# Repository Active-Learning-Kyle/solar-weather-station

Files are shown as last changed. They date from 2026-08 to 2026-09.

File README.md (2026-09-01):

# Solar Weather Station

<p align="center">
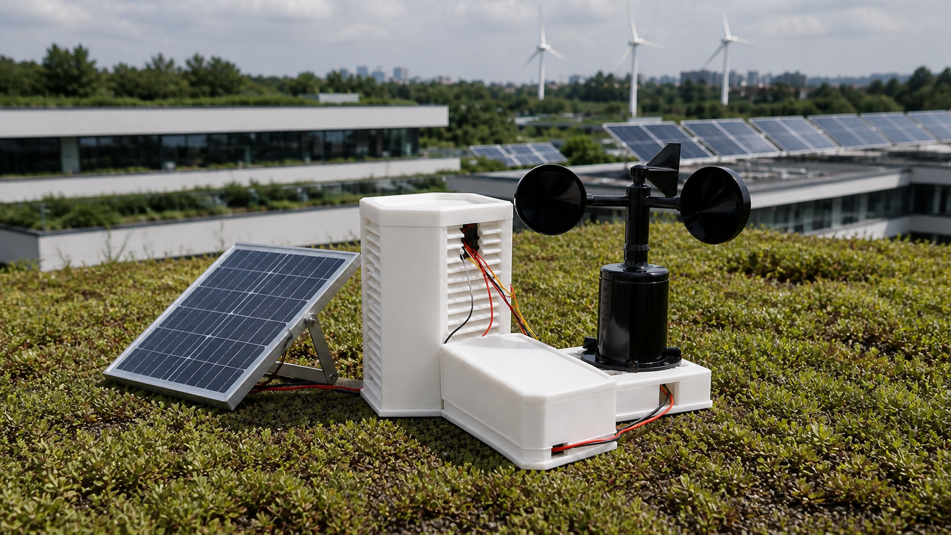
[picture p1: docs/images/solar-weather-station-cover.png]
Solar Weather Station prototype with its solar panel, cup anemometer and wind vane on a green rooftop
  
</p>

<p align="center">
  <strong>Make invisible microclimates visible—so greener campus decisions can be based on local evidence.</strong>
</p>

<p align="center">
  A solar-powered station for investigating how heat, light, particles and wind vary across the places where people study, work and grow plants.
</p>

<p align="center">
  
  
  
  
  
</p>

<p align="center"><sub>Application visualisation based on the completed prototype. Field performance still requires the tests described in this repository.</sub></p>

## The problem: one forecast cannot describe every place

A city-wide forecast can tell us the general weather, but it cannot describe every rooftop garden, shaded courtyard, workshop entrance or sun-heated wall. Two places only a short walk apart may experience different temperature, light, particles and wind. Without local evidence, decisions about shade, planting, ventilation, outdoor activities and equipment placement can easily be based on assumption.

That creates a more interesting engineering question than simply displaying sensor values:

> **Can a repairable, solar-powered station produce trustworthy local evidence for deciding where and when a campus space needs environmental improvement?**

The Solar Weather Station grew from that question. It is designed to compare conditions between small campus locations and over time, while keeping sensor failures and uncertainty visible. A useful outcome is not simply a dashboard: it is evidence that can support a specific decision, such as whether a rooftop growing area needs shade, whether a courtyard needs further heat investigation, or whether a proposed monitoring location is representative.

The aim is not to imitate a certified meteorological station or claim that one prototype solves urban climate change. The aim is to create an honest local evidence tool—one verified subsystem and one decision at a time.

## Green Technology and the SDGs

<table>
  <tr>
    <td align="center" width="33%">
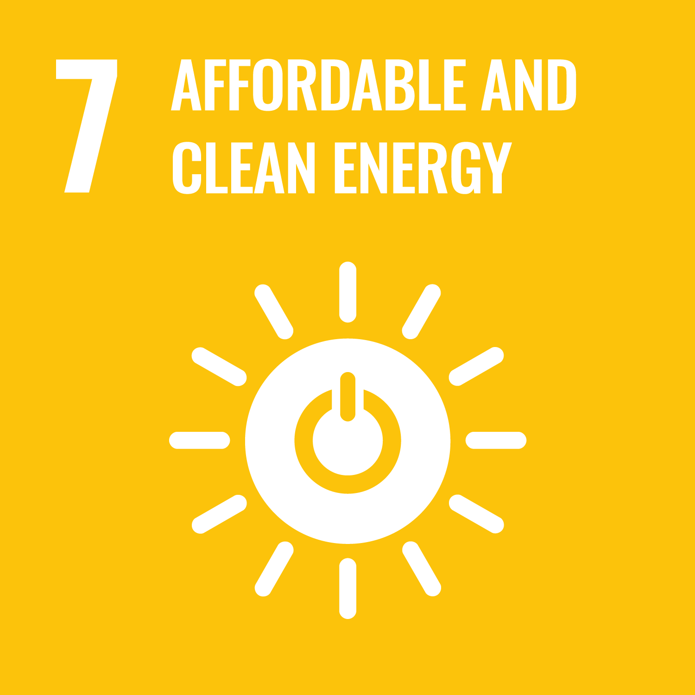
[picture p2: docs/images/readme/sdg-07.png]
SDG 7 Affordable and Clean Energy
      <br>
      <strong>SDG 7 · Affordable and Clean Energy</strong><br>
      <sub>The station tests whether local monitoring can run from a measured solar-energy budget. Power demand, charging loss and endurance are recorded before autonomy is claimed.</sub>
    </td>
    <td align="center" width="33%">
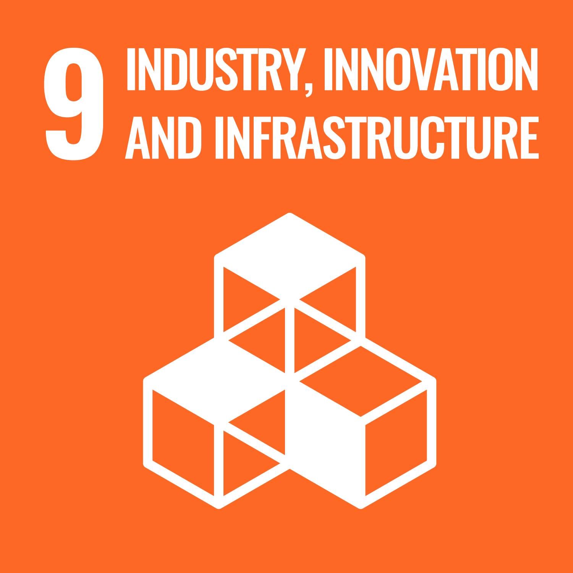
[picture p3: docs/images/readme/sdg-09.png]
SDG 9 Industry Innovation and Infrastructure
      <br>
      <strong>SDG 9 · Industry, Innovation and Infrastructure</strong><br>
      <sub>Editable CAD, modular firmware and an open data path make the monitoring infrastructure repairable, reproducible and adaptable to another site.</sub>
    </td>
    <td align="center" width="33%">
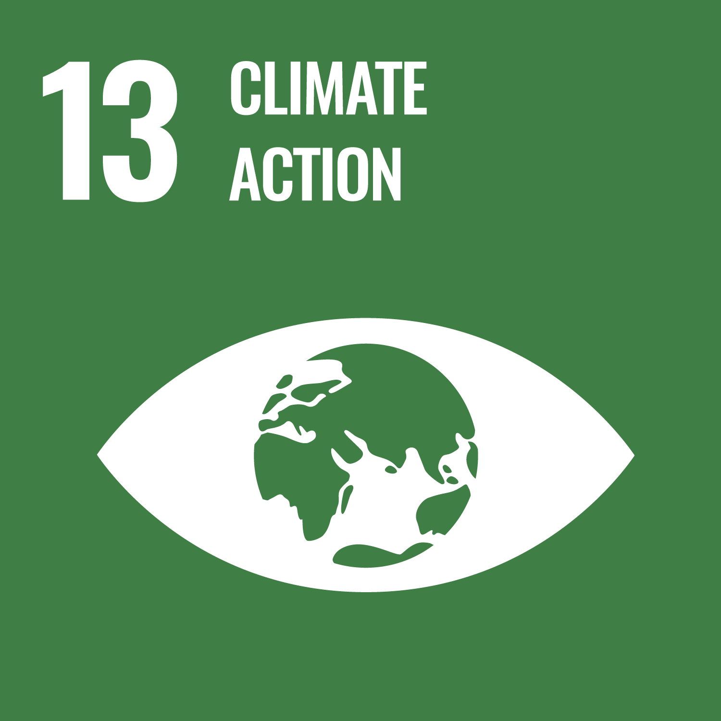
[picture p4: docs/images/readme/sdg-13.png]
SDG 13 Climate Action
      <br>
      <strong>SDG 13 · Climate Action</strong><br>
      <sub>Hyperlocal observations can reveal heat, exposure and weather patterns that inform a campus adaptation decision. Impact begins only when the evidence changes an action.</sub>
    </td>
  </tr>
</table>

Together, the three goals form one testable chain: **power the sensing responsibly (SDG 7), leave behind reusable monitoring infrastructure (SDG 9), and use its evidence to inform local climate adaptation (SDG 13).** Sustainability still depends on measured power, materials, repairability, useful lifetime, placement and a documented decision enabled by the data.

## From a physical prototype to usable evidence

<table>
  <tr>
    <td width="42%" valign="top">
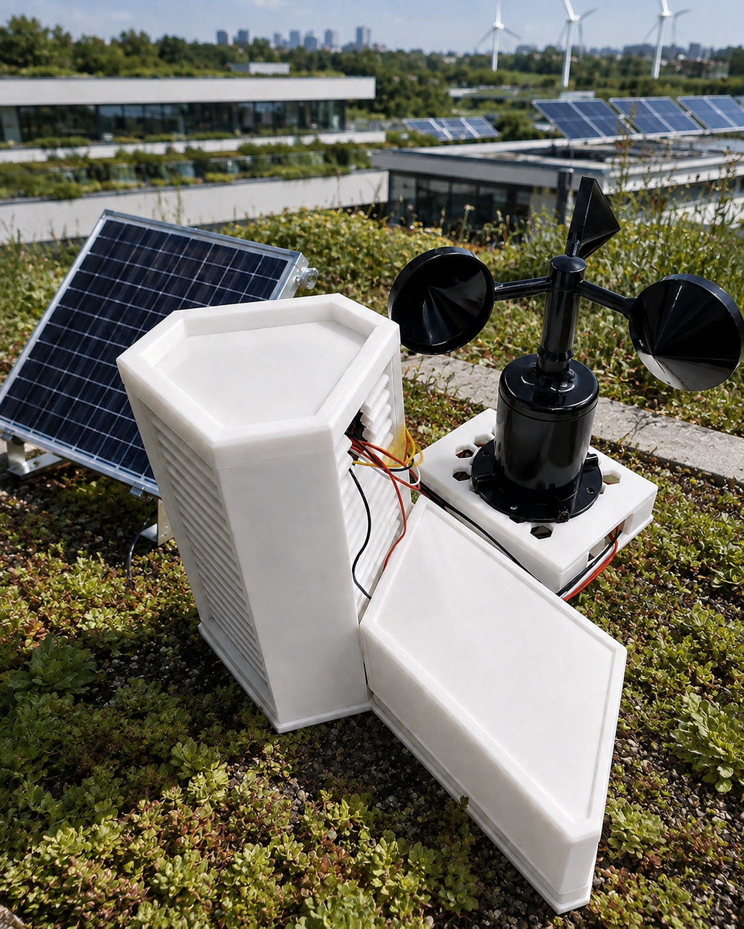
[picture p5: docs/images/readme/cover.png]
Completed white 3D-printed Solar Weather Station with RS485 wind sensor
      <br>
      <sub><strong>The physical system.</strong> A modular 3D-printed sensor body and power enclosure with an ESP32-S3, environmental sensors, GNSS and RS485 wind speed.</sub>
    </td>
    <td width="58%" valign="top">
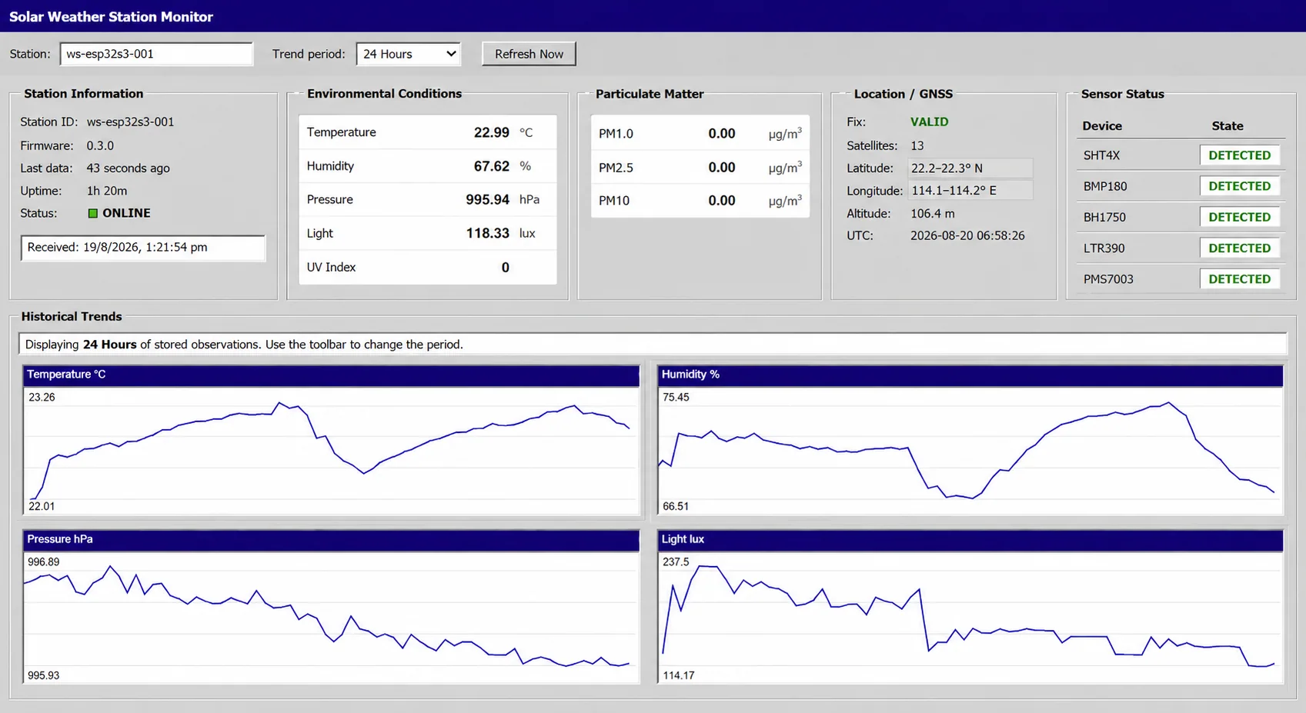
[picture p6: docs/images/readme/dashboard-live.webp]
Live Solar Weather Station dashboard with current readings, sensor status, GNSS and historical trends
      <br>
      <sub><strong>The data system.</strong> Current conditions, sensor health, GNSS state and historical trends served by FastAPI and SQLite.</sub>
    </td>
  </tr>
</table>

The station currently measures:

- temperature and relative humidity;
- barometric pressure;
- ambient light and an estimated UV index;
- PM1.0, PM2.5 and PM10 particulate concentration;
- GNSS communication, fix state, time, position, altitude, satellites and motion; and
- RS485 wind speed.

A valid calm wind reading of `0.0 m/s` remains different from a timeout. A missing GNSS fix remains different from a disconnected receiver. Each active sensor keeps its own initialized, valid, stale and failure state, so one failed device does not stop the rest of the station.

## How the complete system works

```mermaid
flowchart LR
    subgraph Station[ESP32-S3 station]
      I2C[SHT4x · BMP180<br/>BH1750 · LTR390]
      PMS[PMS7003]
      GPS[TEL0157 / L76K GNSS]
      WIND[RS485 wind speed]
      HEALTH[WeatherData<br/>validity + health]
      I2C --> HEALTH
      PMS --> HEALTH
      GPS --> HEALTH
      WIND --> HEALTH
    end

    HEALTH -->|USB Serial| OBSERVE[Bench diagnosis]
    HEALTH -->|Wi-Fi · JSON · HTTP| API[FastAPI validation]
    API --> DB[(SQLite history)]
    DB --> UI[Live dashboard<br/>and trends]
```

Sensor acquisition is scheduled independently of networking. Wi-Fi reconnects and uploads use bounded timing, so a missing backend does not stop local sensing. HTTP keeps the development path small and inspectable; it is not a claim of secure public-cloud deployment.

## Look inside, not only at the finished enclosure

<table>
  <tr>
    <td width="50%" valign="top">
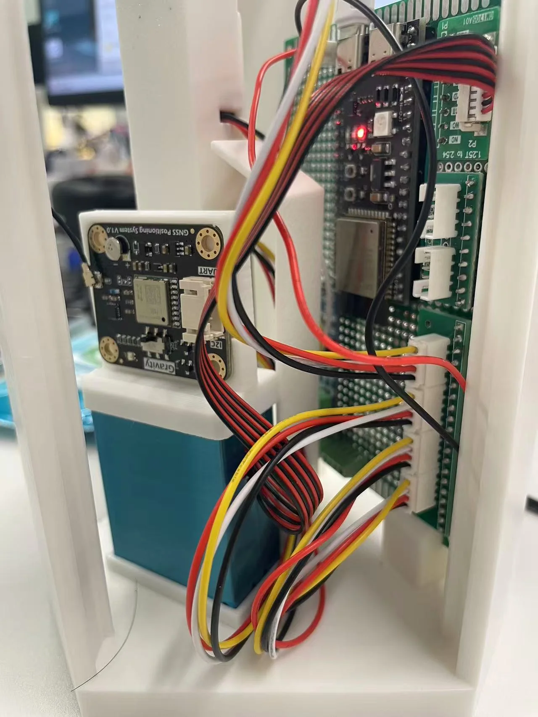
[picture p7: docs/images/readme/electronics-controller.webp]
ESP32-S3 controller, interface board and internal weather station wiring
      <br>
      <sub>ESP32-S3, interface board, connectors and routed sensor wiring inside the printed body.</sub>
    </td>
    <td width="50%" valign="top">
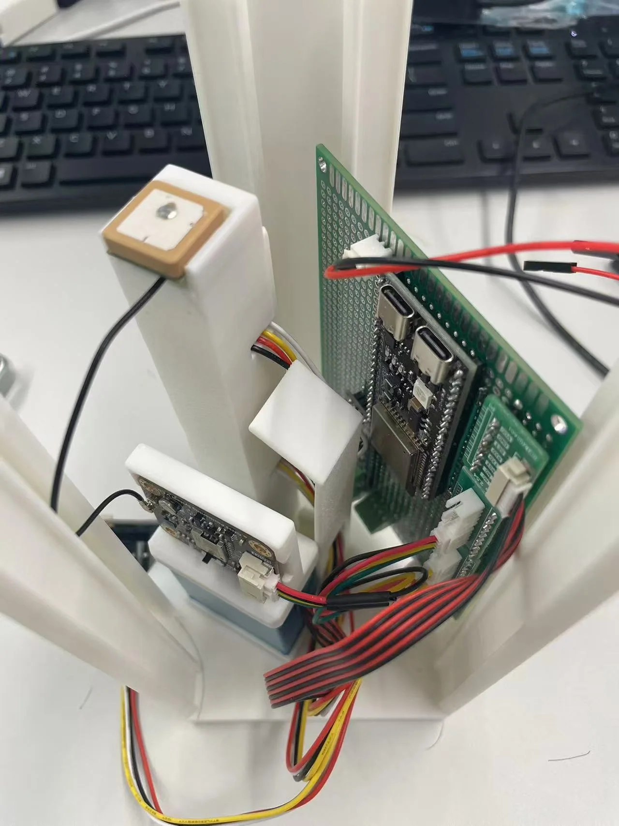
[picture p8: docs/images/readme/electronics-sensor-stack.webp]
Weather station internal GNSS and environmental sensor modules
      <br>
      <sub>GNSS and environmental sensing modules on printed mounts designed for inspection and replacement.</sub>
    </td>
  </tr>
</table>

The enclosure is organised as two connected modules:

1. the **Weather Station Body**, which holds sensing and control electronics; and
2. the **Power Module**, separated so that energy storage and charging can be revised without rebuilding the entire sensor body.

Exact breakout boards, voltage requirements, connector families and outdoor protection still need to be checked before reproducing the hardware. Start with the [bill of materials](hardware/bom.md), [wiring guide](hardware/wiring.md), [pin allocation](docs/pin-allocation.md) and [power notes](hardware/power-system.md).

## Designed to be changed

<p align="center">
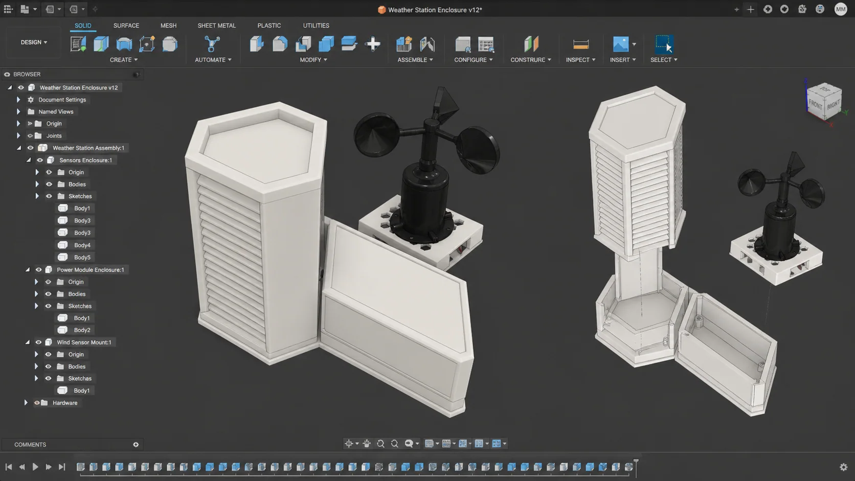
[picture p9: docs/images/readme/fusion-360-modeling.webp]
Fusion 360 design workspace showing the weather station enclosure, wind sensor mount and modular assembly
  
</p>

<p align="center"><sub>Design-process visualisation based on the included editable Fusion 360 models and the printed enclosure.</sub></p>

The repository includes editable `.f3d` source for the sensor body, vents, sensor rod, GNSS mount, power enclosure and connecting base. That matters because a reusable project should allow another team to change a mount, airflow path or cable route—not only print an uneditable final mesh.

<table>
  <tr>
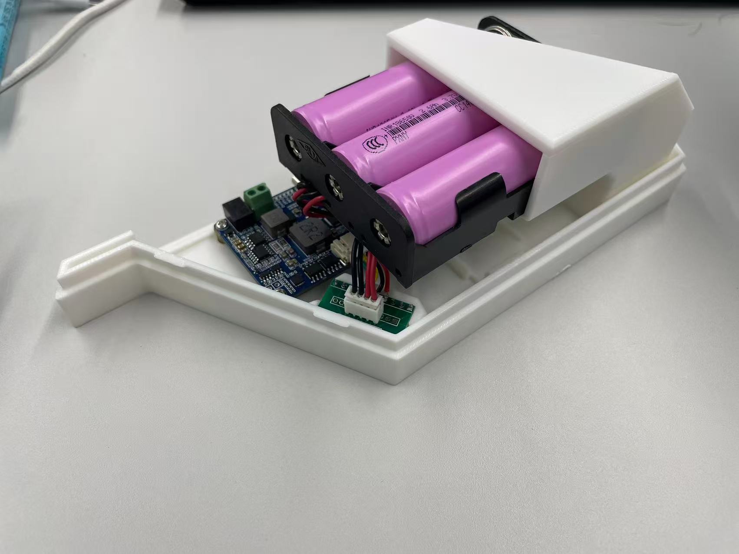
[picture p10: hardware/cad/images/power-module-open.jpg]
Open power module with battery and electronics
    <td width="50%"></td>
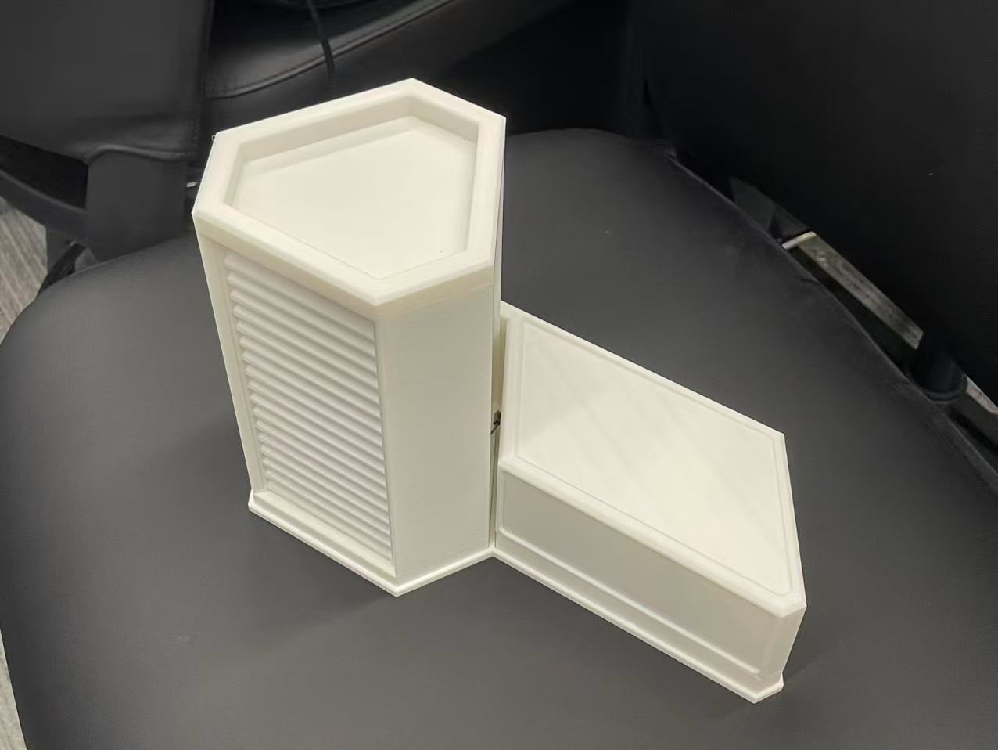
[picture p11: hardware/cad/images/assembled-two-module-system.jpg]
Printed weather station and power modules joined by the connecting base
    <td width="50%"></td>
  </tr>
  <tr>
    <td><sub>Power module opened for inspection.</sub></td>
    <td><sub>Printed modules assembled on the connecting base.</sub></td>
  </tr>
</table>

- Browse the [mechanical CAD catalogue](hardware/cad/README.md).
- Prepare the files with the [3D-printing guide](hardware/printing/README.md).
- Assemble the modules with the [mechanical assembly guide](hardware/printing/assembly-guide.md).

## Current release

**Core v0.4 integrates wind speed through the complete software path.** The standalone wind-speed diagnostic has been verified on hardware. The combined station still requires the documented full-system hardware test before v0.4 can be called field verified.

| Area | Current status | Evidence |
| --- | --- | --- |
| SHT4x, BMP180, BH1750, LTR390 and PMS7003 | **Hardware verified** | [Core v0.1 milestone](docs/milestones/v0.1-core-sensors.md) |
| Wi-Fi, HTTP, FastAPI, SQLite and dashboard | **Complete for Core v0.2** | [Core v0.2 milestone](docs/milestones/v0.2-connected-iot.md) |
| TEL0157/L76K GNSS | **Hardware verified and integrated** | [Core v0.3 milestone](docs/milestones/v0.3-gnss-integration.md) |
| RS485 wind speed | **Software integrated; combined hardware test pending** | [Core v0.4 milestone](docs/milestones/v0.4-wind-speed-integration.md) |
| RS485 wind direction | **Standalone diagnostic only** | [Firmware environments](#firmware-environments) |
| Mechanical enclosure and connecting base | **Printed and fit checked** | [Mechanical CAD](hardware/cad/README.md) |
| Rain, battery and solar telemetry | **Planned** | [Roadmap](#where-the-project-can-go-next) |
| Weatherproofing and long-duration outdoor operation | **Not yet verified** | [Field readiness](tests/field-readiness-checklist.md) |

The terms used throughout the repository have fixed meanings:

- **Planned:** no implementation is claimed.
- **Software implemented:** code exists and its software checks are stated.
- **Diagnostic available:** an isolated test exists; main-system integration is not implied.
- **Hardware verified:** the named behaviour was observed on the stated hardware using a recorded procedure.
- **Complete:** the acceptance result for the named milestone was observed.

## Build the software path

### 1. Clone the repository

```powershell
git clone https://github.com/Active-Learning-Kyle/solar-weather-station.git
cd solar-weather-station
```

### 2. Configure and build the ESP32-S3 firmware

Install [Visual Studio Code](https://code.visualstudio.com/) and [PlatformIO](https://platformio.org/), then create the ignored local secrets file:

```powershell
Copy-Item firmware/include/secrets.example.h firmware/include/secrets.h
```

Set the local Wi-Fi credentials and backend URL in `firmware/include/secrets.h`, then build:

```powershell
cd firmware
pio run -e weather_station
```

Upload and monitor when the hardware is connected:

```powershell
pio run -e weather_station -t upload
pio device monitor -b 115200
```

### 3. Start the local backend and dashboard

Open a second terminal from the repository root:

```powershell
cd backend
py -3.11 -m venv .venv
.\.venv\Scripts\python.exe -m pip install -r requirements.txt
.\.venv\Scripts\python.exe -m uvicorn app.main:app --host 0.0.0.0 --port 8000
```

Open [http://localhost:8000](http://localhost:8000). Interactive API documentation is available at [http://localhost:8000/docs](http://localhost:8000/docs).

### 4. Run the automated tests

```powershell
cd backend
.\.venv\Scripts\python.exe -m pytest -q
```

Continuous integration builds every PlatformIO environment and runs the backend test suite. A successful build proves that the software compiles; it does not replace hardware verification.

## Firmware environments

Run an isolated diagnostic before integrating a new or failing subsystem.

| Environment | Purpose |
| --- | --- |
| `weather_station` | Core v0.4 integrated firmware |
| `diag_i2c` | Detect the shared I²C sensors and addresses |
| `diag_pms` | Inspect PMS7003 frames, checksums and values |
| `diag_gnss` | Inspect GNSS communication, NMEA data and fix state |
| `diag_wind_speed` | Test the verified RS485 wind-speed protocol |
| `diag_wind_direction` | Preserve and investigate the wind-direction protocol |

For GNSS diagnostics:

```powershell
cd firmware
pio run -e diag_gnss -t upload
pio device monitor -b 115200
```

## Backend API

| Method | Endpoint | Purpose |
| --- | --- | --- |
| `POST` | `/api/v1/measurements` | Validate and store one station snapshot |
| `GET` | `/api/v1/measurements/latest?station=...` | Return the latest snapshot |
| `GET` | `/api/v1/measurements?station=...&start=...&end=...&limit=...` | Return filtered history, newest first |

The backend receive time controls storage order and dashboard freshness. Device time remains nullable until NTP succeeds. GNSS time is stored independently after a valid fix. Precise GNSS data must not be exposed through an untrusted network or published without review.

## Follow the engineering journey

The project records six connected decisions. Evidence may send the work back to an earlier Gate.

| Gate | Decision | Main record |
| ---: | --- | --- |
| 01 **Focus** | Which Green Technology challenge is worth pursuing? | [Challenge focus](docs/project-journey/01-focus.md) |
| 02 **Define** | What problem, user and evidence boundary define the work? | [Problem definition](docs/project-journey/02-define.md) |
| 03 **Plan** | Which architecture and validation route should be used? | [Proposal and plan](docs/project-journey/03-plan.md) |
| 04 **Learn** | What can be rebuilt and understood from existing open projects? | [Open references and working versions](docs/project-journey/04-learn.md) |
| 05 **Improve** | What should be adapted or improved for this problem, based on evidence? | [Testing and iteration](docs/project-journey/05-improve.md) |
| 06 **Contribute** | What can another person safely understand, reproduce and extend? | [Responsible release](docs/project-journey/06-contribute.md) |

The [project-journey index](docs/project-journey/README.md) connects these decisions to milestone records, code, CAD, tests and release checks.

### Learn from open work before designing from zero

This station was not developed in isolation. Three public projects were studied as working precedents:

- [SeBassTian23/ESP32-WeatherStation](https://github.com/SeBassTian23/ESP32-WeatherStation) showed how particulate matter, UV-related sensing, solar power and local logging can coexist in an ESP32 station.
- [cerevisis/ESP32-Weather-Station](https://github.com/cerevisis/ESP32-Weather-Station) demonstrated a device-hosted dashboard, historical records, sensor diagnostics and extensible weather interfaces.
- [maxmacstn/HA-SolarWeatherStation](https://github.com/maxmacstn/HA-SolarWeatherStation) provided a useful precedent for solar operation, deep sleep, battery-aware behaviour and separating sensing from the protected electronics enclosure.

The purpose of studying them was not to combine every feature. It was to rebuild enough of the established pattern to understand its trade-offs, then make a problem-specific improvement: explicit per-sensor health, a local inspectable data path, editable modular hardware and evidence boundaries that distinguish a real zero reading from missing or unverified data. Their code and hardware remain under their respective licences; this repository records the ideas studied and the new work developed here.

## Start with the part you want to change

| If you want to… | Start here |
| --- | --- |
| reproduce the current system | [Wiring](hardware/wiring.md) → [firmware setup](#build-the-software-path) → [backend](#3-start-the-local-backend-and-dashboard) |
| diagnose a missing sensor | [Firmware environments](#firmware-environments) → [troubleshooting](docs/troubleshooting.md) |
| understand a version | [Milestone records](docs/milestones/) → matching `core-v0.*.md` implementation notes |
| modify the enclosure | [CAD catalogue](hardware/cad/README.md) → [printing](hardware/printing/README.md) → [assembly](hardware/printing/assembly-guide.md) |
| design a field test | [Test matrix](tests/test-matrix.csv) → [field-readiness checklist](tests/field-readiness-checklist.md) |
| contribute a change | [Contributing guide](CONTRIBUTING.md) → open an Issue → submit a focused Pull Request |

## Evidence and claim boundaries

This repository distinguishes code, bench evidence and field evidence.

- Photographs show the named assembly or bench setup. They do not prove calibration, weatherproofing or long-term reliability.
- Automated tests validate API, storage, migration and dashboard behaviour. They do not prove sensor accuracy.
- A standalone diagnostic verifies one interface. It does not prove that the complete station works outdoors.
- The LTR390 value is an estimate from the current driver path, not a calibrated meteorological UV measurement.
- GNSS screenshots are redacted or reduced in precision before publication.
- Sustainability value must be supported by measured power, lifetime, repair and field evidence. The presence of a solar panel or SDG label is not proof of impact.

Use the [test matrix](tests/test-matrix.csv) to see which claims are supported, pending or explicitly outside the current release.

## Safety and privacy

Outdoor electrical systems, rechargeable cells, 12 V instruments, fabrication tools and elevated mounting introduce hazards. Use an approved site, named supervision, appropriate protection, strain relief, fusing, stop conditions and a safe retrieval plan. Do not energise an enclosure during a water-ingress test.

The backend is not hardened for the public internet. Keep it on a trusted network. Remove credentials, private endpoints and precise location data before sharing logs or screenshots. See [SECURITY.md](SECURITY.md) and the [field-readiness checklist](tests/field-readiness-checklist.md).

## Where the project can go next

The current system leaves several useful directions open:

- complete the Core v0.4 combined hardware verification;
- decide whether wind direction should enter the production data model;
- add rain, battery and solar telemetry after isolated tests pass;
- measure the complete power profile and solar energy balance;
- validate enclosure ingress, thermal behaviour and radiation shielding;
- compare selected measurements with a documented reference instrument;
- design a lower-power duty cycle for autonomous operation; or
- adapt the modular platform to a different local environmental question.

The most valuable next feature is not necessarily the most impressive one. It is the one supported by a clear need, a testable decision and evidence that changes what the team does next.

## Contributing

Contributions are welcome. Open an Issue for a bug, proposed subsystem or design decision, then use a focused branch and Pull Request. State what was compiled, simulated, bench tested or field tested. Do not describe planned work as verified.

Read [CONTRIBUTING.md](CONTRIBUTING.md), [AI_USE.md](AI_USE.md) and [THIRD_PARTY.md](THIRD_PARTY.md) before submitting a change.

## License

This project is released under the [MIT License](LICENSE). Third-party libraries remain under their own licences and are not relicensed by this repository. The editable source, evidence and known limitations are published so that another team can understand the work, reproduce what has been verified and improve it responsibly.

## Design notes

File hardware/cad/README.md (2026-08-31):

# Mechanical CAD index

The enclosure is a two-assembly prototype: the vertical **Weather Station Body** contains the ESP32-S3, sensor interfaces, PMS7003, GNSS hardware, and the sensor rod; the horizontal **Power Module** contains the 18650 battery pack, Waveshare Solar Power Manager (D), and XL6009 DC-DC module. The two assemblies are joined by a **Connecting Base**.

Printed weather-station body and power module joined as one prototype

The ten editable source models are Autodesk Fusion 360 archives (`.f3d`). Fusion 360 is the released editable format so builders can inspect and modify the design. No STL, 3MF, or STEP exports were supplied. Open a model in Fusion 360, confirm its document units, and export a mesh for your slicer without changing scale.

## Directory layout

```text
hardware/cad/
├── station-body/       # seven editable station-body parts
├── power-module/       # mount and cover
├── assembly/           # editable connecting base and part documentation
└── images/             # CAD previews and physical-build evidence
```

## Part catalog

“Photo assembled” means the part is visible or its installed function is evidenced in the supplied prototype photographs. It is not a dimensional inspection or a field-weatherproofing claim.

| Assembly | Part | Qty. | Editable CAD | Preview | Function | Evidence status |
| --- | --- | ---: | --- | --- | --- | --- |
| Weather Station Body | Main body shell | 1 | [`station-body/main-body-shell.f3d`](station-body/main-body-shell.f3d) | [`main-body-shell-cad.png`](images/main-body-shell-cad.png) | Primary vertical enclosure and internal mounting structure | Photo assembled |
| Weather Station Body | Lid | 1 | [`station-body/lid.f3d`](station-body/lid.f3d) | [`lid-cad.png`](images/lid-cad.png) | Closes the top of the main shell | Photo assembled |
| Weather Station Body | Vent | 3 | [`station-body/vent.f3d`](station-body/vent.f3d) | [`vent-cad.png`](images/vent-cad.png) | Inserts into the three open sides of the shell | Photo assembled; weatherproofing not validated |
| Weather Station Body | Sensor rod | 1 | [`station-body/sensor-rod.f3d`](station-body/sensor-rod.f3d) | [`sensor-rod-cad.png`](images/sensor-rod-cad.png) | Holds the smaller environmental sensors; GNSS antenna sits at the top | Photo assembled |
| Weather Station Body | Sensor-rod lid | 1 | [`station-body/sensor-rod-lid.f3d`](station-body/sensor-rod-lid.f3d) | [`sensor-rod-lid-cad.png`](images/sensor-rod-lid-cad.png) | Fits into the sensor rod to stabilize installed sensors | Included in source; not independently visible in the photos |
| Weather Station Body | Cable slot | 1 | [`station-body/cable-slot.f3d`](station-body/cable-slot.f3d) | [`cable-slot-cad.png`](images/cable-slot-cad.png) | Organizes sensor wiring | Included in source; not independently identifiable in the photos |
| Weather Station Body | GNSS mount | 1 | [`station-body/gnss-mount.f3d`](station-body/gnss-mount.f3d) | [`gnss-mount-cad.png`](images/gnss-mount-cad.png) | Supports the GNSS board above the PMS7003 | Photo assembled |
| Power Module | Power-module mount | 1 | [`power-module/power-module-mount.f3d`](power-module/power-module-mount.f3d) | [`power-module-mount-cad.png`](images/power-module-mount-cad.png) | Holds the battery pack and power boards | Photo assembled |
| Power Module | Power-module cover | 1 | [`power-module/power-module-cover.f3d`](power-module/power-module-cover.f3d) | [`power-module-cover-cad.png`](images/power-module-cover-cad.png) | Closes the power-module mount | Photo assembled |
| Combined assembly | Connecting base | 1 | [`assembly/connecting-base.f3d`](assembly/connecting-base.f3d) | [`connecting-base-cad.png`](images/connecting-base-cad.png) | Joins the station body to the power module | Designed, printed, fit verified, and integrated |

## Printing rule

Every released part in the catalog is printed in PLA using the normal/default PLA profile with supports enabled. The Power Module Mount is the sole documented material exception: its model remains PLA, while its support system uses the dedicated `Support for PLA` material. No support-interface configuration or numeric slicer settings are specified because none were supplied.

## Source-name normalization

The supplied files were copied into the repository with descriptive, lowercase, hyphenated names. The source folder remains unchanged.

| Supplied name | Repository name |
| --- | --- |
| `mainbodyshell.f3d` | `station-body/main-body-shell.f3d` |
| `Lid.f3d` | `station-body/lid.f3d` |
| `vent.f3d` | `station-body/vent.f3d` |
| `sensorrod.f3d` | `station-body/sensor-rod.f3d` |
| `rodlid.f3d` | `station-body/sensor-rod-lid.f3d` |
| `cableslot.f3d` | `station-body/cable-slot.f3d` |
| `gpsmount.f3d` | `station-body/gnss-mount.f3d` |
| `powermodulemount.f3d` | `power-module/power-module-mount.f3d` |
| `powermodulecover.f3d` | `power-module/power-module-cover.f3d` |
| `connectbase.f3d` | `assembly/connecting-base.f3d` |

## Visual evidence

- [`station-body-assembled-front.jpg`](images/station-body-assembled-front.jpg) — completed station-body exterior.
- [`station-body-internal-sensors.jpg`](images/station-body-internal-sensors.jpg) — sensor rod and PMS7003/GNSS area.
- [`station-body-internal-electronics.jpg`](images/station-body-internal-electronics.jpg) — installed ESP32-S3, interface board, and wiring.
- [`power-module-open.jpg`](images/power-module-open.jpg) — battery pack and power electronics on the open mount.
- [`power-module-closed.jpg`](images/power-module-closed.jpg) — installed cover.
- [`assembled-two-module-system.jpg`](images/assembled-two-module-system.jpg) — both assemblies joined by the printed connecting base.

The physical photographs and connecting-base render were extracted from the supplied 14-page Word reference. The individual CAD previews came from the matching source-folder screenshots.

## Known gaps

- Record Fusion document units and export tested STL or 3MF files before calling the print package turnkey-reproducible.
- Record dimensions, tolerances, fastening/adhesive method, print orientation, and slicer settings after a controlled reprint.
- Validate enclosure drainage, sealing, UV/heat resistance, and long-duration outdoor fit. The reference calls the vents waterproof, but no test evidence supports that claim.
- Confirm whether future manufacturing exports need a dedicated open-hardware licence in addition to the repository-wide MIT License. Until that decision is recorded, describe the editable CAD as source material rather than a certified, turnkey open-hardware package.

See the [printing guide](../printing/README.md), [assembly guide](../printing/assembly-guide.md), and milestone records for [v0.1](../../docs/milestones/v0.1-core-sensors.md), [v0.2](../../docs/milestones/v0.2-connected-iot.md), and [v0.3](../../docs/milestones/v0.3-gnss-integration.md).

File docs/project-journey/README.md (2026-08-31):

# Project Journey

The Solar Weather Station develops through six connected engineering decisions. The Gates are not a one-way checklist. New evidence can change an earlier problem statement, architecture choice, test or release decision.

| Gate | Decision | Current outcome |
| ---: | --- | --- |
| [01 Focus](01-focus.md) | Which Green Technology challenge should the project pursue? | Build an inspectable local microclimate platform while keeping sustainability claims evidence based |
| [02 Define](02-define.md) | What problem, user and boundary define useful work? | Support supervised, site-specific observation and engineering validation; do not claim meteorological-grade accuracy |
| [03 Plan](03-plan.md) | Which system architecture and validation route are responsible? | Modular ESP32-S3 sensing, isolated diagnostics, local backend and staged integration |
| [04 Learn](04-learn.md) | What did each working version teach? | Four milestones moved from core sensors to connected data, GNSS and wind speed |
| [05 Improve](05-improve.md) | What does the evidence justify changing next? | Finish combined v0.4 verification before adding new field features |
| [06 Contribute](06-contribute.md) | What is safe, clear and useful to release? | Publish source, editable CAD, tests, evidence, limits and contribution rules under an open licence |

## Evidence path

```mermaid
flowchart LR
    F[Focus] --> D[Define]
    D --> P[Plan]
    P --> L[Learn]
    L --> I[Improve]
    I --> C[Contribute]
    I -. new evidence .-> D
    C -. reproduction feedback .-> P
```

The detailed implementation record remains chronological under [`docs/milestones/`](../milestones/). The Gate documents explain the decisions across those versions; the milestone documents show what was built and observed at each stage.

## How to read the evidence

- **Source code** shows an implementation, not physical performance.
- **Automated tests** show that software behavior meets the checked conditions.
- **Diagnostic logs and bench photographs** support the named subsystem test.
- **Integrated hardware evidence** supports only the configuration and procedure recorded in that milestone.
- **Field claims** require an approved site, versioned configuration, raw observations, reference information and a recorded decision.

The [system test matrix](../../tests/test-matrix.csv) is the index of supported and pending claims.

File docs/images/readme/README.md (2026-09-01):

# README Visual Assets

This folder separates project evidence from explanatory visualisations.

## Project photographs and interface capture

- `cover.png` — completed physical prototype supplied by the project owner.
- `dashboard-live.webp` — live project dashboard capture supplied by the project owner.
- `electronics-controller.webp` — internal controller, interface board and wiring photograph supplied by the project owner.
- `electronics-sensor-stack.webp` — internal GNSS and sensor-mount photograph supplied by the project owner.

These images document the visible configuration only. They do not by themselves prove calibration, weatherproofing, field reliability or solar autonomy.

## Explanatory visualisations

- `application-rooftop.webp` — AI-generated application visualisation derived from the completed-prototype photograph. It illustrates an intended supervised rooftop use case and is not field-test evidence.
- `fusion-360-modeling.webp` — AI-generated design-process visualisation derived from the printed enclosure and assembled prototype. The repository's `.f3d` files, not the visualisation, are the editable CAD source.

Both visualisations were reviewed against the supplied prototype references before publication. No generated visual is used as evidence in the test matrix.

## SDG communication assets

- `sdg-07.png`, `sdg-09.png` and `sdg-13.png` come from the United Nations Sustainable Development communications materials.
- Source: <https://www.un.org/sustainabledevelopment/news/communications-material/>
- Use must follow the UN SDG logo, colour wheel and icon guidelines linked on that page.
- Inclusion does not imply United Nations endorsement or prove project impact.

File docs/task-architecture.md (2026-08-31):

# FreeRTOS Task Architecture (Early Proposal)

> **Status:** Historical/planned design, not the v0.3 runtime architecture. The current implementation uses the `main.cpp` scheduler plus dedicated HTTP-upload and GNSS workers. See the [README architecture](../README.md#architecture) and [v0.3 milestone](milestones/v0.3-gnss-integration.md).

## Data Flow

```text
Sensor drivers
    ↓
SensorManagerTask / WindPollTask / RainTask
    ↓
WeatherData queue + latest reading mutex
    ↓
StatisticsTask ──→ hourly/daily aggregates
    ↓
DataLoggerTask ──→ CSV/JSON storage
    ↓
CommunicationTask ──→ MQTT + REST sync
    ↓
Dashboard API ──→ browser UI
```

## Shared Data Objects

```cpp
struct WeatherData
{
    float temperature;
    float humidity;
    float pressure;
    float lightLux;
    float uvIndex;
    float pm1_0;
    float pm2_5;
    float pm10;
    float windSpeed;
    float windDirection;
    float rainfall;
    double latitude;
    double longitude;
    uint64_t timestamp;
};
```

Recommended synchronization:

| Shared Resource | Protection |
| --- | --- |
| Latest `WeatherData` | Mutex |
| Log queue | FreeRTOS queue |
| MQTT publish queue | FreeRTOS queue |
| Rain pulse counter | ISR-safe atomic or critical section |
| Sensor diagnostics | Mutex or immutable snapshot queue |
| Configuration | Preferences with mutex |

## Task Details

| Task | Trigger | Output |
| --- | --- | --- |
| SensorManagerTask | 30 s periodic timer | Latest weather snapshot, publish/log queue entries |
| WindPollTask | 10 s periodic timer | Wind speed/direction fields |
| RainTask | 10 s periodic timer plus ISR count | Rain rate, daily/monthly accumulation |
| StatisticsTask | 60 s periodic timer | Hourly and daily rollups |
| DataLoggerTask | Queue-driven | CSV/JSON files |
| CommunicationTask | Queue-driven plus reconnect timer | MQTT publishes and NTP updates |
| WebServerTask | HTTP events | Dashboard/API responses |
| OtaTask | HTTP/OTA events | Firmware update |
| SystemHealthTask | 30 s periodic timer | Diagnostics and status payload |

## Timing Rules

- Use `vTaskDelayUntil()` for periodic tasks.
- Avoid blocking delays in sensor drivers.
- PMS7003 may need wake and stabilization timing; model this with a small state machine.
- RS485 polling should include timeouts and retries without blocking the full sensor manager.
- Network reconnects should use exponential backoff.

## Failure Handling

| Failure | Behavior |
| --- | --- |
| Sensor read timeout | Keep previous valid value, flag diagnostic warning |
| Sensor repeated failure | Mark sensor error, continue system operation |
| WiFi disconnected | Buffer readings locally, reconnect with backoff |
| MQTT unavailable | Continue REST/dashboard, queue or drop by policy |
| Storage full | Rotate logs or delete oldest day |
| Invalid NTP time | Use monotonic timestamp and mark time unsynced |

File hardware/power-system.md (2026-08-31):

# Power System Notes

> **Status:** preliminary design direction. The battery configuration, charger, panel and 12 V conversion path have not completed a measured complete-system power or endurance test.

## Battery

Three 18650 cells in 1S3P:

```text
Nominal voltage: 3.7V
Capacity: about 10200mAh
```

## Solar Charging

Waveshare Solar Power Manager (D):

- USB-C input
- Solar input
- 5V system output
- Power path management
- Simultaneous charge and discharge

## Solar Panel

Planning starting point:

```text
6V 5W
```

## Power Budget Items To Measure

| Load | Voltage | Notes |
| --- | ---: | --- |
| ESP32-S3 active WiFi | 5V input | Major peak current source |
| I2C sensors | 3.3V | Low current |
| PMS7003 | 5V | Use sleep mode |
| GPS | 3.3V/5V | Module-dependent |
| RS485 wind sensors | 12V | Needs boost conversion |
| RS485 transceiver | 3.3V | Low current |

## Evidence required before autonomous operation

1. Record active, idle and peak current for the complete integrated station.
2. Measure each controllable subsystem state rather than relying on datasheet typical values.
3. Include regulator, boost-converter and charging losses.
4. Run a protected battery-only endurance test with recovery and stop conditions.
5. Measure solar input under the intended placement and operating schedule.
6. Compare daily usable energy with the measured load and an explicit reserve margin.
7. Record battery protection, fusing, temperature limits and enclosure ventilation.

Until these checks are complete, the station is a bench-powered prototype and the presence of a solar panel is not evidence of autonomous or sustainable operation.

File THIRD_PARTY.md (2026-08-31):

# Third-Party Dependencies

The repository contains original project source and documentation under the MIT License. Package managers download the dependencies below from their upstream projects. Those dependencies keep their own copyright and licence terms; the project MIT License does not replace them.

## Firmware libraries

| Dependency | Purpose | Upstream |
| --- | --- | --- |
| Adafruit SHT4x Library | Temperature and humidity | <https://github.com/adafruit/Adafruit_SHT4X> |
| Adafruit BMP085 Library | BMP180 pressure interface | <https://github.com/adafruit/Adafruit-BMP085-Library> |
| BH1750 | Ambient-light sensing | <https://github.com/claws/BH1750> |
| Adafruit LTR390 Library | UV and ambient-light sensing | <https://github.com/adafruit/Adafruit_LTR390> |
| TinyGPSPlus | NMEA parsing | <https://github.com/mikalhart/TinyGPSPlus> |
| DFRobot_GNSS | TEL0157/L76K interface | <https://github.com/DFRobot/DFRobot_GNSS> |
| ArduinoJson | JSON serialization | <https://github.com/bblanchon/ArduinoJson> |
| ModbusMaster | Modbus RTU communication | <https://github.com/4-20ma/ModbusMaster> |
| Espressif Arduino core and PlatformIO platform | ESP32-S3 framework and build tooling | <https://github.com/espressif/arduino-esp32> |

Exact resolved versions are recorded by PlatformIO under the local build environment. Before a tagged release, record or lock versions needed for reproducibility and review each upstream licence.

## Backend dependencies

| Dependency | Purpose | Upstream |
| --- | --- | --- |
| FastAPI | API and static application | <https://github.com/fastapi/fastapi> |
| Uvicorn | ASGI development server | <https://github.com/encode/uvicorn> |
| Pydantic | Measurement validation | <https://github.com/pydantic/pydantic> |
| HTTPX | API test client | <https://github.com/encode/httpx> |
| pytest | Automated tests | <https://github.com/pytest-dev/pytest> |

## Communication assets

The README uses the official SDG 7, 9 and 13 web icons from the [United Nations Sustainable Development communications materials](https://www.un.org/sustainabledevelopment/news/communications-material/). The icons retain their own terms and must be used in accordance with the UN SDG logo, colour wheel and icon guidelines. Their inclusion does not imply United Nations endorsement.

Project photographs and generated explanatory visuals are documented separately in [`docs/images/readme/README.md`](docs/images/readme/README.md).

## Contribution rule

Do not paste external code, CAD, media or datasets into the repository without recording the source, exact version, licence and required attribution. A public URL alone is not permission to reuse the material.

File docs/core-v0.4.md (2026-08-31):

# Core v0.4 — Wind Speed Integration

**Status:** Production integration implemented and compile/test verified. The standalone `diag_wind_speed` configuration is hardware verified; complete-station hardware verification remains to be performed.

Core v0.4 integrates wind speed only and preserves wind direction as deferred diagnostic work.

## Architecture and UART allocation

```text
Wind-speed sensor -> RS485 transceiver -> RS485Manager -> WeatherData
                  -> JSON -> HTTP -> FastAPI -> SQLite -> dashboard/trends
```

| Function | Production interface |
| --- | --- |
| Debug console | Native USB CDC `Serial`, 115200 baud |
| PMS7003 | UART2, GPIO16 RX / GPIO17 TX, 9600 8N1 |
| TEL0157/L76K GNSS | UART1, GPIO15 RX / GPIO14 TX, 9600 baud |
| RS485 wind speed | UART0, GPIO6 RX / GPIO7 TX, GPIO5 DE/RE, 4800 8N1 |

`weather_station` enables native USB CDC so UART0 can serve RS485 without corrupting Serial Monitor output. `diag_wind_speed` remains on its verified UART1 allocation because GNSS is not initialized in that isolated environment.

## Fixed Modbus configuration

- slave ID `1`;
- function `0x03` (Read Holding Registers);
- register `0x0000`;
- register count `1`;
- scale `raw / 10.0`;
- authoritative unit `m/s`;
- two-second production polling interval in a dedicated `rs485-wind` worker task.

Before transmission, `RS485Manager` drives DE/RE HIGH. Its post-transmission callback flushes the UART, then returns DE/RE LOW so the transceiver normally remains in receive mode.

## Data, health, and failures

`WeatherData` carries `windSpeed`, `windSpeedLastModbusResult`, and `windSpeedHealth`. Health records initialized state, current validity, stale state, total and consecutive failures, and last successful read uptime. The last successful numeric reading is retained internally, but it is serialized only while the current reading is valid and fresh.

This distinction is intentional:

```text
successful raw 0 -> 0.0 m/s (valid)
Modbus timeout   -> null / unavailable (invalid)
```

A failed read changes only wind validity and counters. Blocking Modbus work stays in the dedicated RS485 worker; `main.cpp` copies a short locked snapshot. A timeout therefore does not reboot the ESP32 or hold up I²C, PMS, GNSS coordination, networking, upload scheduling, storage, or dashboard operation. The next scheduled transaction automatically attempts recovery.

## JSON, backend, and storage

The additive `weather.measurement.v1` payload extension is:

```json
{
  "wind": {
    "speed_mps": 3.6,
    "status": "OK",
    "last_modbus_result": 0
  },
  "health": {
    "wind_speed": {
      "initialized": true,
      "valid": true,
      "stale": false,
      "consecutive_failures": 0,
      "total_failures": 0
    }
  }
}
```

Unavailable speed is `null`; status can be `OK`, `CHECK`, `TIMEOUT`, `STALE`, or `NOT CONNECTED`. FastAPI defaults a missing wind object and missing wind health to an unavailable state, retaining compatibility with v0.1–v0.3 payloads.

SQLite startup adds only missing nullable `wind_speed_mps`, `wind_status`, `wind_last_modbus_result`, and `wind_speed_valid` columns with `ALTER TABLE`. It never deletes or recreates `weather.db`; old records return `NULL` speed and `NOT CONNECTED` status.

## Display

The Serial snapshot includes a Wind group plus wind health/Modbus state. The Windows-98-style dashboard adds a compact Wind fieldset, a Wind Speed entry in Sensor Status, and a `Wind Speed (m/s)` line chart using the existing 1-hour, 24-hour, and 7-day trend path.

Wind direction is not serialized, stored, displayed, or plotted. No placeholder `0°` value or compass is present.

## Hardware verification procedure

1. Connect all existing station hardware.
2. Power the 12 V wind-speed sensor correctly.
3. Flash `weather_station`.
4. Confirm environmental, PMS7003, and GNSS functions remain active.
5. Confirm wind speed reads approximately zero/low while stationary.
6. Spin the anemometer or apply airflow.
7. Confirm the Serial wind-speed value increases.
8. Confirm the dashboard updates after the next upload.
9. Confirm SQLite and the latest API contain the wind value.
10. Stop the sensor and confirm it returns toward zero.
11. Briefly disconnect RS485 A/B.
12. Confirm wind becomes unavailable/TIMEOUT without affecting other sensors.
13. Reconnect A/B.
14. Confirm wind communication recovers automatically without rebooting.

## Deferred work

- wind direction (standalone diagnostic preserved);
- rain;
- battery telemetry;
- solar telemetry;
- final power optimization and long-duration field reliability.

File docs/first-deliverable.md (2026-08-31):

# First Deliverable: Architecture Review Pack (Historical)

> **Historical design record:** This document contains early proposed structure and capabilities, not the current implementation. For verified status use the [README](../README.md) and [milestone records](milestones/). MQTT, forecasting, rain, power telemetry, GNSS, wind, SD logging, OTA, and several proposed folders below are not implemented in the v0.2 production prototype.

## 1. Complete Project Folder Structure

```text
Weather Station Project/
├── README.md
├── backend/
│   ├── app/
│   │   ├── api/
│   │   ├── db/
│   │   ├── ingest/
│   │   ├── ml/
│   │   └── services/
│   ├── tests/
│   └── requirements.txt
├── data/
│   ├── exports/
│   ├── samples/
│   └── weather.sqlite
├── docs/
│   ├── first-deliverable.md
│   ├── mqtt-and-json.md
│   ├── pin-allocation.md
│   └── task-architecture.md
├── firmware/
│   ├── include/
│   │   ├── app_config.h
│   │   ├── weather_data.h
│   │   ├── sensor_status.h
│   │   └── pins.h
│   ├── lib/
│   │   ├── sensors/
│   │   ├── communication/
│   │   ├── logging/
│   │   ├── statistics/
│   │   └── web/
│   ├── src/
│   │   ├── main.cpp
│   │   └── tasks/
│   ├── test/
│   └── platformio.ini
├── frontend/
│   ├── static/
│   │   ├── css/
│   │   └── js/
│   └── templates/
└── hardware/
    ├── bom.md
    ├── wiring.md
    └── power-system.md
```

Implementation note: the physical workspace currently contains the major folders and documentation scaffold. Nested module files should be added after architecture review.

## 2. ESP32-S3 Pin Allocation

Primary pin table is in [pin-allocation.md](pin-allocation.md).

Design assumptions:

- One shared I2C bus for SHT40, BMP180, BH1750, and LTR390.
- Separate UARTs for PMS7003, NEO-M8N GPS, and RS485 Modbus when available.
- RS485 wind speed and direction sensors share one Modbus RTU bus with distinct slave IDs.
- Rain gauge uses an interrupt-capable GPIO with internal or external pull-up.
- 12V wind sensors require a separate boost converter or 12V rail controlled from the ESP32 through a MOSFET/load switch.

## 3. FreeRTOS Task Architecture

The proposed task model is in [task-architecture.md](task-architecture.md).

High-level tasks:

| Task | Period | Priority | Core | Responsibilities |
| --- | ---: | ---: | ---: | --- |
| SensorManagerTask | 30 s base loop | 3 | 1 | Read environmental sensors, coordinate PMS/GPS/wind polling, validate readings |
| WindPollTask | 10 s | 4 | 1 | Poll RS485 wind speed and direction sensors |
| RainGauge ISR + RainTask | Event + 10 s | ISR/3 | 1 | Count pulses, debounce, calculate rainfall rate and accumulation |
| StatisticsTask | 60 s | 2 | 1 | Hourly/daily averages, min/max, rainfall totals |
| CommunicationTask | 10 s / event | 3 | 0 | WiFi, MQTT, REST, NTP sync, reconnect logic |
| DataLoggerTask | 60 s | 2 | 1 | Store CSV/JSON to SD or LittleFS |
| WebServerTask | Event-driven | 2 | 0 | Serve dashboard and API endpoints |
| OtaTask | Event-driven | 2 | 0 | Handle OTA update flow |
| SystemHealthTask | 30 s | 1 | 0 | Heap, uptime, WiFi RSSI, sensor diagnostics |

## 4. Sensor Driver Abstraction Layer

Use a common interface so tasks do not depend directly on individual sensor libraries.

```cpp
enum class SensorState
{
    NotInitialized,
    Ready,
    Warning,
    Error,
    Sleeping
};

struct SensorDiagnostic
{
    const char* name;
    SensorState state;
    uint32_t lastReadMs;
    uint32_t errorCount;
    const char* lastError;
};

class ISensor
{
public:
    virtual ~ISensor() = default;
    virtual bool begin() = 0;
    virtual bool read(WeatherData& data) = 0;
    virtual SensorDiagnostic diagnostic() const = 0;
};
```

Recommended concrete classes:

| Class | Source File | Interface | Notes |
| --- | --- | --- | --- |
| Sht40Sensor | `src/sensors/Sht40Sensor.*` | I2C | Temperature and humidity |
| Bmp180Sensor | `src/sensors/Bmp180Sensor.*` | I2C | Pressure and sensor temperature |
| Bh1750Sensor | `lib/sensors/Bh1750Sensor.*` | I2C | Lux |
| Ltr390Sensor | `lib/sensors/Ltr390Sensor.*` | I2C | UV index and raw UV |
| Pms7003Sensor | `lib/sensors/Pms7003Sensor.*` | UART | Sleep/wake support |
| GpsSensor | `lib/sensors/GpsSensor.*` | UART | Latitude, longitude, UTC, altitude |
| ModbusWindSensor | `lib/sensors/ModbusWindSensor.*` | RS485 | Wind speed and direction via slave IDs |
| RainGauge | `lib/sensors/RainGauge.*` | GPIO interrupt | Pulse counting and accumulation |

## 5. PlatformIO Configuration

Current config is in [firmware/platformio.ini](../firmware/platformio.ini).

Target environment:

- Platform: Espressif 32
- Board: ESP32-S3 DevKitC-1 class board
- Framework: Arduino
- Filesystem: LittleFS initially, SD card optional
- Monitor speed: 115200
- OTA: enabled later through `ArduinoOTA` or authenticated HTTP update endpoint

## 6. MQTT Topic Structure

The earlier MQTT/schema proposal is in [mqtt-and-json.md](mqtt-and-json.md).

Base topic:

```text
weather-station/{station_id}
```

Topics:

```text
weather-station/{station_id}/telemetry/current
weather-station/{station_id}/telemetry/air
weather-station/{station_id}/telemetry/wind
weather-station/{station_id}/telemetry/rain
weather-station/{station_id}/status
weather-station/{station_id}/diagnostics
weather-station/{station_id}/config/get
weather-station/{station_id}/config/set
weather-station/{station_id}/ota/status
```

## 7. JSON Payload Schema

Canonical current weather payload:

```json
{
  "station_id": "ws-esp32s3-001",
  "timestamp": 1717800000000,
  "temperature_c": 28.4,
  "humidity_pct": 74.2,
  "pressure_hpa": 1008.6,
  "light_lux": 12500.0,
  "uv_index": 5.2,
  "pm1_0_ugm3": 4.0,
  "pm2_5_ugm3": 8.0,
  "pm10_ugm3": 14.0,
  "wind_speed_ms": 3.1,
  "wind_direction_deg": 142.0,
  "rainfall_mm": 0.2,
  "latitude": 22.2,
  "longitude": 114.1,
  "battery_voltage_v": 3.92,
  "solar_voltage_v": 5.78,
  "rssi_dbm": -61
}
```

## 8. Web Dashboard Architecture

The ESP32 dashboard should be useful but lightweight. A richer analytics dashboard can run on the backend.

ESP32-served dashboard:

- `/` serves current-condition dashboard.
- `/api/current` returns latest `WeatherData` JSON.
- `/api/history?hours=24` returns decimated history suitable for charts.
- `/api/status` returns firmware, WiFi, heap, storage, and sensor health.
- `/update` exposes authenticated OTA update page or API.

Frontend components:

| Component | Data Source | Notes |
| --- | --- | --- |
| Live cards | `/api/current` | Temperature, humidity, pressure, UV, PM2.5, wind, rain |
| 24-hour charts | `/api/history?hours=24` | Chart.js line charts |
| Wind rose | `/api/history?hours=24&type=wind` | Direction bins |
| AQI indicator | `/api/current` | Derived from PM2.5 |
| System status | `/api/status` | Sensor diagnostics and power |

Backend dashboard:

- Flask or FastAPI ingests MQTT/HTTP data.
- SQLite stores raw readings and hourly rollups.
- scikit-learn trains simple linear regression models off-device.
- Backend exposes prediction endpoints for temperature, humidity, and pressure trend.

## Review Decisions Needed

1. Confirm the exact ESP32-S3 development board model.
2. Confirm RS485 wind sensor Modbus register maps and slave IDs.
3. Confirm rain gauge bucket size in mm per tip.
4. Confirm whether SD card hardware is included or LittleFS is the first storage target.
5. Confirm whether MQTT broker is local, cloud-hosted, or running on Raspberry Pi.
6. Confirm whether the backend should be Flask or FastAPI.

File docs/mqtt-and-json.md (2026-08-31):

# Historical MQTT Proposal (Deferred)

This file is retained as earlier design history. **Core v0.2 does not use MQTT.** The implemented prototype uses direct HTTP POST as documented in `docs/core-v0.2.md`. MQTT may be reconsidered later without changing sensor drivers or `WeatherData`.

## Topic Namespace

```text
weather-station/{station_id}
```

Example station ID:

```text
ws-esp32s3-001
```

## Publish Topics

| Topic | QoS | Retain | Purpose |
| --- | ---: | --- | --- |
| `weather-station/{station_id}/telemetry/current` | 1 | No | Full current measurement |
| `weather-station/{station_id}/telemetry/air` | 1 | No | PMS7003 particulate data |
| `weather-station/{station_id}/telemetry/wind` | 1 | No | Wind speed and direction |
| `weather-station/{station_id}/telemetry/rain` | 1 | No | Rain rate and accumulation |
| `weather-station/{station_id}/status` | 1 | Yes | Online, firmware, IP, uptime |
| `weather-station/{station_id}/diagnostics` | 1 | No | Sensor health and error counts |
| `weather-station/{station_id}/ota/status` | 1 | No | OTA state and result |

## Subscribe Topics

| Topic | Purpose |
| --- | --- |
| `weather-station/{station_id}/config/set` | Update runtime config |
| `weather-station/{station_id}/commands/restart` | Controlled reboot |
| `weather-station/{station_id}/commands/sensor/wake` | Wake power-managed sensors |
| `weather-station/{station_id}/commands/sensor/sleep` | Sleep power-managed sensors |

## Current Telemetry Payload

```json
{
  "schema": "weather.current.v1",
  "station_id": "ws-esp32s3-001",
  "timestamp": 1717800000000,
  "location": {
    "latitude": 22.2,
    "longitude": 114.1,
    "altitude_m": 35.2
  },
  "environment": {
    "temperature_c": 28.4,
    "humidity_pct": 74.2,
    "pressure_hpa": 1008.6,
    "light_lux": 12500.0,
    "uv_index": 5.2
  },
  "air_quality": {
    "pm1_0_ugm3": 4.0,
    "pm2_5_ugm3": 8.0,
    "pm10_ugm3": 14.0,
    "aqi_category": "good"
  },
  "wind": {
    "speed_ms": 3.1,
    "direction_deg": 142.0
  },
  "rain": {
    "recent_mm": 0.2,
    "daily_mm": 1.4,
    "monthly_mm": 42.8
  },
  "power": {
    "battery_voltage_v": 3.92,
    "solar_voltage_v": 5.78,
    "battery_pct_estimate": 76
  },
  "network": {
    "rssi_dbm": -61
  }
}
```

## Status Payload

```json
{
  "schema": "weather.status.v1",
  "station_id": "ws-esp32s3-001",
  "timestamp": 1717800000000,
  "firmware_version": "0.1.0",
  "uptime_s": 86400,
  "wifi_connected": true,
  "ip": "192.168.1.42",
  "mqtt_connected": true,
  "ntp_synced": true,
  "free_heap_bytes": 182000,
  "storage_free_bytes": 1048576
}
```

## Diagnostics Payload

```json
{
  "schema": "weather.diagnostics.v1",
  "station_id": "ws-esp32s3-001",
  "timestamp": 1717800000000,
  "sensors": [
    {
      "name": "SHT40",
      "state": "ready",
      "last_read_ms": 1717800000000,
      "error_count": 0,
      "last_error": ""
    }
  ]
}
```

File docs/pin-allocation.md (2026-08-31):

# ESP32-S3 Pin Allocation

This table uses conservative ESP32-S3 DevKit-style pins. Confirm against the exact board schematic before wiring.

## Main Bus Assignments

| Function | ESP32-S3 Pin | Direction | Notes |
| --- | ---: | --- | --- |
| I2C SDA | GPIO8 | Bidirectional | SHT4x, BMP180, BH1750, LTR390 |
| I2C SCL | GPIO9 | Output | 100 kHz initially, 400 kHz after validation |
| PMS7003 UART RX | GPIO16 | Input | ESP32 receives from PMS TX |
| PMS7003 UART TX | GPIO17 | Output | ESP32 transmits to PMS RX |
| PMS7003 SET/Sleep | GPIO18 | Output | Optional sleep control |
| GPS UART RX | GPIO15 | Input | ESP32 receives from GPS TX |
| GPS UART TX | GPIO14 | Output | ESP32 transmits to GPS RX |
| RS485 UART RX | GPIO6 | Input | ESP32 receives from RS485 transceiver RO |
| RS485 UART TX | GPIO7 | Output | ESP32 transmits to RS485 transceiver DI |
| RS485 DE/RE | GPIO5 | Output | Direction control, shared DE and /RE |
| Rain gauge pulse | GPIO4 | Input interrupt | Use pull-up and debounce |
| SD CS | GPIO10 | Output | Optional SPI SD card |
| SPI SCK | GPIO12 | Output | Optional SD |
| SPI MISO | GPIO13 | Input | Optional SD |
| SPI MOSI | GPIO11 | Output | Optional SD |
| Wind 12V enable | GPIO21 | Output | Drives MOSFET/load switch, not sensor directly |
| Status LED | GPIO2 | Output | Optional board LED if available |
| Battery ADC | GPIO1 | Analog input | Through resistor divider |
| Solar ADC | GPIO3 | Analog input | Through resistor divider |

## I2C Address Plan

| Device | Typical Address | Notes |
| --- | ---: | --- |
| SHT4x | `0x44` | Temperature/humidity; exact SHT40/SHT41 variant not asserted |
| BMP180 | `0x77` | Pressure and sensor temperature |
| BH1750 | `0x23` or `0x5C` | Light |
| LTR390 | `0x53` | UV and ALS |

## UART Plan

| UART | Device | Baud | Notes |
| --- | --- | ---: | --- |
| Native USB CDC (`Serial`) | USB monitor | 115200 | Core v0.4 production debug console; consumes no hardware UART |
| UART2 | PMS7003 | 9600 | The only non-console UART active in Core v0.1 |
| UART1 | TEL0157/L76K GNSS | 9600 | Active in Core v0.3; GPIO15 RX, GPIO14 TX |
| UART0 | Wind speed RS485 | 4800 8N1 | Core v0.4 production; GPIO6 RX, GPIO7 TX, GPIO5 DE/RE |
| UART2 | Wind direction RS485 | 4800 8N1 | Isolated `diag_wind_direction` environment |
| UART1 | Wind speed RS485 | 4800 8N1 | Preserved `diag_wind_speed` standalone allocation |

The diagnostic UART reuse is safe because only one PlatformIO environment runs at a time. Core v0.4 resolves simultaneous production use by routing the debug console over the ESP32-S3 native USB CDC interface and assigning UART0 to RS485. The standalone diagnostic remains UART1 and does not run alongside GNSS.

## Power Notes

| Subsystem | Voltage | Control |
| --- | ---: | --- |
| ESP32-S3 | 5V input or 3.3V regulated | From Waveshare 5V system supply |
| I2C sensors | 3.3V | Always on or switched 3.3V rail |
| PMS7003 | 5V | Sleep pin recommended |
| TEL0157/L76K GNSS | 3.3-5.5 V supported; use 3V3 in this project | UART selector position; active in Core v0.3 |
| RS485 wind sensors | 12V | Boost converter plus load switch |
| RS485 transceiver | 3.3V | Logic-level compatible transceiver required |

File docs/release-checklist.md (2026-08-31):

# Release Checklist

Complete this checklist before a tagged public release.

## Build and evidence

- [ ] Continuous integration passes on the release commit.
- [ ] Changed hardware has a named procedure and evidence record.
- [ ] The README status table matches the milestone and test matrix.
- [ ] Planned, compiled, bench-verified, integrated and field-verified claims are distinguishable.
- [ ] Known failures and deferred work remain visible.
- [ ] A clean clone can follow the documented software setup.

## Safety, security and privacy

- [ ] No credentials, private endpoints, tokens or private keys are present in tracked files or release assets.
- [ ] GNSS coordinates, site access details and personal information are removed or approved.
- [ ] The local-network security boundary is stated.
- [ ] Outdoor, battery, 12 V, fabrication and mounting limits are current.
- [ ] Images and databases have been reviewed for sensitive information.

## Reuse and attribution

- [ ] The MIT licence is present.
- [ ] New dependencies are listed in `THIRD_PARTY.md`.
- [ ] Reused code, CAD, data and media have compatible terms and attribution.
- [ ] AI-assisted work has been checked by a responsible contributor and recorded when material.
- [ ] Contribution and security contact routes are working.

## Release decision

| Item | Record |
| --- | --- |
| Release version | |
| Commit | |
| Reviewer | |
| Approved claims | |
| Required redactions | |
| Known limitations | |
| Decision and date | |

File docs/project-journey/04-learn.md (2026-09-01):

# Gate 04: Learn

Gate 04 began by studying working open-source weather stations rather than treating the project as if no one had solved similar problems before.

## Open projects studied

| Reference | What was learned | What this project does differently |
| --- | --- | --- |
| [SeBassTian23/ESP32-WeatherStation](https://github.com/SeBassTian23/ESP32-WeatherStation) | Solar-powered ESP32 sensing can include particulate matter and UV-related measurements, but power demand and calibration limits remain important. | Keep every sensor's validity visible and treat UV and air-quality outputs as bounded measurements rather than automatic environmental claims. |
| [cerevisis/ESP32-Weather-Station](https://github.com/cerevisis/ESP32-Weather-Station) | A weather station can expose live readings, history, configuration and diagnostics through a web interface. | Use a small local FastAPI and SQLite path so ingestion rules, stored history and failure states can be tested independently. |
| [maxmacstn/HA-SolarWeatherStation](https://github.com/maxmacstn/HA-SolarWeatherStation) | Deep sleep, battery-aware operation and separated enclosures are practical strategies for autonomous outdoor sensing. | Keep the sensing and power modules editable and defer any autonomy claim until the complete energy balance has been measured. |

These projects are precedents, not hidden ingredients. Their licences continue to govern their work. The implementation in this repository was developed and documented separately, with the reference ideas and resulting design decisions made explicit.

## Rebuild, understand, then adapt

Each working version was kept small enough to reproduce and understand one established capability before changing it for this project's local-evidence goal. Later milestones preserve the earlier diagnostics and failure behaviour.

## Core v0.1: integrated sensing

**Question:** Can four I²C devices and the PMS7003 operate together without one failure stopping the rest?

**Learned:** A shared snapshot and per-sensor health model are more useful than printing isolated values. Range, staleness and failure counters make unavailable data visible.

**Evidence:** [v0.1 milestone](../milestones/v0.1-core-sensors.md), diagnostic environments and bench images.

## Core v0.2: connected data path

**Question:** Can a local service receive, validate, store and display station snapshots without making sensing depend on the network?

**Learned:** Networking needs independent reconnect timing and bounded uploads. Typed API validation and nullable data make failures inspectable. Database migrations must preserve existing records.

**Evidence:** [v0.2 milestone](../milestones/v0.2-connected-iot.md), backend tests and dashboard screenshot.

## Core v0.3: GNSS integration

**Question:** Can the receiver report communication, no-fix and valid-fix states without blocking the rest of the station?

**Learned:** Communication and position validity are different states. The installed library required a documented hemisphere workaround based on checksum-valid NMEA fields. Precise coordinates need a publication rule.

**Evidence:** [v0.3 milestone](../milestones/v0.3-gnss-integration.md), GNSS diagnostics and privacy-safe images.

## Core v0.4: wind-speed integration

**Question:** Can verified RS485 wind speed enter the complete data path while timeouts remain isolated?

**Learned:** Native USB CDC frees UART0 for production RS485. A calm `0.0 m/s` reading must remain valid, while a timeout must become unavailable. The schema and database can extend additively without breaking v0.3 payloads.

**Evidence:** [v0.4 milestone](../milestones/v0.4-wind-speed-integration.md), backend compatibility tests and the preserved standalone diagnostic.

## Current working version

The repository contains a complete software path for Core v0.4. The next action is not another feature. It is the combined hardware verification procedure in [`core-v0.4.md`](../core-v0.4.md).

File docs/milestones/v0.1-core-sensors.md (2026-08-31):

# v0.1 — Core Integrated Sensor Prototype

**Milestone status:** Complete  
**Verified result:** Four I²C sensor modules and one PMS7003 particulate subsystem operated together through a shared data and health model.  
**Not part of this milestone:** networking/backend, GNSS integration, wind integration, rain, power telemetry, predictions.

## 1. Objective

Convert the project from separate sensor and communications diagnostics into the first stable integrated weather-station firmware. v0.1 needed to acquire every core bench sensor without allowing one missing or failed device to stop the station.

## 2. Starting point

Early development established pin plans and isolated tests for I²C, PMS7003 UART, GNSS UART, and RS485 wind devices. Those tests were valuable, but they did not yet prove simultaneous sensor acquisition or a stable contract for later consumers. v0.1 made the sensor path the source of truth and kept experimental subsystems outside `main.cpp`.

## 3. Hardware involved

The production v0.1 path used these definitions from `firmware/include/pins.h` and `firmware/include/app_config.h`:

| Device | Measurement | Interface | ESP32-S3 assignment | Verification status |
| --- | --- | --- | --- | --- |
| ESP32-S3 DevKitC-1 build target | Control | — | PlatformIO board target | Integrated |
| SHT4x | Temperature, humidity | I²C `0x44` | SDA GPIO8, SCL GPIO9 | Hardware verified |
| BMP180 | Pressure | I²C `0x77` | SDA GPIO8, SCL GPIO9 | Hardware verified |
| BH1750 | Light | I²C `0x23` or `0x5C` | SDA GPIO8, SCL GPIO9 | Hardware verified |
| LTR390 | Raw UV, estimated UV index | I²C `0x53` | SDA GPIO8, SCL GPIO9 | Hardware verified |
| PMS7003 | PM1.0, PM2.5, PM10 | UART2, 9600 baud | RX GPIO16, TX GPIO17, SET GPIO18 | Hardware verified |

The I²C bus runs at 100 kHz. The exact fitted SHT40/SHT41 variant has not been independently established, so the project accurately identifies it as the SHT4x family. The current production sensor is BMP180, despite an earlier BOM draft naming BMP390.

See [pin allocation](../pin-allocation.md), [wiring](../../hardware/wiring.md), and the [current BOM](../../hardware/bom.md).

## 4. Software changes and architecture

```text
SHT4x ─┐
BMP180 ┤
BH1750 ┤
LTR390 ┤
        ├──> Sensor layer ──> WeatherData ──> validation / SensorHealth ──> Serial snapshot
PMS7003┘
```

- `SensorManager` owns the four I²C drivers and updates a shared `WeatherData` instance.
- `PMS7003Sensor` updates the particulate fields and reports frame diagnostics.
- `SensorHealth` records initialization, current validity, staleness, last success, consecutive failures, and total failures.
- Each I²C driver initializes and reads independently. An uninitialized sensor is retried on a later environmental cycle.
- `main.cpp` applies range checks and prints `unavailable` rather than confusing a missing value with a real zero.
- `millis()` scheduling runs I²C reads every 5 seconds, PMS acquisition every 10 seconds with a 1.5-second bound, and Serial snapshots every 10 seconds.

The detailed model and behavior remain documented in [Core v0.1 implementation notes](../core-v0.1.md).

## 5. Diagnostics

Diagnostics are preserved as isolated PlatformIO environments. Only one entry point is compiled at a time, which keeps experimental UART assignments and blocking diagnostic behavior out of production firmware.

| Environment | Purpose | Milestone meaning |
| --- | --- | --- |
| `diag_i2c` | Scan addresses and compare them with the four expected sensors | Core v0.1 bring-up tool |
| `diag_pms` | Read PMS7003 frames and report checksum/read failures | Core v0.1 bring-up tool |
| `diag_wind_direction` | Query the preserved Modbus wind-direction registers | Diagnostic only; not integrated |
| `diag_wind_speed` | Query the preserved Modbus wind-speed register | Diagnostic only; not integrated |
| `diag_gnss` | Inspect UART bytes, NMEA checksums, and fix state | Diagnostic only; not integrated |

From `firmware/`, flash and monitor a diagnostic:

```powershell
pio run -e diag_i2c -t upload
pio device monitor -b 115200
```

Return to the production application:

```powershell
pio run -e weather_station -t upload
```

Keeping diagnostics separate makes failures reproducible: a builder can prove electrical detection or UART framing first, then return to the integrated scheduler. See [Troubleshooting](../troubleshooting.md).

## 6. Testing procedure

1. Confirm power and logic levels for every breakout.
2. Flash `diag_i2c`; verify `0x44`, `0x77`, `0x23` or `0x5C`, and `0x53` are reported.
3. Flash `diag_pms`; verify valid 32-byte Plantower frames, checksum success, and plausible particulate fields.
4. Flash `weather_station` and monitor at 115200 baud.
5. Confirm all four I²C values and all three particulate values appear in the same structured snapshot.
6. Disconnect or disturb one sensor only during a controlled bench test; confirm other sensors continue and the affected health state reports failure/staleness.

The repository records that the integrated set was verified. It does not include a formal calibration record or long-duration environmental test log.

## 7. Problems encountered and resolutions

### I²C detection before driver debugging

**Problem:** A sensor-level failure can be caused by power, wiring, soldering, connector continuity, address selection, or driver behavior. Treating every failure as a software defect wastes time.

**Diagnostic method:** `diag_i2c` performs a startup-only bus scan and compares detected addresses with SHT4x `0x44`, BMP180 `0x77`, BH1750 `0x23`/`0x5C`, and LTR390 `0x53`.

**Result:** The supplied diagnostic capture shows four devices and PASS for all expected sensor checks. The capture visibly shows devices at `0x53` and `0x77`; the other two detected-address lines are outside the crop, so their addresses should not be inferred from the picture alone.

### BH1750 connection issue

**Problem:** The BH1750 did not initially appear as a working member of the shared bus.

**Method and resolution:** Bus scanning and physical connection inspection were used before changing the driver. The integrated baseline subsequently verified the BH1750, and the driver supports either standard address (`0x23` first, then `0x5C`). The repository does not retain enough detail to claim a more specific failed joint, cable, or connector, so none is asserted here.

### LTR390 read investigation

**Problem:** Address detection alone does not prove that useful LTR390 reads and the existing UV conversion path work.

**Method and resolution:** The bus scan established presence at `0x53`; the isolated driver and then the integrated `SensorManager` path established successful raw UV reads and an estimated UV index. No calibration-grade accuracy claim is made.

### PMS7003 UART and frame validation

**Problem:** Receiving UART bytes does not guarantee a valid PMS measurement; framing errors and misalignment can look like data.

**Method and resolution:** The parser searches for headers `0x42 0x4D`, checks the expected frame length, and validates the checksum before updating `WeatherData`. `diag_pms` exposes received-frame, checksum-error, read-failure, last-valid-frame, and SET-pin information.

### Diagnostics versus production firmware

**Problem:** Experimental GNSS/RS485 code and dedicated hardware tests could conflict with the production entry point or UART allocation.

**Resolution:** `platformio.ini` selects one diagnostic source per diagnostic environment and excludes `main.cpp` plus networking components. `weather_station` excludes the entire diagnostics directory.

## 8. Verified result

v0.1 demonstrated simultaneous operation of four I²C sensor modules and the PMS7003, unified acquisition in `WeatherData`, per-sensor health/error handling, and structured Serial weather snapshots. This stable read-only snapshot became the input to v0.2 networking rather than placing network logic inside sensor drivers.

## 9. Images and evidence

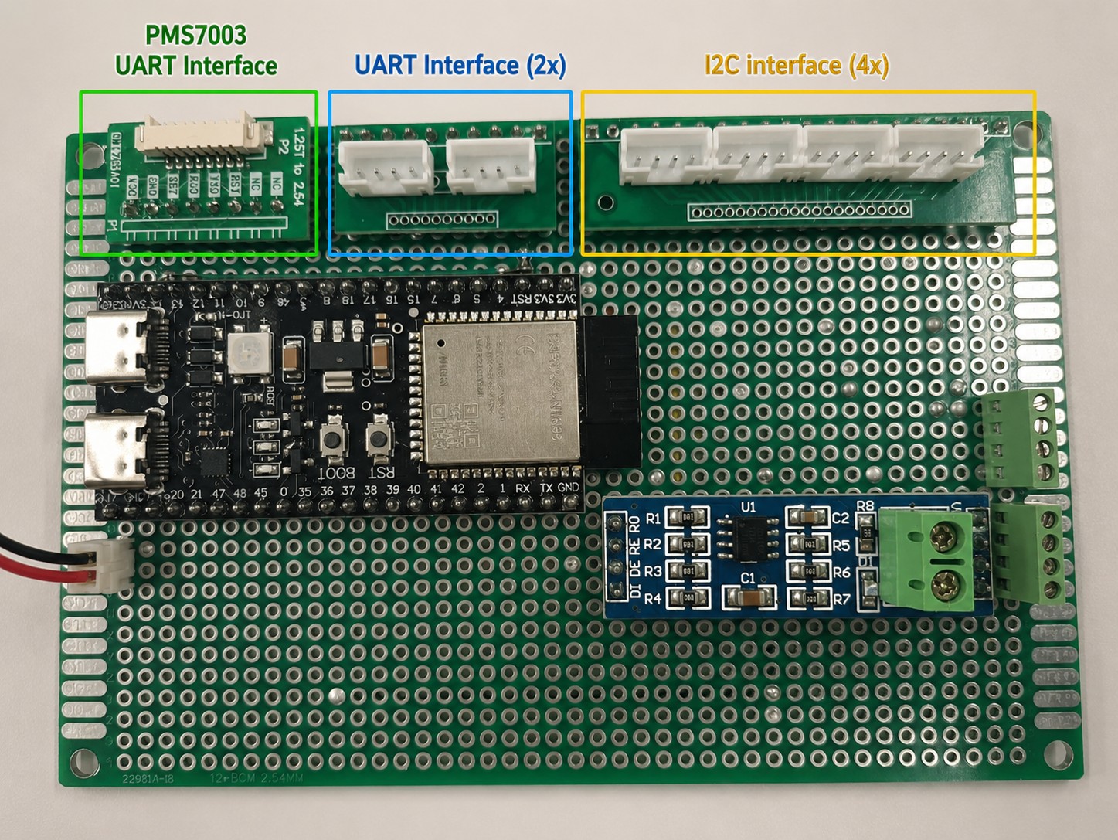
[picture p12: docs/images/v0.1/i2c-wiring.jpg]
Front of the v0.1 perfboard with labeled PMS7003, UART, and I²C connector groups


*Front-side connector layout. The yellow group exposes four shared-I²C connections; the blue and green groups preserve UART interfaces.*

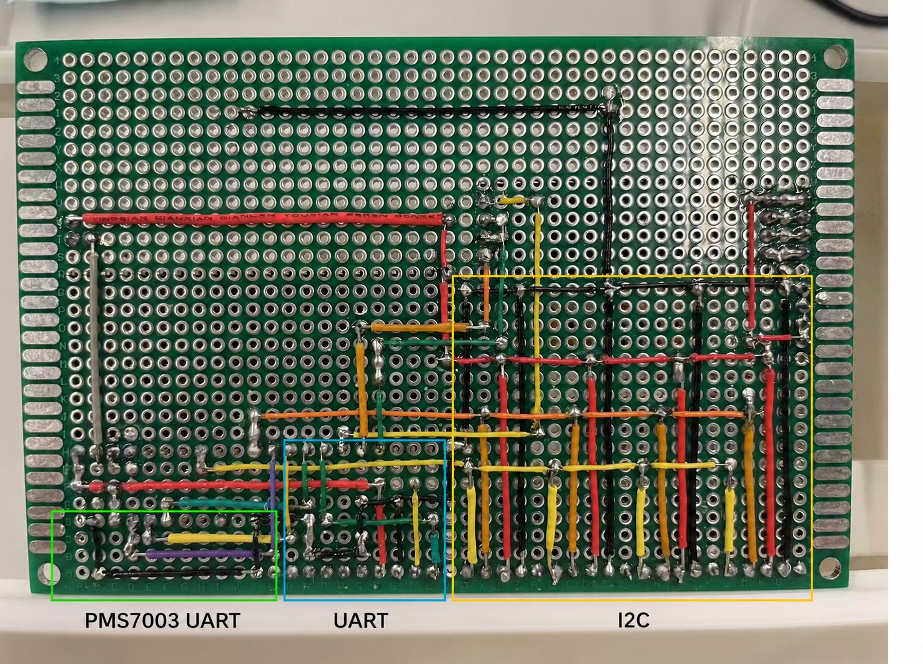
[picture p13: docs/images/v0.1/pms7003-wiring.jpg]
Back of the v0.1 perfboard with colored wiring regions


*Back-side point-to-point wiring, labeled by PMS7003 UART, other UART, and I²C regions for inspection and continuity tracing.*

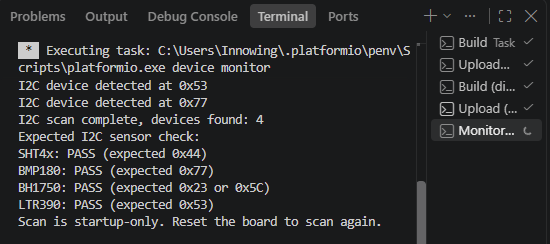
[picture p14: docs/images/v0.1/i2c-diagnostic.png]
v0.1 I²C diagnostic terminal showing four expected sensor checks passing


*Startup-only I²C diagnostic showing four devices found and PASS results for SHT4x, BMP180, BH1750, and LTR390.*

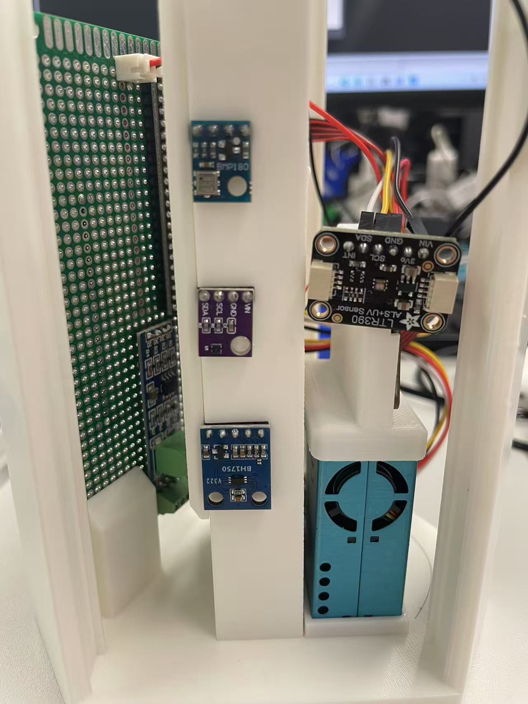
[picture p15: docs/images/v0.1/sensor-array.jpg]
Environmental and particulate sensors mounted in the v0.1 prototype frame


*Sensor-side assembly showing the environmental breakouts and PMS7003 mounted with open airflow during bench work.*

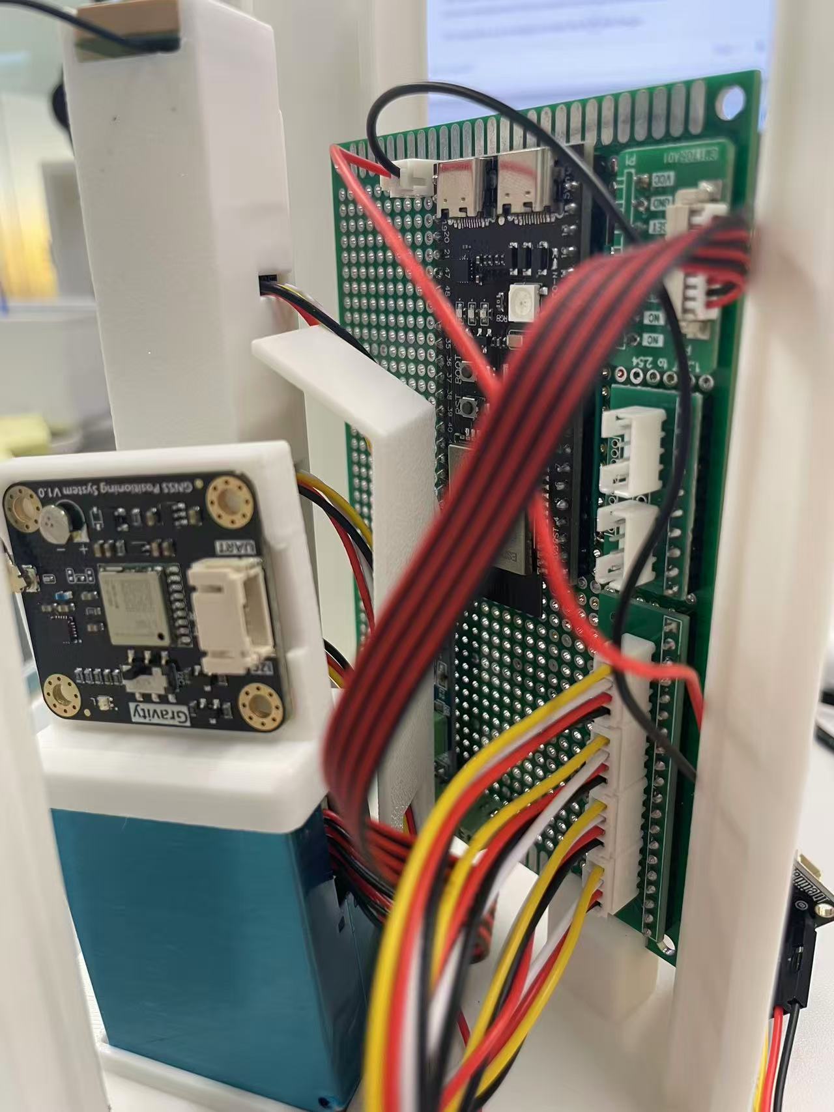
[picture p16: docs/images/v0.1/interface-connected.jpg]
Connected ESP32-S3 interface board and sensor harnesses


*Connected interface view showing the ESP32-S3, breakout connectors, harnesses, and adjacent communication module.*

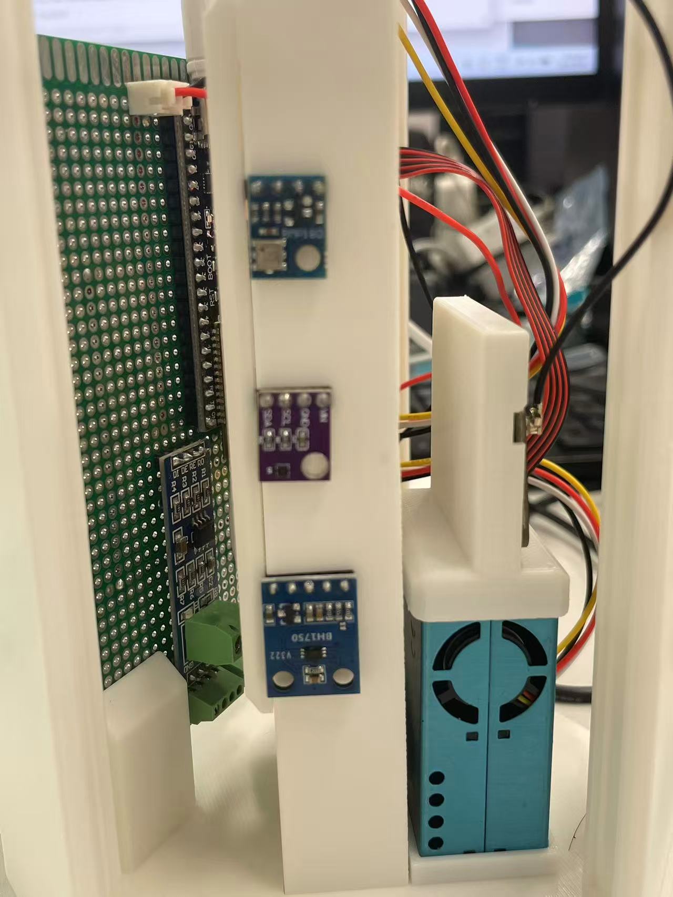
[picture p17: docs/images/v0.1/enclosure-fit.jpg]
v0.1 electronics fitted into the prototype enclosure frame


*Prototype enclosure fit used to check component placement and cable routing; it is not evidence of weatherproofing or thermal suitability.*

<!-- TODO(v0.1 evidence): Add docs/images/v0.1/integrated-serial-output.png. Capture one complete structured WEATHER SNAPSHOT with all five health entries visible; redact Wi-Fi credentials and local IP addresses. -->

**Missing evidence:** `docs/images/v0.1/integrated-serial-output.png` has not been supplied.

## 10. Known limitations

- No networking or persistent storage belonged to v0.1.
- GNSS and wind had diagnostic code only; rain and power telemetry were deferred.
- Sensor accuracy was not calibrated against traceable references.
- The enclosure fit was a mechanical prototype, not a completed radiation shield or outdoor enclosure validation.
- PMS placement, airflow, condensation control, and long-duration contamination behavior were not field tested.

## 11. What came next

v0.2 consumed the validated `WeatherData` snapshot as JSON, added failure-tolerant Wi-Fi and HTTP upload, stored it in FastAPI/SQLite, and displayed it in a local dashboard. See [v0.2 — Connected IoT Prototype](v0.2-connected-iot.md).

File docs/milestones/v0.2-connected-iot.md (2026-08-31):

# v0.2 — Connected IoT Prototype

**Milestone status:** Complete  
**Verified result:** ESP32 → Wi-Fi → HTTP → FastAPI → SQLite → desktop/mobile browser dashboard on a reachable local network.  
**Not production-ready:** no TLS, authentication, offline backlog, cloud deployment, or autonomous field validation.

## 1. Objective

Extend the verified v0.1 sensor snapshot to a small, understandable connected system without weakening sensor acquisition when the network is absent or slow.

## 2. Starting point

v0.1 already provided independent drivers, `WeatherData`, range validation, health/staleness information, and Serial snapshots. v0.2 treated that snapshot as a read-only boundary and added communications after it.

## 3. Hardware involved

The sensor hardware and pins are unchanged from v0.1. Wi-Fi uses the ESP32-S3 radio. No GNSS, wind, rain, battery, or solar measurement is enabled by the `weather_station` environment.

## 4. Software changes and architecture

```text
v0.1: Sensors ─> WeatherData ─> Serial

v0.2: Sensors ─> WeatherData ─> JSON ─> Wi-Fi ─> HTTP
                                                   ↓
                                                FastAPI
                                                   ↓
                                                SQLite
                                                   ↓
                                               Dashboard
```

### Firmware

- `NetworkManager` implements `DISABLED`, `CONNECTING`, `CONNECTED`, `DISCONNECTED`, and `RETRY_WAIT` states. It starts Wi-Fi asynchronously, bounds an attempt to 15 seconds, and waits 30 seconds between attempts.
- Optional NTP is requested after connection and polled without a blocking synchronization loop. Until it succeeds, `device_timestamp` is `null`.
- `WeatherDataSerializer` produces the `weather.measurement.v1` JSON document. Invalid or stale readings become JSON `null`; a real numeric zero remains distinct.
- `HttpDataUploader` accepts the latest snapshot through a one-element overwrite queue and posts from a separate FreeRTOS worker. Connect/read timeouts are 3/5 seconds.
- Uploads are scheduled every 60 seconds. There is no immediate retry storm and no offline replay; the next current snapshot replaces an unsent queued snapshot.

### Backend and dashboard

- FastAPI validates the nested measurement and health schema.
- SQLite stores server/device timestamps, firmware and uptime, eight measurement fields, five validity flags, and the complete health JSON.
- `POST /api/v1/measurements` stores a snapshot.
- `GET /api/v1/measurements/latest` returns the newest observation, optionally for a station.
- `GET /api/v1/measurements` filters history by station/time and returns newest first.
- The static dashboard displays current conditions, station freshness, sensor health, and canvas-based trend charts for 1 hour, 24 hours, or 7 days.
- Responsive CSS supports narrow screens; operation has been verified from desktop and mobile browsers on a reachable local network.

HTTP was selected because direct request/response behavior is easy to inspect with the FastAPI docs, a browser, or command-line tools and is sufficient for one local prototype. MQTT, broker operations, device identity, secure transport, and cloud services would add complexity before their requirements are established. The earlier MQTT document is retained as [design history](../mqtt-and-json.md), not as implemented behavior.

Full payload and failure cases are in [Core v0.2 implementation notes](../core-v0.2.md).

## 5. Testing procedure

1. Create `firmware/include/secrets.h` from `secrets.example.h` and use placeholder/local credentials only.
2. Set `BACKEND_HOST` to the backend computer's reachable LAN IP.
3. Create a Python 3.11 virtual environment, install `backend/requirements.txt`, and start Uvicorn on `0.0.0.0:8000`.
4. Run `python -m pytest -q` in the backend environment.
5. Flash `weather_station` and observe Wi-Fi state plus `HTTP upload: OK (code=201)` over Serial.
6. Query the latest endpoint and confirm `backend/weather.db` receives a row.
7. Open the dashboard on the backend computer and, where the LAN permits it, another desktop/mobile device.
8. Stop the backend or disconnect Wi-Fi briefly; confirm sensing and Serial snapshots continue, then confirm later snapshots resume after recovery.

## 6. Problems encountered and solutions

### Network work must not block sensors

The solution separates `NetworkManager::tick()` from acquisition and runs HTTP in a worker with bounded timeouts. Sensor drivers do not know about Wi-Fi or HTTP.

### Time may be unavailable

The device sends uptime in every payload and a nullable UTC device timestamp. SQLite always records the backend's UTC receive time, which is authoritative for v0.2 display/history.

### Backend outages can outlast device memory

v0.2 intentionally keeps only the latest queued conditions. This avoids an unbounded in-memory queue but loses outage-period readings. Durable offline backlog/replay is planned work and must include ordering and duplicate-handling rules.

### Local-network reachability varies

The backend binds to `0.0.0.0`; the firmware uses the computer's LAN address. Host firewall rules or Wi-Fi client isolation can still block ESP32-to-computer traffic. See [Troubleshooting](../troubleshooting.md).

## 7. Verified result

The completed v0.2 baseline sends real sensor snapshots end to end from the ESP32 to FastAPI/SQLite and presents them through the local dashboard. Backend API tests cover successful storage/retrieval, malformed input rejection, null unavailable fields, missing-station behavior, and dashboard serving.

## 8. Images and evidence

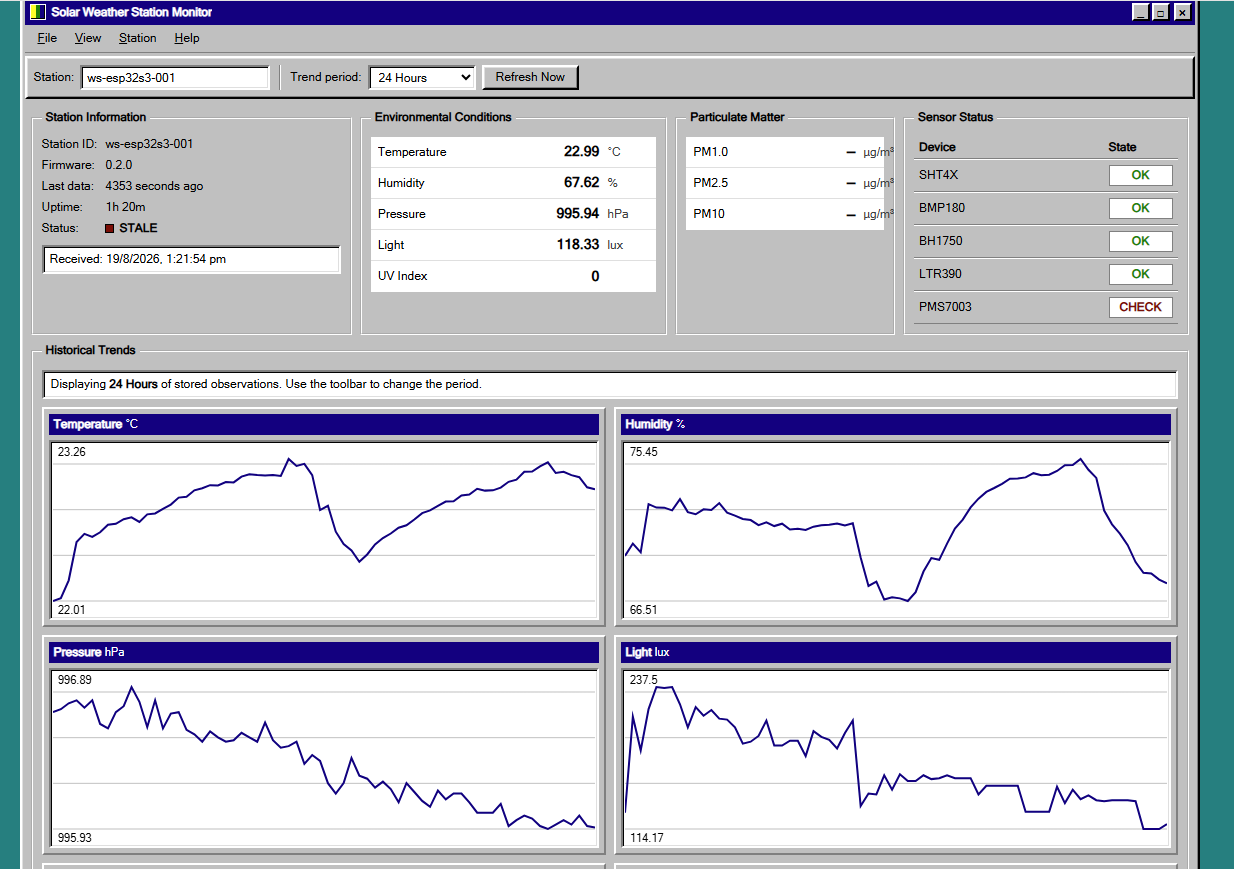
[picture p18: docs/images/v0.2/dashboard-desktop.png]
Windows 98-inspired v0.2 dashboard with current values, sensor status, and trend charts


*Desktop dashboard displaying a station snapshot and 24-hour stored trends. The shown PMS state is CHECK because particulate values were unavailable in that particular captured snapshot; it does not override the separately verified v0.1 PMS baseline.*

<!-- TODO(v0.2 evidence): Add docs/images/v0.2/dashboard-mobile.png. Capture the responsive dashboard on a phone connected to the same reachable development network; avoid exposing a private IP in the image. -->
<!-- TODO(v0.2 evidence): Add docs/images/v0.2/system-architecture.png only if a maintained diagram adds value beyond the text architecture above. Do not create a decorative or inaccurate diagram. -->
<!-- TODO(v0.2 evidence): Add docs/images/v0.2/trend-example.png as a focused historical-chart capture from stored observations. The desktop image already contains charts, so avoid reusing the same screenshot. -->

**Missing evidence:** `dashboard-mobile.png`, `system-architecture.png`, and `trend-example.png` have not been supplied.

## 9. Known limitations

- Trusted LAN only: plain HTTP, no authentication or authorization.
- No durable device-side backlog, delivery acknowledgement store, or replay.
- No production deployment, database migration system, retention policy, or multi-user operations.
- SQLite is appropriate for this prototype, not a claim of high-volume scalability.
- Dashboard charts are simple local views, not calibrated analysis or forecasting.
- GNSS, wind, rain, battery, solar, and predictions remain outside the production data model.
- Desktop/mobile reachability depends on local router/firewall policy.

## 10. What comes next

v0.3 was subsequently completed after its standalone diagnostic proved power, UART communication, NMEA/checksum monitoring, UTC/date, position interpretation, hemispheres, satellites, altitude, and a valid fix. It then added nullable GNSS fields, additive database migration, and remote display without redefining the v0.2 milestone. See [v0.3 — GNSS Integration](v0.3-gnss-integration.md).

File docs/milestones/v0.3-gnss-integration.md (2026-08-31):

# v0.3 — GNSS Integration

**Milestone status:** Complete / hardware verified

**Verified result:** The GNSS receiver was first verified independently, then integrated with the existing environmental sensors, PMS7003, Wi-Fi/HTTP transport, FastAPI validation, SQLite storage, and remote dashboard.

**Not part of this milestone:** wind integration, rain, battery/solar telemetry, prediction, maps/tracking, or autonomous field validation.

## 1. Overview and objective

v0.3 integrates the GNSS subsystem into the already working v0.2 weather-station pipeline while first verifying the receiver independently through the dedicated `diag_gnss` environment. It is an incremental extension: the v0.1 sensor baseline and v0.2 connected pipeline remain in service.

```text
Physical GNSS installation
        ↓
Standalone GNSS diagnostic
        ↓
UART → NMEA → UTC/date → position → hemisphere/sign → fix verification
        ↓
Main firmware and WeatherData integration
        ↓
JSON → HTTP → FastAPI → SQLite → remote dashboard
        ↓
Existing sensors and PMS7003 verified alongside GNSS
        ↓
v0.3 complete
```

## 2. Starting point and historical boundary

v0.2 already provided four shared-I²C sensors, PMS7003 UART acquisition, `WeatherData`, health/staleness handling, non-blocking Wi-Fi, optional NTP, HTTP upload, FastAPI, SQLite, and current/history display. GNSS existed only as an isolated diagnostic and was explicitly disabled in production.

v0.3 does not rewrite that history. It promotes the verified GNSS path into production while preserving the earlier data path:

```text
SHT4x ─┐
BMP180 ┤
BH1750 ┤
LTR390 ┤
PMS7003┼──> WeatherData + validity ──> Serial / JSON ──> HTTP
GNSS ──┘                                                    ↓
                                                          FastAPI
                                                            ↓
                                                          SQLite
                                                            ↓
                                                    live + historical UI
```

## 3. Hardware added

| Item | Implemented configuration | Status |
| --- | --- | --- |
| GNSS module | DFRobot Gravity TEL0157 with Quectel L76K | Hardware verified |
| Constellation mode | GPS + BeiDou + GLONASS | Configured by production firmware |
| Interface | UART selector position, 9600 baud | Verified |
| Supply | Module supports 3.3–5.5 V; this project uses 3V3 | Verified configuration |
| Antenna | Active antenna connected to the module's IPEX1 socket | Installed and used for fix testing |
| Library | `DFRobot_GNSS` from the Git dependency in `platformio.ini` | Production and diagnostic |
| Firmware class | `GPSManager` plus `GnssNmeaHemisphere` | Production |
| Diagnostic | PlatformIO environment `diag_gnss` | Hardware verified |

Actual pin assignments from `firmware/include/pins.h`:

| Signal | ESP32-S3 assignment | Direction |
| --- | --- | --- |
| TEL0157 TX (`D/T`) | GPIO15 / UART1 RX | GNSS → ESP32 |
| TEL0157 RX (`C/R`) | GPIO14 / UART1 TX | ESP32 → GNSS |
| VCC | 3V3 | Power |
| GND | GND | Common reference |

PMS7003 remains on UART2 GPIO16/17 with SET on GPIO18. Wind diagnostic UART assignments are unchanged and remain isolated builds.

## 4. Physical installation

The module and antenna were fitted into the developing electronics assembly before final integrated verification. This image demonstrates installation and cable routing, not weatherproofing, antenna environmental qualification, or final enclosure approval.

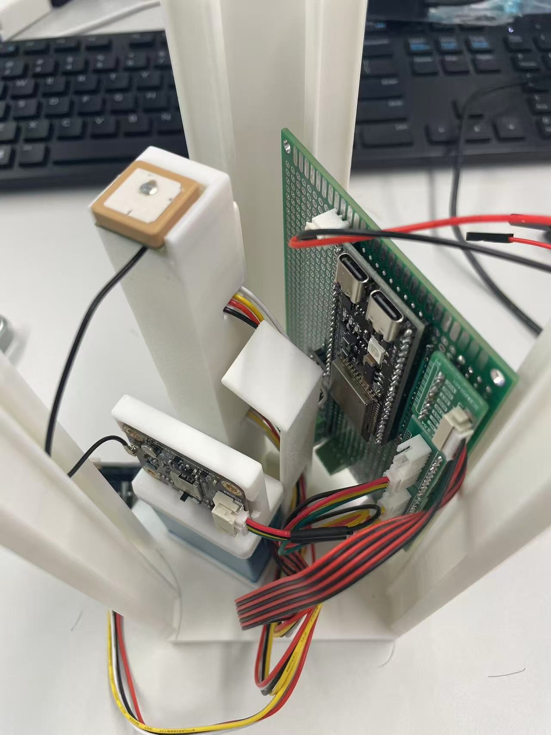
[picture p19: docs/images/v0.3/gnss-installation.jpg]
GNSS antenna and module installed with the existing ESP32-S3 weather-station electronics


*v0.3 GNSS hardware installation — GNSS integrated into the existing ESP32-S3 weather-station assembly before final software verification.*

Installation sequence:

1. Remove power before moving the TEL0157 interface selector to UART.
2. Seat the active antenna connector firmly.
3. Cross TX/RX according to the table above and use a common ground.
4. Recheck continuity and connector seating after mounting.
5. Test with a clear sky view and allow time for a cold acquisition.

See [wiring](../../hardware/wiring.md), [pin allocation](../pin-allocation.md), and the [BOM](../../hardware/bom.md).

## 5. Communication and firmware components

### Production path

`GPSManager` owns a `HardwareSerial` instance on UART1 and a `DFRobot_GNSS_UART` instance. All blocking library probes and reads run in the priority-1 `gnss-worker` FreeRTOS task. The Arduino loop calls `GPSManager::update()`, which only copies a mutex-protected snapshot into the shared `WeatherData`.

Current compile-time behavior from `app_config.h`:

- GNSS enabled in `weather_station`;
- 10-second GNSS read period;
- 30-second fix-stale threshold;
- 30-second communication timeout;
- 60-second retry when the receiver is not detected.

This separation means a missing receiver or slow library call cannot directly block environmental reads, PMS acquisition, Wi-Fi maintenance, HTTP scheduling, or Serial snapshots.

### NMEA support

`GnssNmeaHemisphere` consumes callback bytes from `getAllGnss()`. It:

- frames sentences beginning with `$`;
- calculates and verifies the NMEA XOR checksum;
- counts valid sentences and checksum failures;
- recognizes fix-bearing GGA, RMC, and GLL sentences;
- accepts N/S and E/W only from checksum-valid sentences whose fix/status field is valid.

Valid-sentence and checksum-failure totals are diagnostic counters, not fixed expected numbers. Different real runs can legitimately show different counts; persistent or rapidly increasing failures are evidence to investigate signal integrity or communication quality.

## 6. Dedicated diagnostic environment

GNSS was tested alone before entering the complete station so power, UART wiring, raw messages, library interpretation, and sky/fix conditions could be separated from network and sensor scheduling.

From `firmware/`:

```powershell
pio run -e diag_gnss -t upload
pio device monitor -b 115200
```

The diagnostic offers status/raw inspection and reports communication, module mode, raw DFRobot fields, interpreted validity, NMEA counters, hemispheres, signed coordinates, satellite use, altitude, and fix state. Diagnostic builds replace the application in flash but do not modify source files.

Restore the integrated station after testing:

```powershell
pio run -e weather_station -t upload
pio device monitor -b 115200
```

## 7. Independent diagnostic procedure

1. Power off and verify selector, antenna, VCC/GND, and crossed TX/RX wiring.
2. Flash `diag_gnss` and monitor at 115200 baud.
3. Confirm the module responds and NMEA bytes/sentences arrive.
4. Inspect valid-sentence and checksum-failure counters over time.
5. Verify UTC fields and the calendar date pass range checks.
6. Verify latitude and longitude magnitudes pass range checks.
7. Confirm N and E/W hemisphere fields are recovered from checksum-valid NMEA.
8. Confirm signed decimal coordinates become available.
9. Confirm at least one satellite is used and the diagnostic reports `FIX VALID`.
10. Observe altitude and satellite-count reporting without treating one captured numeric value as a specification.

### Verification categories

| Independent GNSS test | Result |
| --- | --- |
| UART communication | Verified |
| NMEA reception | Verified |
| NMEA validity monitoring | Verified |
| NMEA checksum monitoring | Verified |
| UTC fields | Verified |
| Date | Verified |
| Combined time validity | Verified |
| Latitude magnitude | Verified |
| Longitude magnitude | Verified |
| Hemisphere handling | Verified |
| Signed coordinate conversion | Verified |
| Satellite count | Verified |
| Altitude | Verified |
| Valid position fix | Verified |

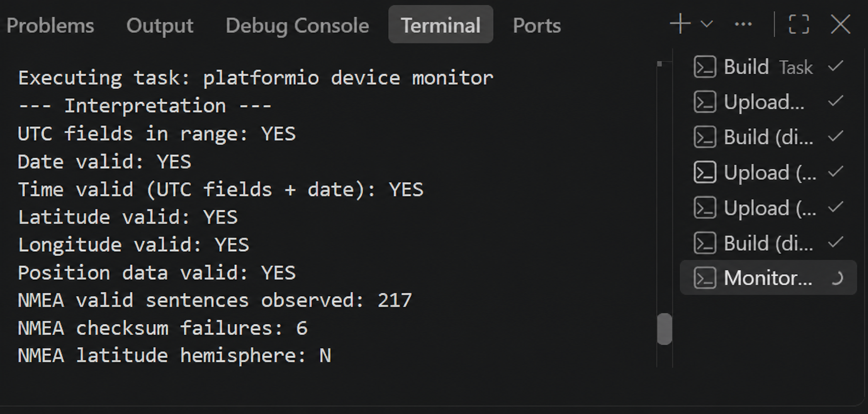
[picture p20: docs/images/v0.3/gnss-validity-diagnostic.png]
GNSS diagnostic showing UTC, date, position validity, NMEA counters, and hemisphere interpretation


*Basic validity evidence — UTC/date/time and position checks passed while valid-sentence and checksum counters remained visible. The personal command path was removed for publication.*

## 8. Raw coordinates, hemispheres, and signed values

The DFRobot library returns structured degrees/minutes components and decimal-degree magnitudes. On the tested module/library combination, the separate DFRobot direction-byte getters were malformed even though coordinate magnitudes and NMEA output were valid. The project therefore does not use those bytes to sign production coordinates.

The implemented interpretation path is:

```text
DFRobot raw coordinate components
        ↓
DFRobot decimal-degree magnitude
        +
checksum-valid NMEA N/S and E/W
        ↓
S or W negates the magnitude; N or E keeps it positive
        ↓
signed latitude / longitude
        ↓
validity and current-fix assessment
```

`diag_gnss.cpp` exposes the raw and interpreted values for diagnosis. Production signing occurs in `GPSManager::publishSnapshot()`. `GPSManager::currentFixIsValid()` requires at least one satellite, valid UTC and date, finite in-range magnitudes, and both NMEA hemispheres. The code intentionally does not patch generated `.pio/libdeps` library files.

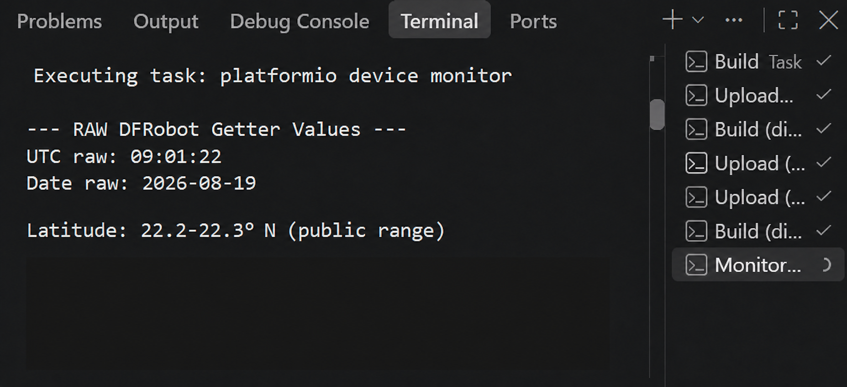
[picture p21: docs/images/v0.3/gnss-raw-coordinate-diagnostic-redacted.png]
GNSS raw-value diagnostic with the precise latitude replaced by a coarse public range


*Raw interpretation evidence — DFRobot UTC/date output remained visible; all precise latitude components were covered and replaced with a coarse public range.*

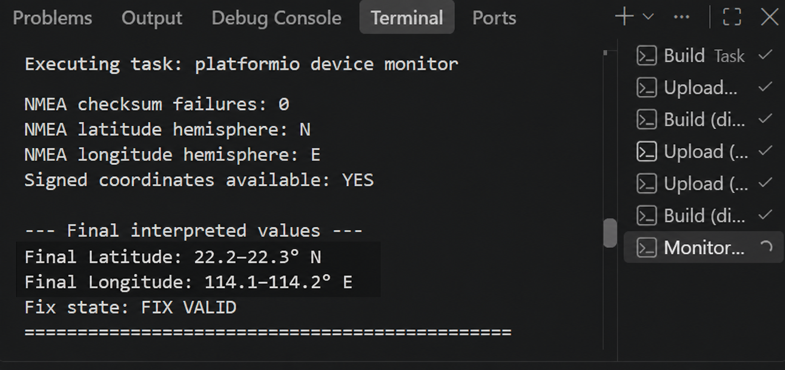
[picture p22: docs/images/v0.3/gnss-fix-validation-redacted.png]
GNSS diagnostic showing checksum, hemispheres, signed-coordinate availability, and valid fix


*Signed-coordinate and fix evidence — the N/E hemisphere interpretation and valid fix remain visible while exact coordinates are irreversibly redacted.*

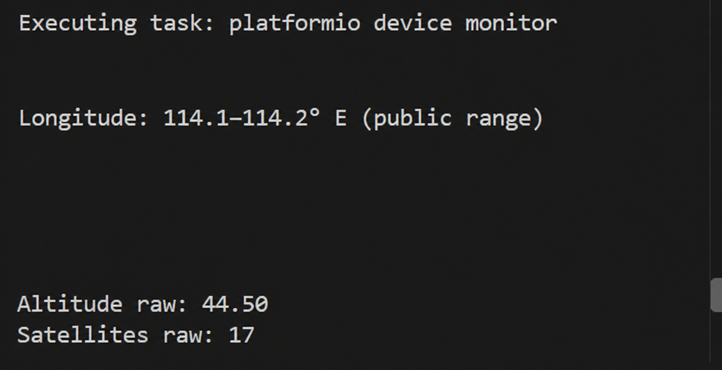
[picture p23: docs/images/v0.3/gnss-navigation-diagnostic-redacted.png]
GNSS navigation diagnostic showing altitude and satellite reporting with location redacted


*Navigation-data evidence — altitude and satellite reporting are retained; the precise longitude block and personal command path were replaced with public-safe text.*

## 9. Main firmware and `WeatherData`

`main.cpp` starts `GPSManager` when `EnableGnss` is true, copies its latest snapshot during normal loops and before upload, and includes GNSS status in structured Serial output. It does not put GNSS library calls into the sensor scheduler.

`WeatherData` now carries:

- `gnssCommunicationOk`, `gnssFixValid`, `gnssUtcValid`, and `GnssState`;
- GNSS year/month/day/hour/minute/second;
- signed latitude/longitude and altitude;
- satellites, speed, course, and constellation mode;
- last-successful-fix uptime;
- raw-byte, valid-sentence, and failed-checksum diagnostic counters.

The four production states are:

| State | Meaning | Uploaded position |
| --- | --- | --- |
| `NOT CONNECTED` | No recent NMEA communication | `null` |
| `COMMUNICATION OK - NO FIX` | Receiver is communicating but has not produced a valid fix | `null` |
| `FIX VALID` | Current fix passes validation and freshness checks | Signed values |
| `FIX STALE` | Communication continues but the last valid fix is no longer current | `null` |

Last successful values remain internally useful for diagnostics, but unavailable or stale positions are not presented as a false `0.0` coordinate.

## 10. JSON and network transmission

`WeatherDataSerializer` adds a nested `gnss` object to the existing `weather.measurement.v1` envelope:

| JSON field | Availability rule |
| --- | --- |
| `state` | Always present |
| `communication_ok`, `fix_valid` | Always present |
| `utc` | Present when the GNSS UTC snapshot is valid; otherwise `null` |
| `latitude`, `longitude` | Present only for `FIX VALID`; otherwise `null` |
| `altitude_m`, `speed_kmph`, `course_deg` | Present only for a valid current fix and finite value |
| `satellites` | Present when communication is current |
| `mode` | Present when the library mode maps to a known label |
| `last_successful_fix_ms` | Present after a successful fix |

GNSS uses the same 60-second HTTP snapshot schedule as the rest of `WeatherData`. No-fix or disconnected GNSS does not cancel an upload: environmental and particulate values continue through the v0.2 pipeline with GNSS fields marked unavailable.

See [Core v0.3 implementation notes](../core-v0.3.md) for the complete payload example.

## 11. Backend, SQLite, APIs, and display

### Validation and storage

The Pydantic `Gnss` model validates the four state strings and nullable UTC, latitude, longitude, altitude, satellites, speed, course, mode, and last-fix uptime. A missing `gnss` object defaults to `NOT CONNECTED`, preserving compatibility with v0.2 senders.

SQLite stores these columns:

```text
gnss_state, gnss_communication_ok, gnss_fix_valid, gnss_utc,
latitude, longitude, altitude, satellites, gnss_speed_kmph,
gnss_course_deg, gnss_mode, gnss_last_successful_fix_ms
```

Startup inspects `PRAGMA table_info(measurements)` and adds only missing GNSS columns. It does not drop the table or delete existing v0.2 observations. Both latest and history API responses reconstruct the nested `gnss` object from stored columns.

### Remote display

The dashboard's Location / GNSS group displays:

- fix state;
- satellites;
- signed latitude/longitude rendered with hemisphere labels;
- altitude;
- GNSS UTC.

It does not provide a map, route tracking, geofencing, or location-history chart.

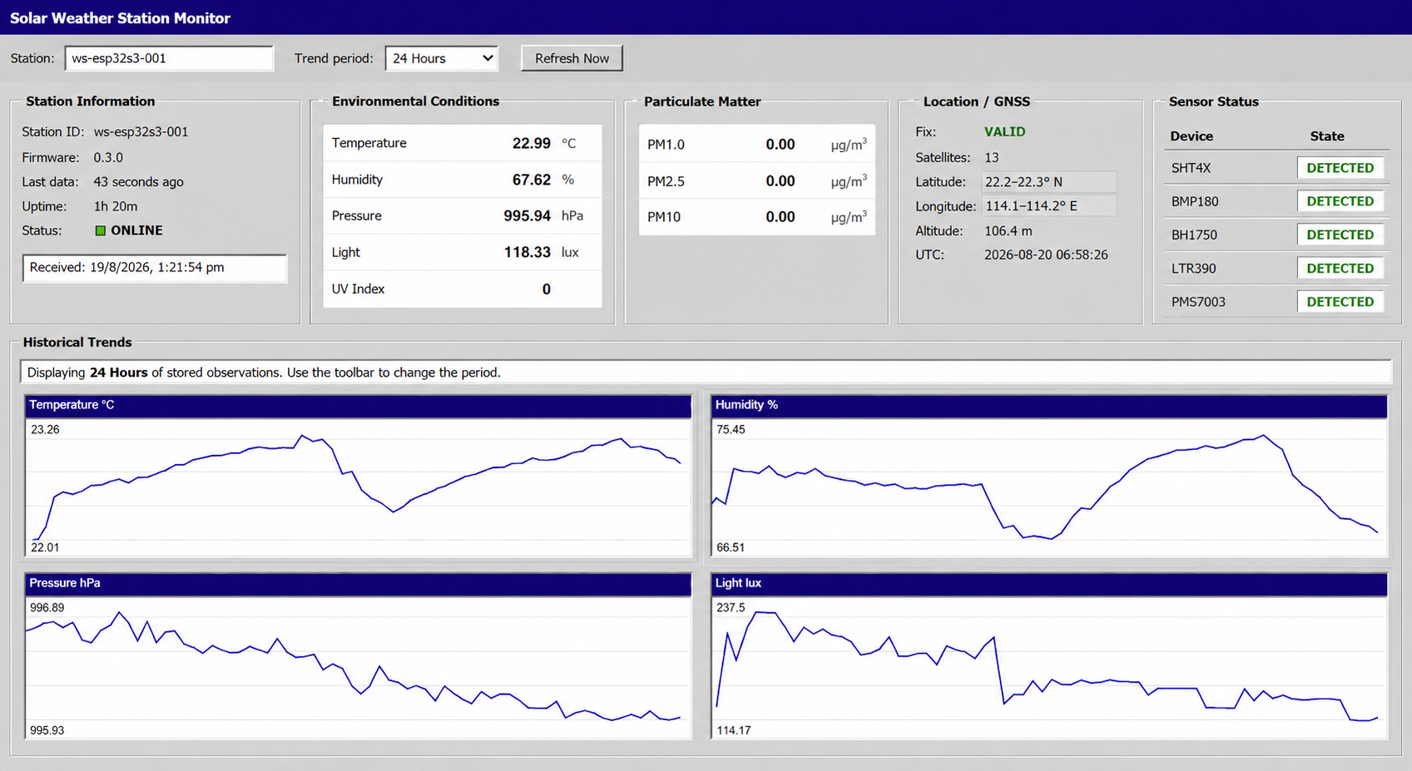
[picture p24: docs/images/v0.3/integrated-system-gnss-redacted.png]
Integrated v0.3 dashboard showing environmental, particulate, GNSS, health, and historical data


*v0.3 integrated verification — environmental, particulate, and GNSS data operating together through the complete station data pipeline. Location precision has been intentionally reduced for public documentation.*

### Integration verification

| End-to-end test | Result |
| --- | --- |
| Main firmware GNSS integration | Verified |
| Existing environmental sensors retained | Verified |
| PMS7003 retained | Verified |
| Wi-Fi and HTTP transmission | Verified |
| FastAPI validation | Verified |
| SQLite reception/storage | Verified |
| Latest/history API GNSS response | Verified |
| Remote GNSS display | Verified |

The integrated screenshot is evidence that the sensor system remained active while the dashboard received GNSS. Individual captured measurement, coordinate, UTC, altitude, and satellite values are observations from a test run, not permanent specifications.

## 12. Time sources

v0.3 contains four distinct time concepts:

| Time source | Role |
| --- | --- |
| ESP32 uptime | Scheduler timing, age/freshness, and `uptime_ms`; valid without network or fix |
| NTP | Supplies top-level `device_timestamp` when Wi-Fi time synchronization succeeds |
| GNSS UTC | Date/time belonging to the last valid GNSS fix; stored as `gnss.utc` |
| Backend receive UTC | `server_timestamp`, generated on ingestion and authoritative for SQLite ordering/dashboard freshness |

GNSS UTC does not replace NTP in v0.3. Before a valid fix, GNSS UTC can be `null`; uploads and backend timestamps continue independently.

## 13. Graceful degradation

The code supports this failure path:

```text
GNSS absent / no fix / stale fix
        ↓
explicit GNSS state + null current position
        ↓
I²C sensors and PMS7003 continue
        ↓
Wi-Fi/HTTP uploads continue
        ↓
backend and dashboard remain operational
```

A failed boot probe is retried every 60 seconds. A communicating receiver waiting for satellites is not repeatedly reset. The milestone evidence verifies integrated operation; long-duration antenna-disconnect and receiver-reconnect fault-injection logs remain desirable follow-up evidence.

## 14. Problems and engineering considerations

### Library direction bytes were unreliable

The official structured getters supplied useful magnitudes, but separate direction getters did not produce valid N/S/E/W values on the tested combination. The resolution was a small project-owned NMEA parser for checksum-validated hemisphere fields, leaving the dependency untouched.

### Communication is not the same as a fix

UART bytes, valid NMEA, valid time, valid magnitudes, hemispheres, and satellites are separate checks. The four-state model prevents “module connected” from being mistaken for “position current.”

### Checksums vary by run

One evidence capture shows checksum failures while another test run showed none. The counter is for trend/quality diagnosis, not a fixed pass threshold. A successful fix requires fix-bearing information from checksum-valid sentences.

### GNSS can expose sensitive location

The backend stores precise coordinates when a valid fix is uploaded. v0.3 has no authentication or TLS, so it must remain on a trusted development network. Logs, screenshots, database exports, issues, and examples must be reviewed before publication.

## 15. Privacy handling for public evidence

The original diagnostic and dashboard screenshots contained a precise real-world test location and personal Windows paths. Those originals remain outside the repository.

Public copies use irreversible opaque replacement, not blur:

- exact latitude and longitude components were completely covered;
- coarse ranges such as `22.2–22.3° N` and `114.1–114.2° E` were inserted;
- personal filesystem paths were replaced with generic PlatformIO task text;
- UTC/date, validity, NMEA counters, hemispheres, satellite count, altitude, fix state, and system evidence remain visible.

Public documentation must never treat the coarse values as the station's configured or permanent location.

## 16. Reproducing v0.3 end to end

1. Build the complete v0.1 sensor/PMS hardware and verify it using those diagnostics.
2. Start the v0.2 backend/dashboard and verify a non-GNSS measurement reaches SQLite.
3. Install and wire the TEL0157 as documented above.
4. Flash `diag_gnss`; verify UART, valid NMEA, UTC/date, position magnitudes, hemispheres, signed coordinates, satellites, altitude, and fix.
5. Restore `weather_station` and confirm firmware reports version `0.3.0` plus the pre-existing sensor readings.
6. Confirm GNSS progresses to `FIX VALID` without stopping scheduled sensor snapshots.
7. Confirm HTTP returns success and query `/api/v1/measurements/latest?station=...`.
8. Verify the nested `gnss` object and corresponding SQLite columns.
9. Open the dashboard and verify the Location / GNSS group alongside sensor health and trends.
10. If a stage fails, return to the smallest relevant diagnostic before changing production code. See [Troubleshooting](../troubleshooting.md).

## 17. Known limitations

- Position is current-fix telemetry, not tracking or location-history visualization.
- HDOP and other dilution/accuracy fields are not stored or used as acceptance thresholds.
- Fix timing, stale thresholds, and probe retry periods are compile-time constants.
- GNSS UTC is telemetry and does not discipline the device clock.
- The backend stores precise location without TLS, authentication, access control, or retention policy.
- Outdoor antenna/enclosure durability, cold/warm time-to-fix distribution, recovery logs, and long-duration reliability are not yet documented.
- Wind, rain, battery, solar, prediction, and autonomous operation remain unimplemented in the main station.

## 18. Final result and next milestone

v0.3 is complete and hardware verified. GNSS was validated independently before integration; the ESP32 now acquires explicit GNSS state and current-fix data without replacing the v0.1 sensors or v0.2 network pipeline. GNSS reaches JSON, FastAPI, SQLite, latest/history responses, and the remote display. Public evidence does not expose the precise test position.

The next planned milestone is **v0.4 — Wind Subsystem Integration**:

- integrate wind direction and speed through RS485/Modbus;
- resolve final UART/bus coexistence, including the preserved wind-speed UART0/debug-console conflict;
- extend `WeatherData`, JSON, backend schema/storage, and dashboard;
- verify wind and GNSS together with all previous sensors;
- capture combined reliability and failure-recovery evidence.

v0.4 remains planned; no wind production integration is claimed here.

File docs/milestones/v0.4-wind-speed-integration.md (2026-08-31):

# Core v0.4 — Wind Speed Integration

**Milestone status:** Software integration complete; full-station hardware verification pending.

The verified standalone RS485 wind-speed configuration is promoted into the production pipeline without integrating wind direction.

## Implemented

- SHT4x, BMP180, BH1750, and LTR390 environmental sensing remains active.
- PMS7003 and TEL0157/L76K GNSS remain active.
- Wind speed is acquired through `RS485Manager` with explicit health and recovery.
- Wi-Fi, NTP, HTTP upload, FastAPI, SQLite, dashboard, and history remain active.
- Existing `diag_i2c`, `diag_pms`, `diag_gnss`, `diag_wind_speed`, and `diag_wind_direction` environments remain available.

## Verified protocol boundary

The production driver uses the known-good 4800 8N1, slave 1, function `0x03`, register `0x0000`, one-register, `raw / 10.0 m/s` configuration on GPIO6 RX, GPIO7 TX, and GPIO5 DE/RE. Production changes only the UART peripheral allocation: UART0 is used because USB CDC carries debug output; the standalone diagnostic stays on UART1.

## End-to-end scope

Wind speed flows through `WeatherData`, nullable JSON, FastAPI validation, additive SQLite columns, latest/history APIs, a compact Wind dashboard group, Sensor Status, and the existing line-chart framework. A successful zero reading remains valid. Timeouts produce unavailable/null and do not stop any other subsystem.

## Deferred

- wind direction;
- rain;
- battery telemetry;
- solar telemetry;
- final power optimization.

See [Core v0.4 implementation notes](../core-v0.4.md) for allocation, schema, failure behavior, and the exact hardware test sequence.

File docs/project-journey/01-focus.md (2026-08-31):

# Gate 01: Focus

## Decision

Develop a modular Solar Weather Station that can observe local environmental conditions and make the engineering process inspectable. The project should connect sensing, communications, mechanical design, testing and responsible data release instead of treating them as separate demonstrations.

## Why this direction

Regional weather services describe broad conditions, but engineering decisions are often made at a specific site and height, near particular surfaces, buildings, vegetation or equipment. A local station can help investigate these differences when its placement, calibration and limitations are documented.

The challenge connects most directly to:

- **SDG 7:** future solar and battery operation must be measured rather than assumed;
- **SDG 9:** the project develops a reusable sensing and data infrastructure; and
- **SDG 13:** local observations may support climate-related investigation, but the station alone does not prove climate impact.

## Scope chosen

The first useful direction is an inspectable prototype that:

- reads several environmental sensors without one failure stopping the system;
- records whether each value is valid, stale or unavailable;
- exposes current and historical data on a trusted local network;
- keeps location and safety risks visible; and
- can be extended and reproduced from public source files.

## Directions not selected

- a commercial weather service;
- a certified meteorological instrument;
- a public cloud monitoring product;
- an autonomous outdoor station before power and enclosure testing; and
- a sustainability claim based only on using a solar panel.

## Gate decision

Proceed to problem definition with a local microclimate and engineering-validation focus. Keep the intended user, deployment site, reference method and field decision open until they are supported by evidence.

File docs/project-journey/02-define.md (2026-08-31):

# Gate 02: Define

## Working problem

Teams investigating a local environment need a traceable way to collect site-specific observations and judge whether the sensing system itself is reliable enough for the next test. A reading without sensor health, placement context, time, configuration and known limits is difficult to trust or reproduce.

## Intended users and decisions

The current system is designed for engineering teams conducting supervised bench and site tests. It should help them decide whether to:

- continue with the current configuration;
- revise a sensor, interface, enclosure or software path;
- return a subsystem to isolated bench testing; or
- retain the work as a reference without making a field-performance claim.

## Evidence boundary

The current repository supports claims about staged prototype integration. It does not yet support claims of:

- meteorological-grade accuracy;
- weatherproof or unattended outdoor operation;
- reliable solar energy balance;
- long-duration field reliability;
- environmental benefit or carbon reduction; or
- safe exposure of precise GNSS data on the public internet.

## Success criteria for the present prototype

1. The documented firmware environments build from a clean checkout.
2. Each active sensor reports explicit health and unavailable values remain distinct from valid zero readings.
3. A failed sensor or network path does not stop unrelated sensing.
4. The backend validates, stores and returns compatible measurement records.
5. The dashboard presents current data, health and history without hiding missing values.
6. A reproducer can find wiring, configuration, CAD, tests and known limitations from the repository front page.

## Evidence still needed before field use

- an approved site and responsible authority;
- the exact mounting location and exposure conditions;
- a documented comparison or reference instrument;
- complete power, enclosure and retrieval checks; and
- stop criteria for unsafe or unreliable operation.

## Gate decision

Use staged engineering reliability as the immediate problem. Treat any outdoor environmental interpretation as a later validation task, not as a property already established by the prototype.

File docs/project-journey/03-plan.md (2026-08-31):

# Gate 03: Plan

## Selected route

Build a modular station around an ESP32-S3 and keep acquisition, health tracking, communications, storage and presentation separate enough to test independently.

```mermaid
flowchart LR
    S[Sensor diagnostics] --> F[Integrated firmware]
    F --> J[Versioned JSON]
    J --> A[FastAPI validation]
    A --> Q[(SQLite)]
    Q --> D[Dashboard and history]
```

## Main design decisions

| Decision | Selected approach | Reason |
| --- | --- | --- |
| Controller | ESP32-S3 | Multiple interfaces, Wi-Fi, native USB and supported PlatformIO workflow |
| Sensor integration | Dedicated drivers with shared `WeatherData` and health state | One failed device should not invalidate the entire station |
| Bring-up | Separate PlatformIO diagnostic environments | Wiring and protocol faults can be isolated before integration |
| Data transport | Periodic local HTTP upload | Small, inspectable v0.2 path without a broker or cloud dependency |
| Backend | FastAPI + SQLite | Typed validation, simple local persistence and testable endpoints |
| Schema evolution | Nullable fields and additive database migration | Older records remain readable as new sensors are added |
| GNSS | Independent worker and explicit no-fix state | Waiting for a fix must not stop other sensing or NTP |
| Wind speed | Dedicated RS485 worker | Modbus timeouts must not block the main acquisition path |
| Mechanical design | Editable Fusion 360 modules | Enclosure, power section and connecting base can be revised separately |

## Build sequence

1. Verify each bus and sensor in isolation.
2. Integrate core environmental and particulate sensing.
3. Add local networking, storage and dashboard behavior.
4. Diagnose GNSS independently, then add it without coupling time or sensing to a valid fix.
5. Verify wind speed on RS485, then promote only the verified protocol into production.
6. Complete combined hardware verification before adding rain or power telemetry.
7. Measure power and enclosure performance before autonomous outdoor operation.

## Risk controls

- keep credentials outside version control;
- keep precise location data off public systems;
- use a trusted local network because HTTP has no TLS or authentication;
- use 3.3 V-compatible logic at ESP32 pins;
- isolate the 12 V wind-sensor supply and protect outdoor cabling;
- keep planned, compiled, bench-verified and field-verified work visibly different; and
- require an approved site and safe retrieval plan before outdoor deployment.

## Gate decision

Proceed with the staged modular route. A commercial or borrowed reference instrument should be used during later field comparison; it is a validation reference, not a replacement for the inspectable prototype.

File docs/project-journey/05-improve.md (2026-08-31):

# Gate 05: Improve

Testing exists to support the next engineering decision, not to produce a successful-looking demonstration.

## What the current evidence supports

- the core environmental and particulate sensors operated together on the v0.1 bench prototype;
- the v0.2 local upload, validation, storage and dashboard path operated end to end;
- the installed GNSS interface and full v0.3 path were hardware verified;
- backend tests cover validation, null handling, database migration, GNSS, wind, legacy payloads and dashboard assets;
- all firmware environments can be compiled independently; and
- the wind-speed protocol was observed with the standalone diagnostic.

## What remains uncertain

- Core v0.4 has not completed the full combined hardware sequence;
- wind direction remains outside production;
- sensors have not been compared against a documented reference for accuracy claims;
- the enclosure has not passed ingress, thermal or radiation-shield testing;
- battery endurance and solar energy balance have not been measured; and
- no approved long-duration field record supports unattended operation.

## Next decision sequence

1. Run the complete v0.4 hardware procedure with all existing subsystems active.
2. Record Serial, API, database and dashboard evidence for normal, calm, disconnected and recovered wind states.
3. Update the [test matrix](../../tests/test-matrix.csv) with the commit, hardware revision and result.
4. If v0.4 passes, measure complete-system power before adding autonomous operation.
5. Complete enclosure and field-readiness checks before any supervised outdoor run.
6. Compare priority measurements with a documented reference and narrow any unsupported claim.

## Iteration rule

A failed test should change a driver, interface, mechanical feature, procedure or claim. Preserve the failed evidence and the reason for the next decision. Do not replace an unavailable value with zero or hide a known limitation in the dashboard.

## Gate decision

Hold feature expansion until combined v0.4 verification is complete. Rain, power telemetry and autonomous field operation remain separate future decisions.

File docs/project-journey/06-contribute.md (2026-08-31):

# Gate 06: Contribute

The project is useful to another person only when they can understand what exists, reproduce the supported parts and see the limits before extending it.

## What this release provides

- ESP32-S3 production firmware and isolated diagnostics;
- a typed FastAPI service, SQLite storage and browser dashboard;
- automated backend tests and firmware build checks;
- pin allocation, wiring, BOM and power notes;
- editable Fusion 360 source and mechanical assembly guidance;
- chronological milestone records and privacy-reviewed evidence;
- a system test matrix and field-readiness checklist;
- contribution, security, AI-use and third-party dependency guidance; and
- an MIT licence for original project content.

## Responsible release checks

Before publishing a new release:

1. verify the release commit builds and automated tests pass;
2. state which hardware procedure was run and what was observed;
3. update the status table, test matrix and affected milestone record;
4. remove credentials, private endpoints and precise location data;
5. review images, logs and databases for personal or site-sensitive information;
6. confirm third-party attribution and licence obligations;
7. distinguish planned, compiled, bench-verified and field-verified claims; and
8. list known limitations and the next evidence needed.

The complete maintainer checklist is in [`docs/release-checklist.md`](../release-checklist.md).

## How others can build on the work

Start with the README route that matches the intended task. Use a diagnostic before changing an integrated driver. Open an Issue before changing pins, schemas or milestone scope. Submit one focused Pull Request with the exact test and evidence boundary.

Teaching, demonstration and documentation may help another person use the work. The durable contribution is the repository itself: source, editable design files, evidence, decisions, licence and honest limits.

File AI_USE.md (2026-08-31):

# AI-Assisted Work

AI tools may support research, drafting, coding, debugging and review. They do not replace engineering responsibility or evidence.

## Required practice

- A named contributor reviews every AI-assisted change before it is merged.
- Code must build and pass the relevant automated or hardware test.
- Generated citations, component specifications, register maps and licence claims must be checked against primary sources.
- AI output is not hardware evidence, stakeholder evidence or a test result.
- Credentials, private data, exact restricted locations and unpublished course material must not be entered into an unapproved external service.
- Material AI assistance should be summarised in the Pull Request when it affected architecture, code, test design or public documentation.

## Suggested Pull Request record

```text
AI tool and purpose:
Files or decisions affected:
Human checks performed:
Tests and evidence:
Known uncertainty:
```

The contributor remains responsible for correctness, safety, attribution, privacy and the final engineering claim.

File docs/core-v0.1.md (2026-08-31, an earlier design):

# Core Integrated Prototype v0.1

Core v0.1 initializes the shared I2C bus, scans it once, initializes each environmental driver independently, starts PMS7003 UART, and uses `millis()` scheduling. Environmental reads run every 5 seconds, PMS acquisition every 10 seconds with a bounded 1.5-second timeout, and a structured snapshot prints every 10 seconds.

`WeatherData` is the single measurement model. Each active subsystem has `SensorHealth` containing initialization state, latest-value validity, staleness, last successful read time, consecutive failures, and total failures. Consumers must check health before using a numeric field; genuine zero remains valid while unavailable data prints as `unavailable`.

Disconnected I2C devices do not abort startup and their initialization is retried on later environmental cycles. PMS checksum/length/header validation remains in the existing parser. GNSS, RS485, rain, power telemetry, and Wi-Fi are not initialized by the core application.

Expected startup I2C addresses are SHT4x `0x44`, BMP180 `0x77`, BH1750 `0x23` or `0x5C`, and LTR390 `0x53`. The code names the family SHT4x because the exact SHT40/SHT41 fitted variant has not been independently established; the existing Adafruit SHT4x driver is retained.

v0.2 subsequently implemented this boundary: it consumes a `WeatherData` snapshot after health/validation, serializes invalid or stale fields as JSON `null`, and keeps networking out of sensor drivers. See the [v0.1 milestone record](milestones/v0.1-core-sensors.md) for the engineering history and [v0.2 implementation notes](core-v0.2.md) for the connected path.

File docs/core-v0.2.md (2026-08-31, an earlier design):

# Core v0.2 networking and remote data

**Status:** Implemented and tested as a local-network prototype. For reproduction evidence and milestone scope, see [v0.2 — Connected IoT Prototype](milestones/v0.2-connected-iot.md).

Core v0.2 adds an optional network consumer after the verified v0.1 `WeatherData` path. It does not change the SHT4x, BMP180, BH1750, LTR390, or PMS7003 drivers.

## Firmware behavior

`NetworkManager::tick()` uses `DISABLED`, `CONNECTING`, `CONNECTED`, `DISCONNECTED`, and `RETRY_WAIT` states. `WiFi.begin()` starts an asynchronous attempt. The scheduler never waits in a connection or NTP loop. A connection attempt times out after 15 seconds and is retried after 30 seconds. NTP is requested after connection and checked without blocking; failure leaves `device_timestamp` null.

`HttpDataUploader` owns a one-element overwrite queue and a FreeRTOS worker. The scheduler copies the current snapshot to the queue every 60 seconds. The worker serializes and posts it with a 3-second connect timeout and 5-second HTTP timeout. It records successful uploads, failed uploads, consecutive failures, last successful upload uptime, and the last response code. There is no immediate retry loop: recovery occurs at the next upload interval.

The one-element queue deliberately represents “latest current conditions,” not an offline spool. Data missed while the backend is down is not backfilled by the ESP32; future successful snapshots resume normal recording.

## JSON schema

Unavailable or stale readings are `null`, so a real zero remains distinct from a failed sensor.

```json
{
  "schema_version": "weather.measurement.v1",
  "station_id": "ws-esp32s3-001",
  "firmware_version": "0.2.0",
  "uptime_ms": 123456,
  "device_timestamp": null,
  "environment": {
    "temperature_c": 24.1,
    "humidity_percent": 66.3,
    "pressure_hpa": 994.2,
    "light_lux": 250.4,
    "uv_index": 1.2
  },
  "particulate": {
    "pm1_ugm3": 3,
    "pm25_ugm3": 7,
    "pm10_ugm3": 10
  },
  "health": {
    "sht4x": {
      "initialized": true,
      "valid": true,
      "stale": false,
      "consecutive_failures": 0,
      "total_failures": 0
    },
    "bmp180": { "initialized": true, "valid": true, "stale": false, "consecutive_failures": 0, "total_failures": 0 },
    "bh1750": { "initialized": true, "valid": true, "stale": false, "consecutive_failures": 0, "total_failures": 0 },
    "ltr390": { "initialized": true, "valid": true, "stale": false, "consecutive_failures": 0, "total_failures": 0 },
    "pms7003": { "initialized": true, "valid": true, "stale": false, "consecutive_failures": 0, "total_failures": 0 }
  }
}
```

When NTP has synchronized, `device_timestamp` is UTC ISO 8601 such as `2026-08-19T10:30:00Z`. The backend always adds its own `server_timestamp`.

## Failure cases

- Wi-Fi unavailable at boot: sensor initialization/reads proceed; Wi-Fi enters timed retry cycles; no reboot occurs.
- Wi-Fi lost: measurements and serial snapshots continue; reconnect happens in `tick()`.
- Backend unavailable or an HTTP timeout occurs: the worker records one failure and waits for the next scheduled snapshot.
- Backend returns non-2xx: the response code and failure counters update; acquisition continues.
- NTP unavailable: uptime and backend receive timestamps remain usable.

## Storage and extension

SQLite stores identifiers, timestamps, firmware/uptime, all eight current measurements, five sensor-valid flags, and full health JSON. Adding nullable columns later for wind, rain, GNSS, battery, and solar does not require changing the current sensor drivers. Prediction is intentionally absent; a future backend module can consume stored history without changing ingestion.

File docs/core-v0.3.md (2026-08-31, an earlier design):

# Core v0.3 — GNSS Integration

**Status:** Complete / hardware verified. See the [v0.3 milestone record](milestones/v0.3-gnss-integration.md) for staged diagnostic evidence, integrated verification, public image sanitization, and reproduction guidance.

Core v0.3 integrates the verified DFRobot Gravity TEL0157 / Quectel L76K into the production `weather_station` firmware while preserving the Core v0.2 sensor, network, backend, storage, dashboard, and diagnostic paths.

## Production architecture

The official `DFRobot_GNSS` library owns UART1 at 9600 baud. All library probes and reads run in the dedicated priority-1 `gnss-worker` FreeRTOS task. The Arduino scheduler calls `GPSManager::update()`, which only copies a short critical-section-protected snapshot into `WeatherData`. A slow or absent GNSS receiver therefore cannot block environmental sensing, PMS reads, Wi-Fi maintenance, HTTP scheduling, or Serial snapshots.
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

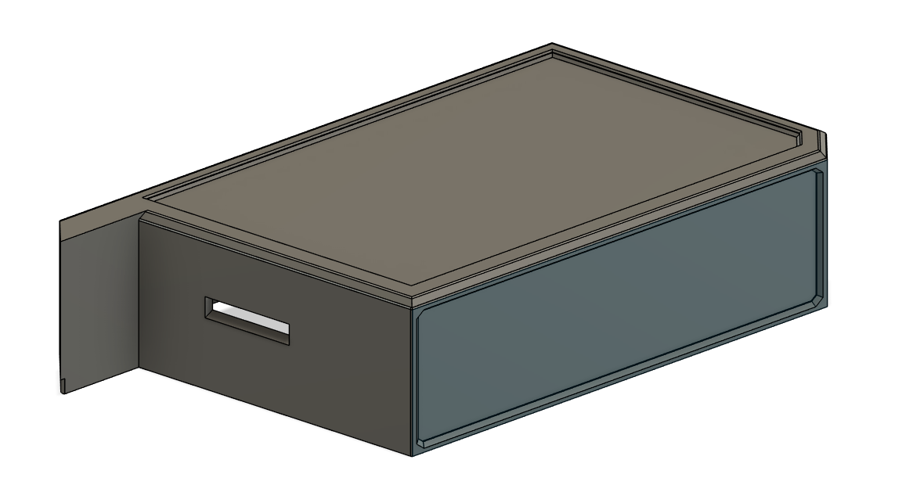
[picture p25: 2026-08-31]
hardware/cad/images/power-module-cover-cad.png

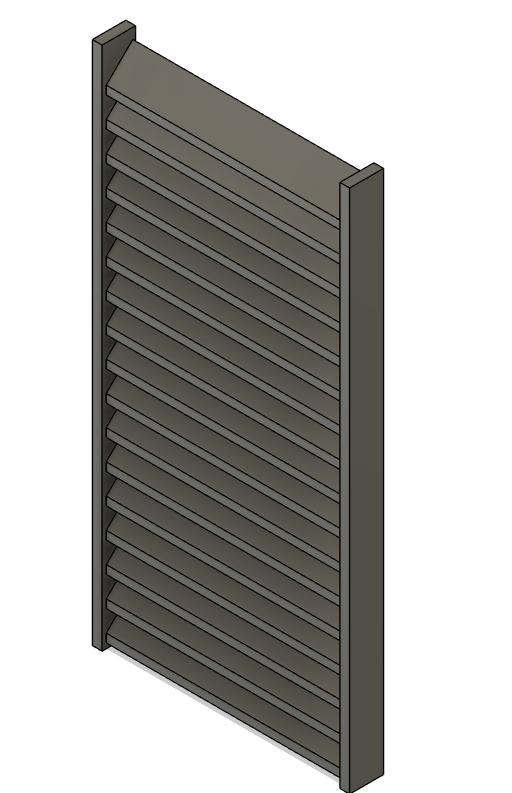
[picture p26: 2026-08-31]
hardware/cad/images/vent-cad.png

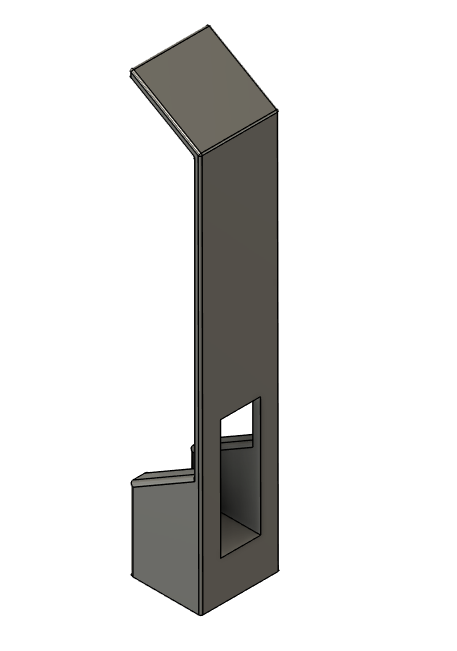
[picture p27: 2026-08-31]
hardware/cad/images/cable-slot-cad.png

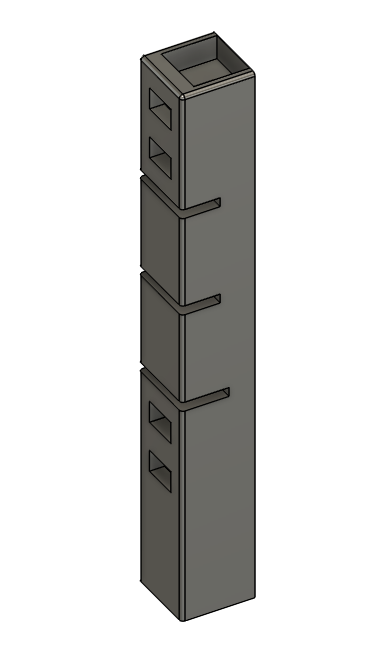
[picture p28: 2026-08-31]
hardware/cad/images/sensor-rod-cad.png

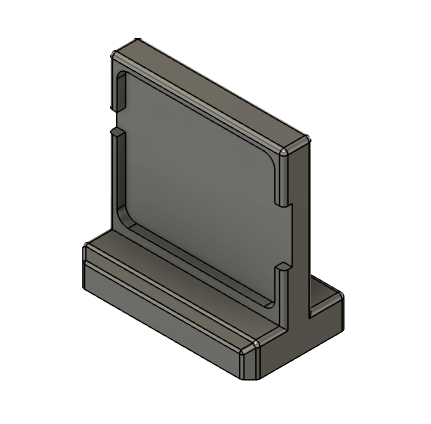
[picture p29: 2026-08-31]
hardware/cad/images/gnss-mount-cad.png

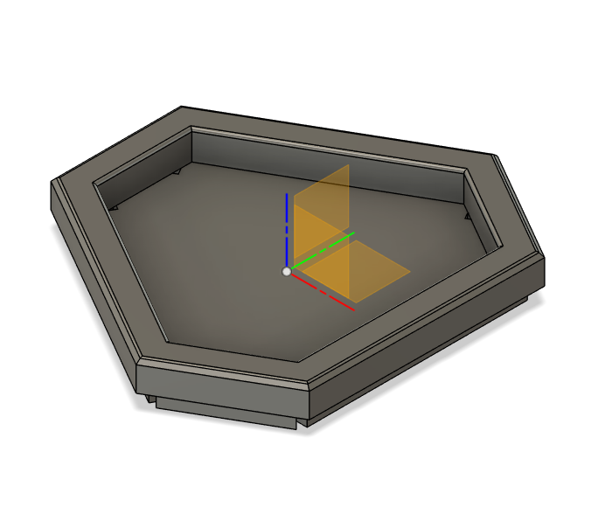
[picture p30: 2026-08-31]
hardware/cad/images/lid-cad.png

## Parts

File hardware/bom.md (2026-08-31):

# Bill of Materials and Hardware Status

This BOM separates the verified v0.1–v0.3 bench prototype, the Core v0.4 wind-speed integration and deferred field hardware. Confirm exact board/module revisions, connector families, mounting hardware, prices and suppliers before treating it as a purchase-ready BOM.

## Current integrated prototype

| Item | Qty | Status | Notes |
| --- | ---: | --- | --- |
| ESP32-S3 development board | 1 | Integrated | PlatformIO target is `esp32-s3-devkitc-1`; confirm the physical board revision |
| SHT4x breakout | 1 | Hardware verified | Exact SHT40/SHT41 fitted variant not independently established; I²C `0x44` |
| BMP180 breakout | 1 | Hardware verified | I²C `0x77`; this corrects the earlier draft BOM's BMP390 entry |
| BH1750 breakout | 1 | Hardware verified | I²C `0x23` or `0x5C` |
| LTR390 breakout | 1 | Hardware verified | I²C `0x53`; UV index is an estimate in current firmware |
| PMS7003 | 1 | Hardware verified | 5 V particulate sensor, UART 9600 baud, SET control |
| Perfboard/interface connector assembly | 1 | Integrated prototype | Point-to-point prototype documented in v0.1 images |
| Printed Weather Station Body, Power Module and Connecting Base | 1 set | Printed and fit checked | Editable Fusion 360 sources are included; weatherproofing and outdoor durability are not verified |
| Data-capable USB cable and suitable bench supply | 1 each | Required for development | Supply must handle ESP32 Wi-Fi and PMS peaks |

## Additional and deferred hardware

| Item | Qty | Status | Notes |
| --- | ---: | --- | --- |
| DFRobot Gravity TEL0157 / Quectel L76K GNSS module with active antenna | 1 | Hardware verified in v0.3 | Official range 3.3–5.5 V; project uses 3V3, UART selector position, UART1 at 9600 baud |
| RS485 wind speed sensor | 1 | Diagnostic hardware verified; production software integrated | 12 V Modbus RTU; combined Core v0.4 hardware verification remains pending |
| RS485 wind direction sensor | 1 | Diagnostic available | 12 V Modbus RTU; production integration planned for v0.4 |
| 3.3 V-compatible RS485 transceiver | 1 | Diagnostic hardware | MAX3485-class; do not use 5 V logic at ESP32 pins |
| Tipping-bucket rain gauge | 1 | Planned | Bucket calibration and debounce not verified |
| Protected 1S3P 18650 pack/holder/BMS | 1 | Planned | Cell selection and protection require safety review |
| Waveshare Solar Power Manager (D) | 1 | Planned | Earlier power-system choice; autonomous operation not verified |
| 6 V 5 W solar panel | 1 | Preliminary | Starting estimate only; energy balance not measured |
| 12 V boost converter | 1 | Planned | For wind sensors; efficiency/current not verified |
| Logic-level MOSFET/load switch | 1 | Planned | Optional switched wind rail |
| Battery/solar voltage dividers and protection | 2 channels | Planned | ADC scaling and calibration not verified |
| Outdoor enclosure, glands, vents, radiation shield | 1 set | Planned | Must address ingress, condensation, airflow, heating, and UV exposure |

See [pin allocation](../docs/pin-allocation.md), [wiring](wiring.md), [power-system notes](power-system.md) and the [mechanical CAD catalog](cad/README.md). The repository includes editable Fusion 360 enclosure sources but does not yet include a supplier-and-price-locked procurement BOM, PCB fabrication files, exported STL files or an audited measured power budget.

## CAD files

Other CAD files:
hardware/cad/assembly/connecting-base.f3d
hardware/cad/power-module/power-module-cover.f3d
hardware/cad/power-module/power-module-mount.f3d
hardware/cad/station-body/cable-slot.f3d
hardware/cad/station-body/gnss-mount.f3d
hardware/cad/station-body/lid.f3d
hardware/cad/station-body/main-body-shell.f3d
hardware/cad/station-body/sensor-rod-lid.f3d
hardware/cad/station-body/sensor-rod.f3d
hardware/cad/station-body/vent.f3d

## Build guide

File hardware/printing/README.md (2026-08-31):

# 3D-printing guide

The current mechanical prototype was developed for PLA printing. Fusion 360 (`.f3d`) remains the released editable source format; export a mesh from the applicable file in the [CAD index](../cad/README.md) when preparing a print.

## Prototype printing configuration

### Common settings

- Model material: PLA
- Slicer settings: normal/default PLA profile
- Supports: **enabled for every printed part**

The project intentionally does not prescribe a nozzle size, layer height, infill, wall count, nozzle or bed temperature, print speed, support angle, or support density because those values were not supplied. Confirm the Fusion document units before export and do not rescale by assumption.

### Power Module Mount exception

The Power Module Mount uses a different support-material configuration:

- Model material: PLA
- Supports: enabled
- Support material: dedicated `Support for PLA` material

The support body/interface split is not documented. Do not infer which portion uses the dedicated material; configure the support system according to the printer/slicer capability while preserving the stated `Support for PLA` requirement.

## Printable-part and quantity table

| Part | Qty. | Model material | Supports | Support material | Evidence status |
| --- | ---: | --- | --- | --- | --- |
| Main body shell | 1 | PLA | Enabled | Standard | Printed and integrated |
| Lid | 1 | PLA | Enabled | Standard | Printed and integrated |
| Vent | 3 | PLA | Enabled | Standard | Printed and integrated; weatherproofing unverified |
| Sensor rod | 1 | PLA | Enabled | Standard | Printed and integrated |
| Sensor-rod lid | 1 | PLA | Enabled | Standard | Released model; not independently visible in photographs |
| Cable slot | 1 | PLA | Enabled | Standard | Released model; not independently visible in photographs |
| GNSS mount | 1 | PLA | Enabled | Standard | Printed and integrated |
| Power-module mount | 1 | PLA | Enabled | **`Support for PLA`** | Printed and integrated |
| Power-module cover | 1 | PLA | Enabled | Standard | Printed and integrated |
| Connecting base | 1 | PLA | Enabled | Standard | Designed, printed, fit verified, and integrated |

“Standard” means the ordinary support configuration associated with the selected normal/default PLA profile; it does not mean the dedicated product named `Support for PLA`. Support geometry and interface settings remain at the slicer's normal/default values because no project-specific values were supplied.

The complete print set contains ten part types and twelve pieces because three identical vents are required.

## Print workflow

1. Open the required `.f3d` file from the [CAD index](../cad/README.md) in Fusion 360.
2. Confirm the model's document units, then export an STL or 3MF for the slicer without changing scale.
3. Select PLA and the printer's normal/default PLA profile.
4. Enable supports for every part.
5. For the Power Module Mount, configure the support system to use `Support for PLA`; keep the model itself in PLA.
6. Inspect the sliced layers for missing geometry, unintended scaling, and inaccessible support material before printing.
7. Remove supports, clean mating surfaces and cable passages, then dry-fit before installing electronics.

## Post-processing and fit checks

- Remove support material without cutting into rails, slots, board ledges, cover interfaces, or the connecting-base footprints.
- Deburr cable passages and check that no printed edge can abrade insulation.
- Dry-fit the three vents, lid, sensor rod and lid, cable slot, GNSS mount, power-module mount and cover, and connecting base.
- Check that the PMS7003 openings remain unobstructed and that sensor faces are exposed as intended.
- Confirm that the 18650 pack and both power boards are restrained without compressing cells or shorting contacts.
- Reject cracked, warped, delaminated, or heat-damaged parts.

## Remaining reproducibility work

- Record the exact printer and saved slicer profile used in the next controlled build.
- Add verified STL or 3MF exports if the project later chooses to distribute ready-to-slice files.
- Measure critical fits and define clearances in CAD rather than compensating with undocumented slicer scaling.
- Record fastening or retention methods once confirmed by the original design or a controlled rebuild.

Continue with the [mechanical assembly guide](assembly-guide.md). Electrical connections remain documented in the separate [wiring guide](../wiring.md) and [power-system notes](../power-system.md).

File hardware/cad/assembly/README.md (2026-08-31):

# Connecting Base

- **File:** [`connecting-base.f3d`](connecting-base.f3d)
- **Quantity:** 1
- **Status:** Designed, printed, fit verified, and integrated

## Purpose

The Connecting Base mechanically joins the pentagonal Weather Station Body footprint to the rectangular Power Module footprint. It establishes the intended relative position of the two main assemblies and forms the complete station structure shown in the physical prototype.

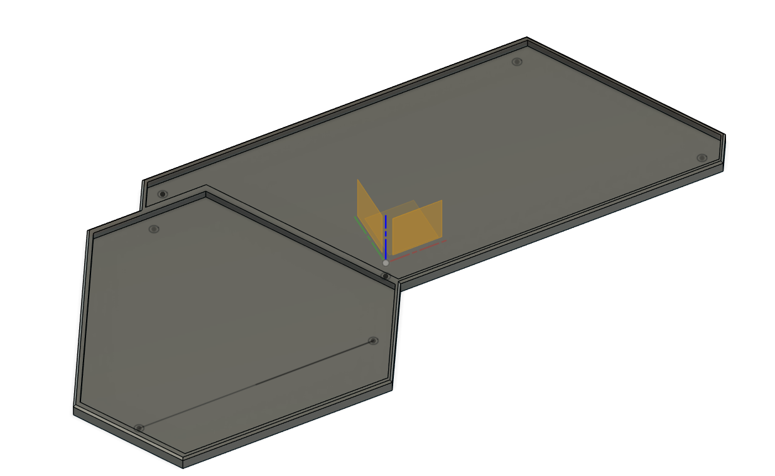
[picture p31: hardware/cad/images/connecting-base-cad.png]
Connecting-base CAD preview extracted from the supplied mechanical reference


## Installation

- Orient the pentagonal end under the Weather Station Body.
- Orient the long rectangular end under the Power Module Assembly.
- Seat both assemblies in their matching footprints so the Power Module extends horizontally from the station body.
- Check the connecting cable path before final seating so wiring is not trapped between either enclosure and the base.

No screw, clip, or adhesive specification was supplied, so no attachment hardware is prescribed here.

## Printing

- Model material: PLA
- Profile: normal/default PLA printing profile
- Supports: enabled
- Support material: standard support configuration from the default PLA setup

No numeric slicer settings or support-interface configuration have been supplied.

Complete mechanical prototype — the main weather-station enclosure and power-module assembly joined using the Connecting Base

The photograph verifies the printed fit and integration of both major assemblies. It does not establish outdoor or weather certification.

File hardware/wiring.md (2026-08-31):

# Wiring Overview

The core v0.1 wiring below reflects the current code. Confirm the exact ESP32-S3 board and every breakout's voltage/pin labels before wiring; deferred subsystems remain preliminary.

Start from the [pin allocation](../docs/pin-allocation.md). Labeled prototype views are in the [v0.1 milestone record](../docs/milestones/v0.1-core-sensors.md#9-images-and-evidence).

## Verified v0.1 connections

| Subsystem | ESP32-S3 connection | Notes |
| --- | --- | --- |
| Shared I²C | SDA GPIO8, SCL GPIO9 | 100 kHz; SHT4x, BMP180, BH1750, LTR390 |
| PMS7003 UART | RX GPIO16, TX GPIO17 | Cross TX/RX; 9600 baud |
| PMS7003 SET | GPIO18 | Sleep/wake control |

The Core v0.4 production `weather_station` firmware initializes GNSS and RS485 wind speed in addition to the v0.2 hardware. Wind direction, rain, battery, solar, and SD remain deferred.

## TEL0157 GNSS production and diagnostic wiring

The `diag_gnss` PlatformIO environment targets the DFRobot Gravity TEL0157
(Quectel L76K) in **UART** mode. Move the module's interface selector to
**UART with power removed**, then wire the crossed data lines as follows:

| TEL0157 connection | ESP32-S3 connection | Purpose |
| --- | --- | --- |
| VCC (`+`) | 3V3 | The official module range is 3.3-5.5 V; 3.3 V is used here |
| GND (`-`) | GND | Common signal and power ground |
| TX (`D/T`) | GPIO15 (ESP32 RX, UART1) | GNSS TX -> ESP32 RX |
| RX (`C/R`) | GPIO14 (ESP32 TX, UART1) | GNSS RX -> ESP32 TX |

The included active antenna must be firmly connected to the IPEX1 socket.
Test outdoors or with a clear view of the sky and allow several minutes for a
cold fix. A red module indicator means no fix; green means a fix is acquired.
The diagnostic does not reboot or reconfigure a communicating receiver merely
because it is still waiting for satellites.

### TEL0157 UART direction-field workaround

Real-hardware testing with `DFRobot_GNSS` 1.0.0 returned valid latitude and
longitude magnitudes but invalid `latDirection`/`lonDirection` bytes. The
library's C++ register constants and getter logic differ from its Python
implementation: the C++ direction-register names are reversed, and the C++
getters discard the sixth byte from each six-byte coordinate block before
performing a separate direction read. The project does not patch generated
`.pio/libdeps` files. Instead, the official structured getters remain the
primary data source, while `GnssNmeaHemisphere` extracts only checksum-valid
N/S and E/W fields from official `getAllGnss()` GGA, RMC, or GLL output. A
verified outdoor diagnostics confirmed these NMEA signs for Core v0.3 production
integration. The `diag_gnss` raw and direction-byte output remains available.

## Wiring Rules

- Keep I2C wires short and use pull-ups to 3.3V only.
- Do not connect 5V logic directly to ESP32-S3 GPIO.
- Use a 3.3V-compatible RS485 transceiver.
- Wire RS485 transceiver RO to ESP32-S3 GPIO6, DI to GPIO7, and shared DE/RE control to GPIO5.
- Power 12V wind sensors from a separate boost converter or 12V supply rail.
- Use resistor dividers for battery and solar voltage ADC measurement.
- Add transient protection for outdoor cables where possible.

## RS485 wind-speed production wiring

| Connection | ESP32-S3 / station connection |
| --- | --- |
| Transceiver RO | GPIO6 (UART0 RX in production) |
| Transceiver DI | GPIO7 (UART0 TX in production) |
| Transceiver DE + /RE | GPIO5; LOW receive idle, HIGH transmit |
| Sensor A/B | Transceiver A/B |
| Sensor supply | Correct external 12 V rail |
| Grounds | ESP32, transceiver, and sensor supply common ground |

The fixed sensor protocol is Modbus RTU, 4800 baud, 8N1, slave 1, function `0x03`, holding register `0x0000`, one register, scaled as `raw / 10.0 m/s`. Do not substitute a zero value for a timeout.

## Reproduction sequence

1. With power removed, check every supply and signal against the breakout labels and board schematic.
2. Bring up the shared bus with `diag_i2c`; do not add PMS7003 until all expected addresses appear.
3. Test the PMS7003 separately with `diag_pms`.
4. Install GNSS, flash `diag_gnss`, and independently verify UART, NMEA/checksums, UTC/date, position validity, hemispheres, satellites, altitude, and a fix.
5. Flash `weather_station` only after the sensor, PMS7003, and GNSS interfaces pass in isolation.
6. Use strain relief and recheck continuity after fitting the prototype frame.

The photographed frame is evidence of prototype fit only. It is not verified as weatherproof, UV-resistant, condensation-safe, or an adequate solar-radiation shield.

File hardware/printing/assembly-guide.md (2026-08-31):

# Mechanical assembly guide

This sequence reconstructs the supplied prototype at a practical, non-electrical level. It does not establish a production enclosure or a weatherproof installation. Disconnect external power and isolate the 18650 pack before fitting or moving electronics.

## Before assembly

- Print the quantities in the [printing guide](README.md), clean all support material, and dry-fit every interface.
- Print every model in PLA using the normal/default PLA profile with supports enabled. For the Power Module Mount, use the dedicated `Support for PLA` material for its support system.
- Review the [CAD index](../cad/README.md), [wiring guide](../wiring.md), and [power-system notes](../power-system.md).
- Prepare the ESP32-S3/perfboard assembly, PMS7003, GNSS board and antenna, small sensor boards, battery pack, Waveshare Solar Power Manager (D), and XL6009 module.
- Do not select fasteners, clips, or adhesive by assumption. The supplied reference does not identify an attachment method or hardware size.

## A. Weather Station Body

1. Place the main body shell upright and verify that its three side openings and internal board supports are unobstructed.
2. Fit the ESP32-S3/perfboard assembly into its internal location without pinching cables.
3. Install the small sensor boards on the sensor rod. Route their wiring through the intended openings, then fit the sensor-rod lid to stabilize the sensor installation.
4. Position the sensor rod inside the main shell with the GNSS antenna at the top, matching the supplied build evidence.
5. Fit the PMS7003 in its lower station-body location. Install the GNSS mount above it and secure the GNSS board to the mount.
6. Install the cable-slot part and organize sensor wiring so it does not obstruct the vents, lid, PMS7003 airflow, or board removal.
7. Insert three vent parts, one in each open side of the shell. Treat them as ventilation panels; weatherproof performance has not been verified.
8. Fit the lid to close the top of the shell. Confirm it seats without forcing the shell walls outward.

Station-body interior showing the sensor rod and PMS7003/GNSS area

## B. Power Module

1. Remove the power-module cover and keep the 18650 pack electrically isolated.
2. Fit the Waveshare Solar Power Manager (D) and XL6009 module on the power-module mount in the positions defined by the model.
3. Fit the 18650 battery pack in its holder area. Do not use a cell with damaged wrapping, and prevent tools or fasteners from bridging terminals.
4. Route power wiring through the modeled openings without trapping it under a board, cell holder, or cover edge.
5. Refit the cover and confirm that it closes without pressing on cells, boards, connectors, or wiring.

Open power module with battery pack and power electronics fitted

## C. Join the two assemblies

The final mechanical sequence is:

```text
Build Weather Station Body
        ↓
Install sensors/electronics
        ↓
Complete Power Module Assembly
        ↓
Position both main assemblies
        ↓
Install Connecting Base
        ↓
Join station body and power module
        ↓
Check cable clearance
        ↓
Verify mechanical fit
        ↓
Complete mechanical assembly
```

1. Place the [`connecting-base.f3d`](../cad/assembly/connecting-base.f3d) part on a flat surface and identify its pentagonal station-body side and long rectangular power-module side from the [reference preview](../cad/images/connecting-base-cad.png).
2. Seat the Weather Station Body on the matching end, then seat the Power Module on the rectangular extension.
3. Align the Power Module so it extends horizontally from the vertical station body, matching the final prototype photograph.
4. Route the inter-module cable with enough slack for service but clear of exposed edges and the base interface.
5. Do not add screws, clips, or adhesive by assumption; the supplied project evidence does not specify an attachment method.

Complete mechanical prototype — the main weather-station enclosure and power-module assembly joined using the Connecting Base

*Complete mechanical prototype — the main weather-station enclosure and power-module assembly joined using the Connecting Base.*

## Final inspection

- Both assemblies sit fully on the connecting base without rocking or visible stress.
- Lid, three vents, sensor-rod lid, and power-module cover remain seated.
- GNSS antenna and light/UV sensing surfaces are not shadowed by loose wiring.
- PMS7003 inlet/outlet and the side vents are unobstructed.
- No conductor is pinched, abraded, or able to contact a battery terminal.
- Electronics can be reached for service without destructive disassembly.

The supplied photograph verifies that the Connecting Base was printed, fit to both assemblies, and integrated into the completed bench prototype. It is not evidence of quantified tolerances, outdoor durability, or weather certification.

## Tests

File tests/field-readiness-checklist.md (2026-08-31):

# Field-Readiness Checklist

Use this record for a supervised outdoor test. Complete the blanks in a dated copy and keep private contact or access details outside the public repository.

## Test identity

| Item | Record |
| --- | --- |
| Test ID and date | |
| Repository commit | |
| Firmware environment and version | |
| Hardware, CAD and BOM revisions | |
| Approved site description | |
| Responsible authority | |
| Test lead and observers | |
| Reference instrument and status | |
| Planned start, retrieval and access windows | |

## Before deployment

- [ ] Written site permission and access route are confirmed.
- [ ] Mounting, fall zone, public contact, tamper and cable risks are reviewed.
- [ ] Weather forecast and stop thresholds are recorded.
- [ ] Battery, charging, fusing, polarity and 12 V isolation are checked.
- [ ] The enclosure is dry, closed, strain relieved and labelled.
- [ ] Credentials and precise coordinates will not enter public evidence.
- [ ] Local logging or the accepted network-loss behavior is understood.
- [ ] Sensor values and health states are plausible on the bench.
- [ ] Time, station ID, firmware version and configuration are recorded.
- [ ] The reference method, sampling interval and acceptance criteria are fixed.
- [ ] Safe de-energising and retrieval can be performed at any time.

## Stop conditions

Stop or retrieve the test if any of the following occurs:

- unsafe mounting, exposed conductor, damaged battery or overheating;
- water near energized electronics;
- severe weather outside the approved condition;
- enclosure, cable or support movement;
- repeated unexplained resets or loss of required data;
- public interference or a request from responsible site staff; or
- any observer identifies an immediate hazard.

Record who may stop the test, who authorises restart and how retrieval occurs.

## During the test

For each observation period, record:

- station and reference status;
- power state and available telemetry;
- enclosure, mounting and cable condition;
- weather and nearby disturbances;
- network outages, restarts, stale values and recoveries;
- unexpected readings or sensor disagreement; and
- action taken and person responsible.

## Retrieval and inspection

- [ ] De-energise before opening the enclosure.
- [ ] Photograph the installation and permitted evidence before removal.
- [ ] Inspect for ingress, condensation, corrosion, loose connectors and movement.
- [ ] Record final battery and physical condition.
- [ ] Preserve raw data before cleaning or transformation.
- [ ] Summarise completeness, outages, resets, stale periods and anomalies.
- [ ] Compare priority variables with the documented reference.
- [ ] Redact precise coordinates, contacts and restricted site details.

## Decision

Choose one and explain the evidence:

- [ ] Continue to the next supervised test.
- [ ] Revise named subsystems, then repeat bench tests.
- [ ] Return the complete system to the bench.
- [ ] Retain this configuration as a reference only.

**Decision, evidence and required changes:**

>

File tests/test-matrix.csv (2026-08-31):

test_id | subsystem | claim_or_requirement | acceptance_criteria | method | evidence | status | next_action
SW-001 | firmware | All tracked PlatformIO environments compile | A clean checkout builds weather_station and all five diagnostics | Automated PlatformIO matrix | .github/workflows/ci.yml | automated | Keep the matrix aligned with platformio.ini
SW-002 | backend | API validation storage migration and dashboard behavior remain compatible | All backend pytest cases pass on Python 3.11 | Automated pytest suite | backend/tests/test_api.py | automated | Add a regression test with every schema change
HW-001 | core sensing | SHT4x BMP180 BH1750 and LTR390 operate on the shared bus | Expected addresses and repeated valid readings are observed without a bus lockup | diag_i2c followed by integrated bench run | docs/milestones/v0.1-core-sensors.md | hardware verified | Add reference comparison before accuracy claims
HW-002 | particulate | PMS7003 frames are valid and integrate without stopping other sensors | Checksums pass and PM values remain available in integrated snapshots | diag_pms followed by integrated bench run | docs/milestones/v0.1-core-sensors.md | hardware verified | Record long-duration continuity in a future field configuration
NET-001 | connected system | Local upload storage API and dashboard work end to end | Station posts valid snapshots and latest/history endpoints return stored records | Trusted-LAN integration procedure | docs/milestones/v0.2-connected-iot.md | integrated verified | Add offline persistence before autonomous deployment
GNSS-001 | GNSS | TEL0157 communication no-fix and valid-fix states remain distinct | Checksum-valid data and a valid outdoor fix are observed without blocking other sensing | diag_gnss and integrated v0.3 procedure | docs/milestones/v0.3-gnss-integration.md | hardware verified | Repeat after any library or pin change
WIND-001 | wind speed | Standalone RS485 protocol returns valid calm and changing readings | Known protocol produces valid 0.0 m/s and increased values under airflow | diag_wind_speed bench procedure | docs/milestones/v0.4-wind-speed-integration.md | hardware verified | Preserve protocol and UART assumptions
WIND-002 | wind speed | Core v0.4 works with all subsystems active | Normal calm timeout reconnect API storage and dashboard behavior pass the documented 13-step procedure | Complete-station hardware test | docs/core-v0.4.md | pending | Run and record combined hardware verification
WIND-003 | wind direction | Wind direction is ready for production | Known headings map to stable values and integrate without UART conflict | Isolated protocol and controlled-heading test | firmware/src/diagnostics/diag_wind_direction.cpp | pending | Decide protocol and acceptance criteria before integration
MECH-001 | mechanical | Printed modules and connecting base assemble as documented | Parts print fit and join in the photographed configuration | Print and assembly inspection | hardware/cad/README.md | bench verified | Measure tolerances across repeated prints
MECH-002 | enclosure | Protected electronics resist defined water exposure | No water reaches protected electronics after an unpowered controlled spray and inspection | Unpowered ingress procedure | tests/field-readiness-checklist.md | pending | Define exposure and document inspection points
PWR-001 | power | Complete-system load and battery endurance are known | Measured active idle peak and subsystem currents support a versioned energy budget | Instrumented current and endurance tests | hardware/power-system.md | pending | Measure before selecting final battery and panel
SOLAR-001 | power | Solar input sustains the intended operating profile | Measured generation charging losses and load support the approved duty cycle | Outdoor or controlled irradiance energy-balance test | hardware/power-system.md | pending | Run only after PWR-001
FIELD-001 | system | The station can complete a supervised long-duration outdoor run | Approved configuration records required data with no unsafe condition unexplained reset ingress or unrecovered fault | Versioned field deployment and retrieval inspection | tests/field-readiness-checklist.md | pending | Obtain site approval reference method and responsible roles
REL-001 | release | A public release is reproducible and responsibly documented | Builds tests status evidence privacy licences limits and instructions pass independent review | Release checklist and clean-clone review | docs/release-checklist.md | pending | Complete for each tagged release

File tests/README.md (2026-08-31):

# System Tests and Validation Evidence

The backend test suite and PlatformIO builds check software behavior. The records in this folder connect those checks with bench, integration, mechanical and future field evidence.

## Evidence levels

| Level | Meaning |
| --- | --- |
| Automated | A repeatable software check runs locally and in continuous integration |
| Bench verified | Named hardware behavior was observed under a documented bench procedure |
| Integrated verified | The complete named configuration passed an end-to-end procedure |
| Field verified | A versioned configuration operated at an approved site under documented conditions |
| Pending | The acceptance procedure or required authority is not complete |

## Main records

- [`test-matrix.csv`](test-matrix.csv) links project claims to acceptance criteria, evidence and status.
- [`field-readiness-checklist.md`](field-readiness-checklist.md) controls preparation, monitoring, retrieval and review for an outdoor test.
- [`backend/tests/`](../backend/tests/) contains automated API, storage, compatibility and dashboard tests.
- [`docs/milestones/`](../docs/milestones/) contains hardware procedures and observed milestone evidence.

## Minimum content for a new test record

- test ID, date and author;
- repository commit and firmware environment;
- exact board, sensor, CAD and wiring revisions;
- equipment and reference-instrument information;
- conditions and procedure;
- acceptance criteria written before the result;
- raw data, logs, photographs or observations;
- pass, fail or inconclusive outcome; and
- the resulting Issue, revision or claim change.

Compilation is not hardware verification. A diagnostic pass is not production integration. A bench test is not evidence of outdoor reliability.

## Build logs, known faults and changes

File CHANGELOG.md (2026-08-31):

# Changelog

This file records project releases and milestone-level changes. Detailed evidence remains in [`docs/milestones/`](docs/milestones/).

## Unreleased

- Migrated the verified Core v0.4 hardware, firmware, backend, CAD and evidence into the independent public-project history.
- Rebuilt the README around the project motivation, SDG direction, real prototype, live dashboard, internal electronics, editable CAD and reproduction path.
- Added transparent provenance notes for project photographs, generated explanatory visualisations and SDG communication assets.
- Added the six-Gate project journey, system test matrix and field-readiness record.
- Added continuous integration for the backend and all firmware environments.
- Added public contribution, security, AI-use, third-party dependency and release guidance.
- Added the MIT License and reorganised the README as the repository front door.

## Core v0.4

- Integrated verified RS485 wind speed into the production firmware, JSON payload, API, SQLite storage, dashboard and history charts.
- Preserved valid calm readings as `0.0 m/s` and timeouts as unavailable.
- Kept wind direction as a separate diagnostic.
- Retained backward compatibility with v0.3 payloads and databases.
- Added editable mechanical CAD, print preparation and assembly documentation for the Weather Station Body, Power Module and Connecting Base.

## Core v0.3

- Integrated TEL0157/L76K GNSS communication, fix state, UTC, position, altitude, satellites and motion.
- Added independent GNSS diagnostics and a documented NMEA hemisphere workaround.
- Added nullable GNSS API and database fields while preserving earlier records.
- Added privacy-safe public evidence.

## Core v0.2

- Added non-blocking Wi-Fi reconnects and periodic HTTP uploads.
- Added FastAPI validation, SQLite storage and latest/history endpoints.
- Added the responsive local dashboard and backend automated tests.

## Core v0.1

- Integrated SHT4x, BMP180, BH1750, LTR390 and PMS7003 sensing.
- Added shared measurement snapshots, explicit sensor health, validation, staleness and failure counters.
- Added isolated I²C and PMS7003 diagnostics.

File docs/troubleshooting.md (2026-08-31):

# Troubleshooting

Use the smallest diagnostic that can prove the failing layer. Preserve logs, exact board/sensor revisions, wiring changes, and whether the result was compiled, bench tested, or field tested.

## First checks

1. Confirm the selected PlatformIO environment and Serial monitor speed (115200).
2. Confirm the board matches the ESP32-S3 pin allocation.
3. Check supply voltage and ground before signal wiring; never apply 5 V logic to an ESP32 GPIO.
4. Test one bus/interface with its diagnostic before modifying production firmware.
5. Return to `weather_station` only after the isolated test passes.

## I²C sensor not detected

From `firmware/`:

```powershell
pio run -e diag_i2c -t upload
pio device monitor -b 115200
```

Expected addresses are SHT4x `0x44`, BMP180 `0x77`, BH1750 `0x23` or `0x5C`, and LTR390 `0x53`.

- Verify the breakout's permitted VCC, then check VCC and GND at the module.
- Check continuity and orientation for SDA GPIO8 and SCL GPIO9.
- Inspect connectors, solder joints, and accidental bridges.
- Check that pull-ups go to 3.3 V and that the bus is not excessively long.
- If an unexpected address appears, verify the module marking and address-select state.
- Do not rewrite a sensor driver until the expected address is present on the bus.

The diagnostic scans once at startup; reset the board after a wiring change.

## I²C address passes but readings fail

- Run the integrated firmware and inspect that sensor's health counters and last error.
- Confirm the detected module matches the driver (not merely the same-looking breakout).
- Check supply stability during Wi-Fi current peaks.
- Test with shorter wiring and one sensor at a time if bus integrity is uncertain.
- For LTR390, distinguish successful raw UV reads from calibrated UV-index accuracy; the current UV index is an estimate.

## PMS7003 not reporting

```powershell
pio run -e diag_pms -t upload
pio device monitor -b 115200
```

- Confirm sensor TX connects to ESP32 RX GPIO16 and sensor RX to ESP32 TX GPIO17.
- Confirm a common ground, the sensor's required supply, UART at 9600 baud, and SET GPIO18 state.
- Inspect `Frames received`, `Checksum errors`, `Read failures`, and `Last valid frame age`.
- A valid parser result requires Plantower headers `0x42 0x4D`, the expected frame length, and a matching checksum.
- Repeated checksum failures suggest signal/wiring/framing issues; no bytes suggests power, TX/RX, or sleep-state issues.

## ESP32 cannot join Wi-Fi

- Confirm `firmware/include/secrets.h` exists and uses the macros from `secrets.example.h`.
- Re-enter the SSID/password locally; never paste credentials into an issue or commit them.
- Watch `CONNECTING`, `RETRY_WAIT`, and `CONNECTED` transitions. A failed attempt times out after 15 seconds and waits 30 seconds before retrying.
- Confirm the network is supported by the board and permits the device to join.
- Sensor reads should continue; a Wi-Fi fault is not expected to reboot or stop acquisition.

## Wi-Fi connects but the backend is unreachable

- Set `BACKEND_HOST` to the backend computer's LAN IP. Do not use `localhost` or `127.0.0.1` in ESP32 firmware.
- Start Uvicorn with `--host 0.0.0.0 --port 8000`, not a loopback-only binding.
- On another device, try `http://<BACKEND_HOST>:8000/docs` to test reachability.
- Permit inbound TCP port 8000 in the backend computer's firewall for the trusted network profile.
- Confirm the ESP32 and backend are on mutually reachable network segments.
- Institutional, guest, and some mesh Wi-Fi networks use client isolation. For development, a home router or personal hotspot that permits device-to-device traffic may be simpler.
- Do not expose the v0.3 service directly to the public internet; it has no TLS or authentication and can store precise location.

## HTTP uploads fail

- Read the Serial response code. Code `0`/negative values generally indicate no HTTP response; 4xx indicates request/schema issues; 5xx indicates backend failure.
- Open FastAPI docs at `/docs` and confirm the backend is running.
- Verify `BACKEND_PORT` and `BACKEND_ENDPOINT` match the backend.
- Check that the payload uses `weather.measurement.v1` and that unavailable sensor values are JSON `null`.
- Remember that v0.3 retains the v0.2 one-element upload queue: after recovery, new snapshots resume, but outage-period observations are not replayed.

## Dashboard has no data or shows STALE/CHECK

- Query `/api/v1/measurements/latest?station=<station-id>` directly.
- Confirm the station field in the dashboard matches uploaded `station_id` exactly.
- A 404 means no row exists for that station. A stale state means the latest stored server timestamp is old.
- `CHECK`/unavailable values can be a valid display of sensor health, not a dashboard rendering fault.
- For trends, confirm history exists inside the selected 1-hour, 24-hour, or 7-day window.

## Backend setup or test failure

The verified interpreter is Python 3.11:

```powershell
cd backend
py -3.11 -m venv .venv
.\.venv\Scripts\python.exe -m pip install -r requirements.txt
.\.venv\Scripts\python.exe -m pytest -q
```

v0.3 performs a narrow additive migration for missing GNSS columns. It does not provide a general migration framework. Use a separate disposable path for tests or manually archive the local development database; do not delete a valued database without a backup.

## GNSS has no UART data

First isolate the receiver:

```powershell
pio run -e diag_gnss -t upload
pio device monitor -b 115200
```

- Remove power before checking that the TEL0157 selector is in UART mode.
- Verify the supported supply and common ground; this project uses 3V3.
- Confirm TEL0157 TX (`D/T`) connects to ESP32 RX GPIO15 and TEL0157 RX (`C/R`) connects to ESP32 TX GPIO14.
- Confirm UART1 at 9600 baud and inspect connector/antenna seating.
- Do not modify the production GNSS worker or parser until independent UART communication is established.

## GNSS receives NMEA but has no fix

- Confirm the active antenna is firmly attached and correctly oriented.
- Test outdoors or with a genuinely clear sky view; windows and indoor locations can prevent or delay acquisition.
- Allow several minutes for a cold start and avoid repeatedly resetting a communicating receiver.
- Inspect valid-sentence and checksum-failure counters. Counts vary by run; sustained failures merit wiring/signal investigation.
- `COMMUNICATION OK - NO FIX` is distinct from `NOT CONNECTED` and should not stop other station data.

## GNSS latitude/longitude is invalid or unavailable

- Confirm a current `FIX VALID` state, at least one satellite used, and valid UTC/date.
- Check that latitude/longitude magnitude tests pass and checksum-valid NMEA supplies both hemisphere fields.
- `FIX STALE`, `COMMUNICATION OK - NO FIX`, and `NOT CONNECTED` intentionally serialize current position as `null`.
- Do not treat zero as the missing-data marker; explicit flags and nulls preserve a real zero coordinate.

## `diag_gnss` works but the main station does not

- Confirm `EnableGnss = true` in `firmware/include/app_config.h`.
- Confirm production uses UART1 GPIO15/14 and that no new component conflicts with it.
- Verify `GPSManager::begin()` runs and Serial reports the GNSS worker start.
- Inspect the structured Serial GNSS state before debugging HTTP.
- Confirm the JSON payload contains `gnss`, then check FastAPI validation and the additive SQLite columns.
- Query the latest endpoint before debugging dashboard rendering.
- Reflash `weather_station` after diagnostics; a diagnostic is a separate firmware image.

## GNSS privacy before publishing evidence

- Treat screenshots, Serial logs, API responses, SQLite exports, and issues as potential precise-location disclosures.
- Use an opaque irreversible cover and a coarse range for public screenshots; do not rely on blur or decimal truncation.
- Remove personal filesystem paths, Wi-Fi details, and backend addresses from captures.
- Keep original coordinate-bearing evidence outside the public repository.

## Diagnostic environment does not build

- Run the command from `firmware/`, where `platformio.ini` is located.
- Confirm dependencies can be installed and that only the intended environment is selected.
- Do not compile a diagnostic source alongside `main.cpp`; the existing `build_src_filter` handles this.
- When reporting a failure, include `pio run -e <environment>` output, PlatformIO version, board revision, and whether the failure is compile-, upload-, or runtime-related.

## Return to the current firmware

Diagnostics replace the application on the device. After testing, explicitly restore the current Core v0.4 firmware:

```powershell
pio run -e weather_station -t upload
pio device monitor -b 115200
```

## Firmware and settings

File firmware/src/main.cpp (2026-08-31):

#include <Arduino.h>

#include "app_config.h"
#include "communications/HttpDataUploader.h"
#include "communications/RS485Manager.h"
#include "core/I2CManager.h"
#include "core/NetworkManager.h"
#include "pins.h"
#include "sensors/GPSManager.h"
#include "sensors/PMS7003Sensor.h"
#include "sensors/SensorManager.h"

namespace
{
SensorManager environmentalSensors;
PMS7003Sensor pms7003;
GPSManager gnss;
RS485Manager rs485;
uint32_t lastEnvironmentalReadMs = 0;
uint32_t lastPmsReadMs = 0;
uint32_t lastSnapshotMs = 0;
uint32_t lastUploadScheduleMs = 0;

static_assert(AppConfig::Uart::PmsPort == 2, "PMS7003 production allocation must remain UART2");
static_assert(AppConfig::Uart::GnssPort == 1, "GNSS production allocation must remain UART1");
static_assert(AppConfig::Uart::WindSpeedPort == 0, "Production RS485 must use UART0 with USB CDC debug");

bool due(uint32_t nowMs, uint32_t lastMs, uint32_t periodMs)
{
    return lastMs == 0 || (nowMs - lastMs) >= periodMs;
}

void updatePmsHealth(WeatherData& data)
{
    const PMS7003Diagnostic diagnostic = pms7003.diagnostic();
    SensorHealth& health = data.pms7003Health;
    health.initialized = diagnostic.initialized;
    health.latestValueValid = diagnostic.latestValueValid;
    health.lastSuccessfulReadMs = diagnostic.lastValidFrameMs;
    health.consecutiveFailures = diagnostic.consecutiveFailures;
    health.totalFailures = diagnostic.readFailures + diagnostic.checksumErrors;
}

bool stale(const SensorHealth& health, uint32_t nowMs)
{
    return health.lastSuccessfulReadMs == 0 ||
           (nowMs - health.lastSuccessfulReadMs) > AppConfig::SensorStaleAfterMs;
}

void invalidateIf(bool invalid, SensorHealth& health)
{
    if (invalid && health.latestValueValid)
    {
        health.latestValueValid = false;
        ++health.consecutiveFailures;
        ++health.totalFailures;
    }
}

void validateSnapshot(WeatherData& data)
{
    invalidateIf(data.temperature < -80.0f || data.temperature > 85.0f ||
                     data.humidity < 0.0f || data.humidity > 100.0f,
                 data.sht4xHealth);
    invalidateIf(data.pressure < 300.0f || data.pressure > 1200.0f,
                 data.bmp180Health);
    invalidateIf(data.lightLux < 0.0f, data.bh1750Health);
    invalidateIf(data.pm1_0 < 0.0f || data.pm2_5 < 0.0f || data.pm10 < 0.0f ||
                     data.pm1_0 > 1000.0f || data.pm2_5 > 1000.0f || data.pm10 > 1000.0f,
                 data.pms7003Health);
}

void printValue(const char* label, float value, const char* unit, const SensorHealth& health, uint32_t nowMs)
{
    Serial.print(label);
    Serial.print(": ");
    if (!health.latestValueValid || stale(health, nowMs))
    {
        Serial.println("unavailable");
        return;
    }
    Serial.print(value, 2);
    Serial.print(" ");
    Serial.println(unit);
}

void printHealth(const char* name, SensorHealth& health, uint32_t nowMs)
{
    health.stale = stale(health, nowMs);
    Serial.print(name);
    Serial.print(": ");
    if (!health.initialized)
        Serial.print("NOT INITIALIZED");
    else if (!health.latestValueValid)
        Serial.print("READ FAILED");
    else if (health.stale)
        Serial.print("STALE");
    else
        Serial.print("OK");

    Serial.print(" (failures=");
    Serial.print(health.totalFailures);
    Serial.print(", consecutive=");
    Serial.print(health.consecutiveFailures);
    Serial.print(", last_success=");
    if (health.lastSuccessfulReadMs == 0)
        Serial.print("never");
    else
    {
        Serial.print(nowMs - health.lastSuccessfulReadMs);
        Serial.print(" ms ago");
    }
    Serial.println(")");
}

void printSnapshot()
{
    WeatherData& data = environmentalSensors.data();
    const uint32_t nowMs = millis();
    data.timestamp = nowMs;
    data.uptimeMs = nowMs;
    validateSnapshot(data);

    Serial.println();
    Serial.println("========== WEATHER SNAPSHOT ==========");
    Serial.print("Station: "); Serial.println(AppConfig::StationId);
    Serial.print("Uptime: "); Serial.print(nowMs / 1000); Serial.println(" s");
    printValue("Temperature", data.temperature, "C", data.sht4xHealth, nowMs);
    printValue("Humidity", data.humidity, "%", data.sht4xHealth, nowMs);
    printValue("Pressure", data.pressure, "hPa", data.bmp180Health, nowMs);
    printValue("Light", data.lightLux, "lux", data.bh1750Health, nowMs);
    if (data.ltr390Health.latestValueValid && !stale(data.ltr390Health, nowMs))
    {
        Serial.print("UV raw: "); Serial.println(data.uvRaw);
        Serial.print("UV index estimate: "); Serial.println(data.uvIndex, 2);
    }
    else
        Serial.println("UV: unavailable");
    printValue("PM1.0", data.pm1_0, "ug/m3", data.pms7003Health, nowMs);
    printValue("PM2.5", data.pm2_5, "ug/m3", data.pms7003Health, nowMs);
    printValue("PM10", data.pm10, "ug/m3", data.pms7003Health, nowMs);

    Serial.println();
    Serial.println("Wind:");
    printValue("Wind Speed", data.windSpeed, "m/s", data.windSpeedHealth, nowMs);

    Serial.println();
    Serial.println("Sensor Health:");
    printHealth("SHT4x", data.sht4xHealth, nowMs);
    printHealth("BMP180", data.bmp180Health, nowMs);
    printHealth("BH1750", data.bh1750Health, nowMs);
    printHealth("LTR390", data.ltr390Health, nowMs);
    printHealth("PMS7003", data.pms7003Health, nowMs);
    data.windSpeedHealth.stale = stale(data.windSpeedHealth, nowMs);
    Serial.print("Wind Speed: ");
    if (!data.windSpeedHealth.initialized)
        Serial.print("NOT CONNECTED");
    else if (data.windSpeedHealth.stale && data.windSpeedHealth.latestValueValid)
        Serial.print("STALE");
    else if (!data.windSpeedHealth.latestValueValid)
    {
        if (data.windSpeedLastModbusResult == 0xE2)
            Serial.print("MODBUS TIMEOUT");
        else
            Serial.print("MODBUS ERROR");
    }
    else
        Serial.print("OK");
    Serial.print(" (failures=");
    Serial.print(data.windSpeedHealth.totalFailures);
    Serial.print(", consecutive=");
    Serial.print(data.windSpeedHealth.consecutiveFailures);
    Serial.println(")");

    Serial.println();
    gnss.printStatus();

    const UploadStatus upload = HttpDataUploader::status();
    Serial.println();
    Serial.println("Network:");
    Serial.print("Wi-Fi: "); Serial.println(Core::NetworkManager::stateName());
    if (Core::NetworkManager::isWiFiConnected())
    {
        Serial.print("IP: "); Serial.println(Core::NetworkManager::ipAddress());
    }
    Serial.print("NTP: ");
    Serial.println(Core::NetworkManager::isTimeSynced() ? "SYNCED" : "NOT SYNCED");
    Serial.print("Last upload: ");
    if (upload.lastSuccessfulUploadMs == 0)
        Serial.println("never");
    else
    {
        Serial.print((nowMs - upload.lastSuccessfulUploadMs) / 1000);
        Serial.println(" s ago");
    }
    Serial.print("Uploads: "); Serial.print(upload.successfulUploads); Serial.print(" successful, ");
    Serial.print(upload.failedUploads); Serial.print(" failed (consecutive=");
    Serial.print(upload.consecutiveFailures); Serial.print(", last_http=");
    Serial.print(upload.lastHttpResponseCode); Serial.println(")");
    Serial.println("Deferred: wind direction, rain, battery, solar");
    Serial.println("======================================");
}
}

void setup()
{
    Serial.begin(AppConfig::SerialBaud);
    delay(800);
    Serial.println();
    Serial.println(AppConfig::FirmwareName);
    Serial.println("Active: I2C environmental sensors + PMS7003 + GNSS + RS485 wind speed");

    if (AppConfig::EnableI2cSensors)
    {
        Core::I2CManager::begin();
        Core::I2CManager::scanBus();
        environmentalSensors.begin();
    }
    if (AppConfig::EnablePms7003)
    {
        pms7003.begin();
        updatePmsHealth(environmentalSensors.data());
    }
    if (AppConfig::EnableGnss)
    {
        gnss.begin(environmentalSensors.data());
        Serial.println("GNSS worker started; acquisition is isolated from the main scheduler.");
    }
    if (AppConfig::EnableRs485Wind)
    {
        rs485.begin(true);
        Serial.println("RS485 wind-speed acquisition initialized independently of other sensors.");
    }
    Serial.println("Sensor initialization complete; failed sensors will be retried by the scheduler.");

    Core::NetworkManager::begin();
    HttpDataUploader::begin();
    Serial.println("Network services started independently of sensor acquisition.");
}

void loop()
{
    const uint32_t nowMs = millis();
    Core::NetworkManager::tick();
    if (AppConfig::EnableGnss)
        gnss.update();
    if (AppConfig::EnableRs485Wind)
        rs485.update(environmentalSensors.data());
    if (AppConfig::EnableI2cSensors && due(nowMs, lastEnvironmentalReadMs, AppConfig::EnvironmentalPeriodMs))
    {
        lastEnvironmentalReadMs = nowMs;
        environmentalSensors.read();
    }
    if (AppConfig::EnablePms7003 && due(nowMs, lastPmsReadMs, AppConfig::PmsPeriodMs))
    {
        lastPmsReadMs = nowMs;
        pms7003.read(environmentalSensors.data(), AppConfig::PmsReadTimeoutMs);
        updatePmsHealth(environmentalSensors.data());
    }
    if (due(nowMs, lastSnapshotMs, AppConfig::SnapshotPeriodMs))
    {
        lastSnapshotMs = nowMs;
        printSnapshot();
    }
    if (due(nowMs, lastUploadScheduleMs, AppConfig::UploadPeriodMs))
    {
        lastUploadScheduleMs = nowMs;
        WeatherData& data = environmentalSensors.data();
        if (AppConfig::EnableGnss)
            gnss.update();
        if (AppConfig::EnableRs485Wind)
            rs485.update(data);
        data.uptimeMs = nowMs;
        validateSnapshot(data);
        HttpDataUploader::enqueue(data);
    }
    delay(5);
}

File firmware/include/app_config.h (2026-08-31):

#pragma once

#include <stdint.h>

// Central compile-time configuration for the current hardware milestone.
namespace AppConfig
{
constexpr const char* StationId = "ws-esp32s3-001";
constexpr const char* FirmwareName = "IoT Solar Weather Station - Core v0.4";

constexpr uint32_t SerialBaud = 115200;
constexpr uint32_t I2cClockHz = 100000;
constexpr uint32_t EnvironmentalPeriodMs = 5000;
constexpr uint32_t PmsPeriodMs = 10000;
constexpr uint32_t SnapshotPeriodMs = 10000;
constexpr uint32_t UploadPeriodMs = 60000;
constexpr uint32_t PmsReadTimeoutMs = 1500;
constexpr uint32_t SensorStaleAfterMs = 30000;
constexpr uint32_t GnssUpdatePeriodMs = 10000;
constexpr uint32_t GnssFixStaleAfterMs = 30000;
constexpr uint32_t GnssCommunicationTimeoutMs = 30000;
constexpr uint32_t GnssProbeRetryPeriodMs = 60000;
constexpr uint32_t WindSpeedPeriodMs = 2000;
constexpr uint32_t WifiConnectTimeoutMs = 15000;
constexpr uint32_t WifiRetryPeriodMs = 30000;
constexpr uint32_t HttpConnectTimeoutMs = 3000;
constexpr uint32_t HttpReadTimeoutMs = 5000;

constexpr bool EnableI2cSensors = true;
constexpr bool EnablePms7003 = true;
constexpr bool EnableGnss = true;
constexpr bool EnableRs485Wind = true;
constexpr bool EnableRain = false;
constexpr bool EnablePowerTelemetry = false;
constexpr bool EnableWifi = true;

namespace Uart
{
constexpr int PmsPort = 2;
constexpr uint32_t PmsBaud = 9600;
constexpr int GnssPort = 1;
constexpr uint32_t GnssBaud = 9600;

// The verified standalone diagnostic uses UART1. Production overrides this to
// UART0 while its debug Serial console runs over native USB CDC, leaving UART1
// for GNSS and UART2 for PMS7003.
#ifndef WIND_SPEED_UART_PORT
#define WIND_SPEED_UART_PORT 1
#endif
constexpr int WindSpeedPort = WIND_SPEED_UART_PORT;
constexpr int WindDirectionPort = 2;
constexpr uint32_t WindBaud = 4800;
}

constexpr float RainMmPerTip = 0.2794f;
}

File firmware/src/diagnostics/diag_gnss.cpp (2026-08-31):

#include <Arduino.h>
#include <DFRobot_GNSS.h>

#include "app_config.h"
#include "pins.h"
#include "sensors/GnssNmeaHemisphere.h"

namespace
{
constexpr uint32_t StatusPeriodMs = 10000;
constexpr uint32_t RetryPeriodMs = 15000;
constexpr uint32_t RawCaptureDurationMs = 15000;
constexpr uint32_t RawPollPeriodMs = 3000;
constexpr uint8_t InitialAttempts = 3;
constexpr eGnssMode_t RequestedMode = eGPS_BeiDou_GLONASS;

HardwareSerial gnssSerial(AppConfig::Uart::GnssPort);
// DFRobot's public declaration takes RX then TX. Its implementation uses
// confusing internal names, but forwards argument 3 to HardwareSerial RX and
// argument 4 to HardwareSerial TX. Do not reverse these working project pins.
DFRobot_GNSS_UART gnss(&gnssSerial, AppConfig::Uart::GnssBaud,
                       Pins::GPS_RX, Pins::GPS_TX);

bool communicationOk = false;
uint32_t lastStatusMs = 0;
uint32_t lastRetryMs = 0;
String command;
uint32_t rawByteCount = 0;
bool rawCaptureActive = false;
uint32_t rawCaptureEndMs = 0;
uint32_t nextRawPollMs = 0;
GnssNmeaHemisphere nmeaHemisphere;

const char* modeText(uint8_t mode)
{
    switch (mode)
    {
    case eGPS:
        return "GPS";
    case eBeiDou:
        return "BeiDou";
    case eGPS_BeiDou:
        return "GPS + BeiDou";
    case eGLONASS:
        return "GLONASS";
    case eGPS_GLONASS:
        return "GPS + GLONASS";
    case eBeiDou_GLONASS:
        return "BeiDou + GLONASS";
    case eGPS_BeiDou_GLONASS:
        return "GPS + BeiDou + GLONASS";
    default:
        return "unknown";
    }
}

double signedLatitude(const sLonLat_t& latitude, char hemisphere)
{
    return hemisphere == 'S' ? -latitude.latitudeDegree
                              : latitude.latitudeDegree;
}

double signedLongitude(const sLonLat_t& longitude, char hemisphere)
{
    return hemisphere == 'W' ? -longitude.lonitudeDegree
                              : longitude.lonitudeDegree;
}

bool validLatitudeMagnitude(const sLonLat_t& latitude)
{
    return latitude.latDD <= 90 && latitude.latMM < 60 &&
           latitude.latMMMMM < 100000 && isfinite(latitude.latitudeDegree) &&
           latitude.latitudeDegree >= 0.0 && latitude.latitudeDegree <= 90.0;
}

bool validLongitudeMagnitude(const sLonLat_t& longitude)
{
    return longitude.lonDDD <= 180 && longitude.lonMM < 60 &&
           longitude.lonMMMMM < 100000 &&
           isfinite(longitude.lonitudeDegree) &&
           longitude.lonitudeDegree >= 0.0 &&
           longitude.lonitudeDegree <= 180.0;
}

bool validDate(const sTim_t& date)
{
    return date.year >= 2000 && date.year <= 2099 && date.month >= 1 &&
           date.month <= 12 &&
           date.date >= 1 && date.date <= 31;
}

bool validUtcFields(const sTim_t& utc)
{
    // Midnight (00:00:00) is valid; never require a nonzero UTC component.
    return utc.hour <= 23 && utc.minute <= 59 && utc.second <= 60;
}

void printTwoDigits(uint8_t value)
{
    if (value < 10)
    {
        Serial.print('0');
    }
    Serial.print(value);
}

void printBootHeader()
{
    Serial.println();
    Serial.println("========================================");
    Serial.println("DIAGNOSTIC FIRMWARE - DFRobot Gravity GNSS");
    Serial.println("========================================");
    Serial.println("Module target: TEL0157 / Quectel L76K");
    Serial.println("Library: DFRobot_GNSS 1.0.0");
    Serial.println("Interface: UART (module selector must be UART)");
    Serial.print("UART number: ");
    Serial.println(AppConfig::Uart::GnssPort);
    Serial.print("Baud: ");
    Serial.println(AppConfig::Uart::GnssBaud);
    Serial.print("ESP32 RX: GPIO");
    Serial.println(Pins::GPS_RX);
    Serial.print("ESP32 TX: GPIO");
    Serial.println(Pins::GPS_TX);
    Serial.println("Stage A - UART initialization: starting");
}

bool detectAndConfigure()
{
    Serial.println("Stage B - DFRobot library communication: probing device");
    if (!gnss.begin())
    {
        communicationOk = false;
        Serial.println("GNSS DEVICE NOT DETECTED");
        Serial.println("Fix state: NO COMMUNICATION");
        return false;
    }

    communicationOk = true;
    Serial.println("GNSS communication: OK");
    Serial.println("Stage C - Module power/configuration");
    gnss.enablePower();
    Serial.println("Power enable command: SENT");
    gnss.setGnss(RequestedMode);
    const uint8_t mode = gnss.getGnssMode();
    Serial.print("GNSS mode readback: ");
    Serial.print(modeText(mode));
    Serial.print(" (");
    Serial.print(mode);
    Serial.println(")");
    if (mode != RequestedMode)
    {
        Serial.println("WARNING: requested GNSS mode was not confirmed");
    }
    Serial.println("Stage D - Periodic module data reads enabled");
    Serial.println("Commands: raw = 15 s raw GNSS/NMEA capture, status = read now, help");
    return true;
}

const char* fixState(bool fixValid)
{
    if (!communicationOk)
    {
        return "NO COMMUNICATION";
    }
    if (!fixValid)
    {
        return "COMMUNICATION OK - NO FIX";
    }
    return "FIX VALID";
}

void printDirection(const char direction)
{
    const uint8_t byteValue = static_cast<uint8_t>(direction);
    Serial.print("  direction byte: ");
    Serial.print(byteValue);
    Serial.print(" (0x");
    if (byteValue < 0x10)
    {
        Serial.print('0');
    }
    Serial.print(byteValue, HEX);
    Serial.println(')');
    Serial.print("  direction char: ");
    if (direction >= 32 && direction <= 126)
    {
        Serial.println(direction);
    }
    else
    {
        Serial.println("<not printable>");
    }
}
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

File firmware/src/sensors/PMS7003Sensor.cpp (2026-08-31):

#include "PMS7003Sensor.h"

#include "core/SerialPrintManager.h"
#include "pins.h"

namespace
{
constexpr uint8_t FrameHeader1 = 0x42;
constexpr uint8_t FrameHeader2 = 0x4D;
constexpr uint16_t ExpectedFrameLength = 28;
}

void PMS7003Sensor::begin()
{
    pinMode(Pins::PMS_SLEEP, OUTPUT);
    wake();
    pmsSerial_.begin(AppConfig::Uart::PmsBaud, SERIAL_8N1, Pins::PMS_RX, Pins::PMS_TX);
    initialized_ = true;
    lastError_ = "";

    Serial.print("PMS7003 initialized on RX GPIO");
    Serial.print(Pins::PMS_RX);
    Serial.print(", TX GPIO");
    Serial.print(Pins::PMS_TX);
    Serial.print(", SET GPIO");
    Serial.print(Pins::PMS_SLEEP);
    Serial.print(", baud ");
    Serial.println(AppConfig::Uart::PmsBaud);
}

bool PMS7003Sensor::read(WeatherData& data, uint32_t timeoutMs)
{
    if (!initialized_)
    {
        latestValueValid_ = false;
        ++readFailures_;
        ++consecutiveFailures_;
        lastError_ = "PMS7003 not initialized";
        return false;
    }

    if (!awake_)
    {
        latestValueValid_ = false;
        ++readFailures_;
        ++consecutiveFailures_;
        lastError_ = "PMS7003 is asleep";
        return false;
    }

    uint8_t frame[FrameSize] = {};
    if (!readFrame(frame, timeoutMs))
    {
        latestValueValid_ = false;
        ++readFailures_;
        ++consecutiveFailures_;
        return false;
    }

    data.pm1_0Standard = readUint16(frame, 4);
    data.pm2_5Standard = readUint16(frame, 6);
    data.pm10Standard = readUint16(frame, 8);
    data.pm1_0Atmospheric = readUint16(frame, 10);
    data.pm2_5Atmospheric = readUint16(frame, 12);
    data.pm10Atmospheric = readUint16(frame, 14);

    data.pm1_0 = data.pm1_0Atmospheric;
    data.pm2_5 = data.pm2_5Atmospheric;
    data.pm10 = data.pm10Atmospheric;
    data.timestamp = millis();

    ++framesReceived_;
    consecutiveFailures_ = 0;
    lastValidFrameMs_ = millis();
    latestValueValid_ = true;
    lastError_ = "";
    return true;
}

void PMS7003Sensor::wake()
{
    digitalWrite(Pins::PMS_SLEEP, HIGH);
    awake_ = true;
}

void PMS7003Sensor::sleep()
{
    digitalWrite(Pins::PMS_SLEEP, LOW);
    awake_ = false;
}

void PMS7003Sensor::printStatus() const
{
    Core::SerialPrintManager::Lock serialLock;

    const PMS7003Diagnostic diag = diagnostic();

    Serial.println("----- PMS7003 Status -----");
    Serial.print("Initialized: ");
    Serial.println(diag.initialized ? "yes" : "no");
    Serial.print("Awake: ");
    Serial.println(diag.awake ? "yes" : "no");
    Serial.print("Frames received: ");
    Serial.println(diag.framesReceived);
    Serial.print("Checksum errors: ");
    Serial.println(diag.checksumErrors);
    Serial.print("Read failures: ");
    Serial.println(diag.readFailures);
    Serial.print("Last valid frame age: ");
    if (diag.lastValidFrameMs > 0)
    {
        Serial.print(millis() - diag.lastValidFrameMs);
        Serial.println(" ms");
    }
    else
    {
        Serial.println("never");
    }
    Serial.print("SET pin state: ");
    Serial.println(diag.awake ? "HIGH" : "LOW");
    Serial.print("Last error: ");
    Serial.println(diag.lastError[0] == '\0' ? "none" : diag.lastError);
    Serial.println("--------------------------");
}

PMS7003Diagnostic PMS7003Sensor::diagnostic() const
{
    return {initialized_, framesReceived_, checksumErrors_, readFailures_, consecutiveFailures_, lastValidFrameMs_, latestValueValid_, awake_, lastError_};
}

bool PMS7003Sensor::readFrame(uint8_t* frame, uint32_t timeoutMs)
{
    const uint32_t startMs = millis();
    size_t index = 0;

    while ((millis() - startMs) < timeoutMs)
    {
        while (pmsSerial_.available() > 0)
        {
            const int value = pmsSerial_.read();
            if (value < 0)
            {
                continue;
            }

            const uint8_t byteValue = static_cast<uint8_t>(value);

            if (index == 0 && byteValue != FrameHeader1)
            {
                continue;
            }

            if (index == 1 && byteValue != FrameHeader2)
            {
                index = 0;
                continue;
            }

            frame[index] = byteValue;
            ++index;

            if (index == FrameSize)
            {
                if (!validateFrame(frame))
                {
                    ++checksumErrors_;
                    lastError_ = "PMS7003 checksum or frame validation failed";
                    index = 0;
                    continue;
                }

                return true;
            }
        }

        delay(1);
    }

    lastError_ = "PMS7003 read timeout";
    return false;
}

bool PMS7003Sensor::validateFrame(const uint8_t* frame)
{
    if (frame[0] != FrameHeader1 || frame[1] != FrameHeader2)
    {
        return false;
    }

    if (readUint16(frame, 2) != ExpectedFrameLength)
    {
        return false;
    }

    uint16_t checksum = 0;
    for (size_t i = 0; i < FrameSize - 2; ++i)
    {
        checksum += frame[i];
    }

    return checksum == readUint16(frame, FrameSize - 2);
}

uint16_t PMS7003Sensor::readUint16(const uint8_t* frame, size_t index) const
{
    return (static_cast<uint16_t>(frame[index]) << 8) | frame[index + 1];
}

void PMS7003Sensor::flushInput()
{
    while (pmsSerial_.available() > 0)
    {
        pmsSerial_.read();
    }
}

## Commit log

2026-08-18 Create v0.1 engineering project foundation
    [bom.csv, test-matrix.csv]
2026-08-18 Import project baselines and solution landscape (#8)
    [bom.csv, test-matrix.csv]
2026-08-18 Define exemplar stakeholder and concept strategy (#9)
    [concept-selection-matrix.csv]
2026-08-18 Complete Gate A instructor decision interview (#14)
    Record the full stakeholder interview, decision and claim boundaries, reference strategy, requirements, tests and field-readiness checklist.
    Issue #3 remains open for Gates B–E.
    [test-matrix.csv]
2026-08-18 Complete Gate B TA workflow interview and operations pack (#16)
    Record the confirmed TA workflow evidence, add concise field operations guidance, and preserve supervised dry-run, site, reference and decision gates as open work.
    [test-matrix.csv]
2026-08-18 Add Gate C site pack and synthetic teaching example (#18)
    Add the Gate C workflow, official enquiry route and a clearly labelled fictional conditional-site example while keeping real site evidence and permission open.
    [test-matrix.csv]
2026-08-18 Add Gate D and provisional Gate E workshop (#20)
    Add the synthetic tabletop case, instructor revise decision and provisional hybrid strategy while keeping independent TA alignment and final re-score evidence open.
    [test-matrix.csv]
2026-08-18 Complete Gate A–E teaching preview (#22)
    Add the student-facing A–E overview, synthetic Gate D role-play/alignment, and Gate E sensitivity workshop while preserving real-evidence boundaries.
    [test-matrix.csv]
2026-08-18 Record completed A–E course sync (#23)
    Pair the merged project and course baselines and preserve the real-evidence boundary.
2026-08-18 Build complete v0.2 teaching-preview baseline (#24)
    Connect sensor selection, planning BOM, synthetic energy model, integrated configuration, reproducible 72-hour preview and evidence-integrity checks without claiming physical validation.
    [bom.csv, daily-observations.csv, power-profile.csv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]
2026-08-31 Publish the verified Solar Weather Station project
    [bom.csv, cable-slot.f3d, concept-selection-matrix.csv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]
2026-09-01 docs: replace prototype image reference with cover.png
